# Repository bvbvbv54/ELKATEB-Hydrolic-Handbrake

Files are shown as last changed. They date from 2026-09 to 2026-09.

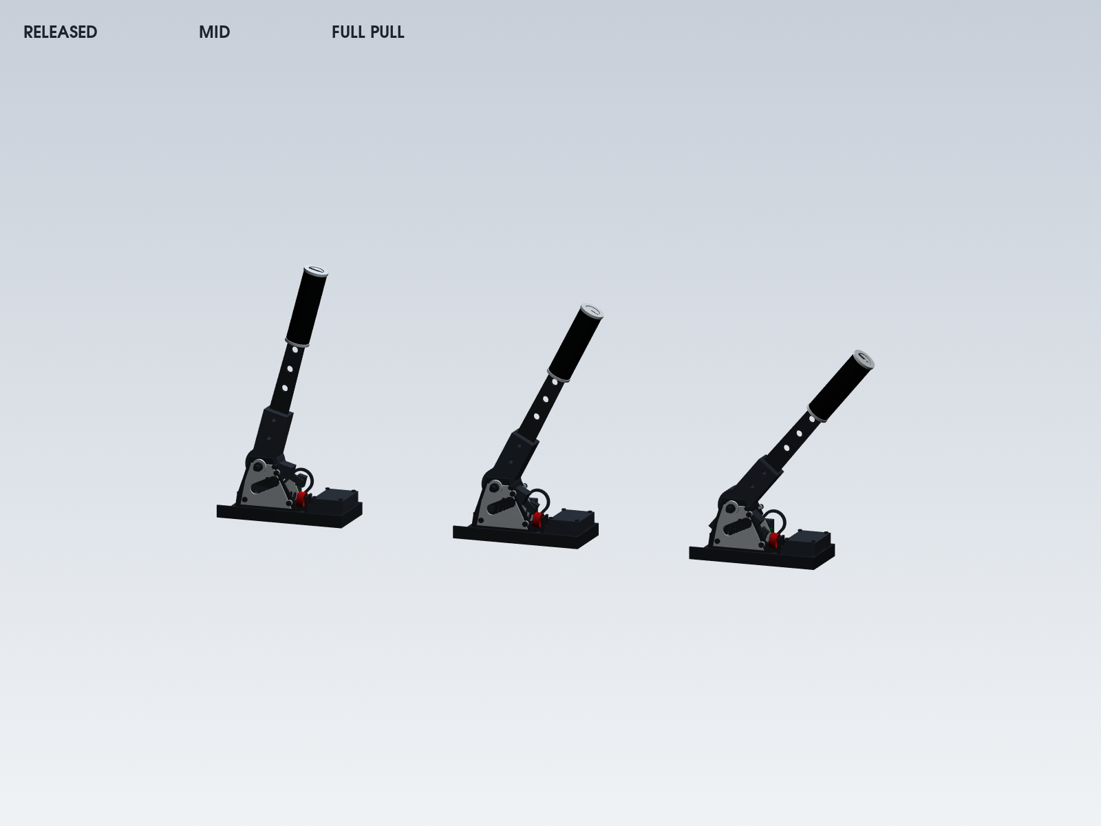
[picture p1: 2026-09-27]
prototype_commercial_v1/renders/17_MOTION_STATES.png

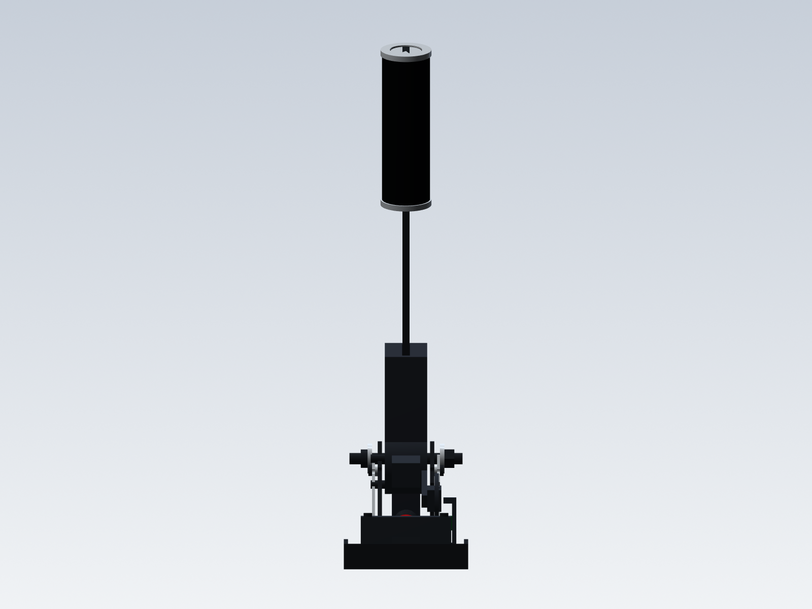
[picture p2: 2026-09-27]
prototype_commercial_v1/renders/06_REAR.png

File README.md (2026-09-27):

# ELKATEB Sim-Racing Handbrake

Original low-cost sim-racing handbrake development project using a dual-608/M8 pivot, steel lever, extension spring, independent mechanical stops, and contactless Hall-effect position sensing.

## Current designs

- `prototype_p1/` - mostly 3D-printed physical validation prototype. Print and measure the eight calibration coupons before regenerating structural parts.
- `prototype_commercial_v1/` - P1-C Commercial Alpha using laser-cut/bent steel, aluminium accents, hidden magnetic sensing, removable desk clamp, and independent rig mounting.
- `analysis_generated/` - evidence-based engineering audit and reusable measurements. Downloaded reference CAD is deliberately excluded from this repository because its redistribution/commercial rights were not established.

## P1 build order

1. Print all eight files under `prototype_p1/coupons/`.
2. Measure the actual bearings, bolts, nuts, magnet, sensor board, and printed coupon fits.
3. Update calibration-dependent parameters in `prototype_p1/src/parameters.py`.
4. Regenerate P1.1 with `prototype_p1/build.ps1`.
5. Print the 19 functional parts and assemble them with the specified steel lever, reinforcement strips, bearings, and metric hardware.

P1.0 and P1-C are engineering prototypes. CAD checks do not establish production strength, fatigue life, electrical compliance, or commercial safety. Follow the included test plans and perform progressive physical validation.

Purchasing documents:

- Short shop-ready list with totals and coupon folder: `output/pdf/P1_BUY_LIST_SUMMARY_TUNISIA.pdf`
- Detailed Tunisia purchasing/calibration guide: `output/pdf/P1_TUNISIA_PURCHASE_GUIDE.pdf`

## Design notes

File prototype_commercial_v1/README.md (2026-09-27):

# P1-C Commercial Alpha

Original cost-conscious commercial prototype derived from the P1.0 engineering baseline and the three user-supplied concept renders. P1.0 is preserved; `2739` files are recorded by SHA-256 in `reports/p1_baseline_hashes.json`.

Core envelope: **190 × 88 mm base**, M8 pivot at **X58 / Z76 mm**, 25° lever travel, two 608 bearings, 5 mm steel lever, 3 mm steel chassis, 2 mm aluminium accents, removable M10 desk clamp, and independent M6 rig slots.

Build with `./build.ps1`. The source of truth is `src/parameters.py`.

Status: CAD VERIFIED where shown. Manufacturing fits, magnetic response, finish, stiffness, fatigue, and clamp holding remain PHYSICAL TEST REQUIRED / SUPPLIER QUOTE REQUIRED.

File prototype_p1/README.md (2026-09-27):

# Prototype P1.0 — printable mechanical validation platform

P1.0 is an original, low-cost vertical/diagonal sim-racing handbrake prototype. It is a mechanical test platform, not a production-ready consumer product. The generated B-Rep assembly uses a drilled steel lever, a fixed M8 pivot, two 608 bearings, a simple extension spring, independent mechanical stops, a moving magnet with stationary Hall board, independent rig slots, and a removable M10 desk clamp.

## Start here

1. Inspect `renders/01_ISOMETRIC_ASSEMBLY.png`, `renders/08_PIVOT_SECTION.png`, and `step/P1_ASSEMBLY.step`.
2. Print the eight `coupons/*.stl` files before structural parts.
3. Measure the actual 608 bearings, steel bar, magnet, M8 bolt shank, coupling nut, sensor board, and Pro Micro assembly.
4. Record the coupon selections and update `src/parameters.py`.
5. Regenerate with `powershell -ExecutionPolicy Bypass -File prototype_p1/build.ps1`.
6. Print the mechanical core before the clamp or electronics modules.

The generated geometry passed the checks in `reports/GEOMETRY_VALIDATION.md` and the 90-file round-trip in `reports/EXPORT_ROUNDTRIP.md`. Printed strength and fit remain physical-test items.

## Actual P1.0 geometry

- Base: 180 x 84 x 10 mm.
- Pivot centre: X=50, Y=42, Z=76 mm in the assembly coordinate system.
- Tower inner gap: 32 mm; each tower is 18 mm thick; outer span is 68 mm.
- Rotating hub: 28 mm axial width, 48 mm bearing barrel diameter, two 22.2 x 7.2 mm nominal pockets.
- Bearings: 2 x 608, 8 x 22 x 7 mm; two more are recommended as fit/test spares.
- Pivot: M8x90 candidate. The smooth shank must cover both bearing inner races; verify the purchased bolt.
- Steel lever: 25 x 5 x 280 mm stock; pivot-to-grip-centre lever arm is 245 mm.
- Released/mid/full angles: 75 / 62.5 / 50 degrees, giving 25 degrees active travel.
- Grip: 34 mm diameter x 110 mm long.
- Spring hook-centre distances: 69.76 / 77.97 / 85.82 mm through the three states.
- Hall centre distance: 23.99 / 12.63 / 5.02 mm; the magnet approaches monotonically toward full pull.
- Electronics enclosure: 50 x 38 x 28 mm body plus 5 mm cover envelope.
- Rig slots: two 44 x 7 mm longitudinal slots, centred at X=136 and Y=32/52 mm.
- Clamp: 60 mm throat, M10x100 screw candidate, 10–55 mm desk range, 46 mm lower pad.
- Released unclamped assembly envelope: 180 x 96 x 370.18 mm including protruding hardware.
- Full-pull unclamped envelope: 255.86 x 96 x 316.74 mm.

## Parts to print

|ID|Part|Recommended orientation|Support guidance|
|---|---|---|---|
|P1-001|Base|top face on bed; steel recesses upward|none|
|P1-002|Left pivot support|outer Y face on bed|none; ream holes after print|
|P1-003|Right pivot support|outer Y face on bed|none|
|P1-004|Bearing hub|one bearing face on bed|support only inside accessible lever slot if bridging is poor|
|P1-006|Grip|upright on end with brim|none; drill/ream retaining bore|
|P1-007|Spring anchor module|foot on bed|none|
|P1-008/009|Stop blocks|outer Y face on bed|none|
|P1-010|Magnet holder|inner arm face on bed|small local support may be required at cup|
|P1-011A/B|Hall bracket and sled|largest flat face on bed|inspect rail bridges|
|P1-012|Electronics enclosure|bottom on bed|none|
|P1-013|Electronics cover|outer top face on bed|none|
|P1-020|Clamp interface|large face on bed|none|
|P1-021|Clamp vertical bracket|large X face on bed|none; orient ribs upward|
|P1-022|Clamp screw guide|lower arm face on bed|none; hex pocket vertical|
|P1-023|Clamp knob|flat face on bed|none|
|P1-024|Swivel-pad holder|flat face on bed|none|
|P1-025|Upper-pad holder|large face on bed|none|

Initial slicer baseline: PETG, 0.4 mm nozzle, 0.20 mm layer, 5–6 perimeters, 6 top/bottom layers, 40–60% infill. Use higher local wall count around pivot, stop, spring, and clamp bores. Do not substitute 100% infill for correct orientation and hardware.

## Steel fabrication

### Lever P1-005

Cut 25 x 5 mm steel flat bar to 280 mm. Hole centres are measured from the lower raw-bar end and across the 25 mm width centreline:

- X=16 mm: Ø6.6 mm, first hub clamp bolt.
- X=40 mm: Ø6.6 mm, second hub clamp bolt.
- X=190 mm: Ø4.5 mm, grip retaining bolt.

Use `dxf/P1-005_STEEL_LEVER_TEMPLATE.dxf` or `drawings/P1-005_STEEL_LEVER_DIMENSIONS.svg`. Deburr every edge and hole. Confirm actual bar width/thickness before printing P1-004 and P1-006.

### Backing strips P1-030/P1-031

Cut two strips, each 180 x 25 x 3 mm. Drill Ø6.6 mm holes at X=32, 68, 125, and 165 mm on the 12.5 mm centreline. These strips sit in the base underside recesses and carry the pivot-tower and clamp-interface through-bolts.

## Assembly order

1. Fit the two steel backing strips into the base underside recesses.
2. Through-bolt both pivot supports to the base/backing strips; do not crush PETG.
3. Press or slip-fit one 608 into each open hub face according to the coupon result.
4. Place the 13.6 mm centre spacer between inner races. Build a measured 2.2 mm axial spacer stack between each tower and adjacent inner race; use steel washers plus precision shims or cut spacer tubes, not PETG.
5. Insert the steel lever 56 mm into the hub socket and install two M6 through-bolts with washers and nylocs.
6. Install the M6 moving spring pin and M6 stop pin in the hub.
7. Put the hub between towers. Pass the M8 smooth shank through left tower, washer, first bearing, spacer, second bearing, washer, and right tower. Tighten the nyloc only enough to clamp the inner-race stack without tower distortion.
8. Bolt on both stop blocks and adjust their M6 rubber-tipped screws to touch the stop pin at 75° and 50°.
9. Bolt the spring module to the base. Install a light extension spring between steel anchors only after the no-spring motion test passes.
10. Slide the grip over the bar and retain it with the M4 cross-bolt.
11. Install the magnet carrier and keeper screw. Keep the magnet out during first mechanical load tests.
12. Install the Hall fixed bracket, sliding sled, and board. Start at 5 mm nominal face gap.
13. Install the Pro Micro enclosure and route the Hall cable away from moving parts.
14. For desk mode, attach the clamp interface with four M6 through-bolts, join the vertical bracket and screw guide, insert the real M10 coupling nut/screw, then fit pad and knob.
15. For rig mode, remove the entire clamp and use the two 44 x 7 mm base slots with large washers.

## First mechanical test

Move the core by hand with no spring and no electronics. Confirm free bearing rotation, positive stop contact, and no bar/tower contact. Add the lightest spring. Use a luggage scale at grip centre and step through 25, 50, 75, then 100 N while inspecting the items in `TEST_PLAN.md`. Stop immediately at cracking, whitening, permanent movement, or fastener loosening.

## Regeneration

CadQuery 2.8 and its small Python dependencies are project-local under `.tools/`; OpenCascade and analysis libraries are reused read-only from `analysis_generated/python_packages`.

```powershell
powershell -ExecutionPolicy Bypass -File prototype_p1/build.ps1
```

The source of truth is `src/parameters.py`. Do not edit exported STEP/STL files by hand.

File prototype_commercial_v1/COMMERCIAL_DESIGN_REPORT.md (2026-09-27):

# Commercial design report

## Executive result

P1-C replaces the printed P1 chassis with a sheet-metal architecture while preserving its proven kinematic principles. The visible product is black powder-coated steel, brushed aluminium, a black grip, and one red spring collar. Internal printed parts are serviceable and visually screened.

## Final CAD dimensions

- Base: 190 × 88 × 18 mm folded envelope.
- Complete released-state CAD envelope: 190 × 88 × 371.4 mm.
- Complete full-pull CAD envelope: 265.3 × 88 × 318.2 mm; the grip sweeps beyond the base length.
- Pivot centre: X58, Y44, Z76 mm.
- Side-frame inner gap: 34 mm.
- Rotating hub: 30 mm wide, Ø50 mm main body.
- Bearings: 2 × 608, nominal 8 × 22 × 7 mm.
- Lever: 5 mm steel, 300 mm pivot-to-end, three Ø10 lightening holes outside the root; nominal hand radius 245 mm.
- Grip: Ø34 × 112 mm over Ø22 mm core.
- Travel: 75° released to 50° full pull.
- Desk range: 10–55 mm; clamp throat 65 mm; M10 × 120 candidate.
- Electronics pod: 54 × 64 × 30 mm nominal outer envelope.

## Materials and processes

- Steel: base tray, left/right structural frames, lever, spring bracket, clamp bracket.
- Aluminium: left/right non-structural accent panels; commodity grip core representation.
- Printed: hub, magnet carrier, Hall window, Hall sled, electronics pod/lid, cable guide, knob, pad carrier, spring collar.
- Purchased: pivot bolt, bearings, spacers/washers, spring, grip, M3/M4/M6 hardware, M10 clamp hardware, magnet, Hall board, controller, USB.

## Mass and sheet use

- CAD steel mass: 1480 g.
- CAD aluminium mass: 27 g.
- Printed solid-volume reference mass: 266 g; actual sliced mass will be lower and profile-dependent.
- Purchased hardware planning allowance: 430 g.
- Estimated assembled mass: 2203 g.
- Steel net area per unit: 0.06284 m²; about 23 units per 1000 × 2000 sheet at 75% planning utilization.
- Aluminium net area per unit: 0.00504 m²; about 297 units per sheet at the same planning utilization.

## Pivot arrangement

M8 partial-thread bolt through 3 mm steel side frames, 2 mm external spacers, two 608 inner races, and a 15.6 mm inner-race spacer. The 30 mm carrier holds two 7.2 mm-deep pockets. Smooth shank must cross both inner races; purchased bolt shank length is MEASURE BEFORE BUILD.

## Spring and stops

One extension spring connects an M6 moving hub anchor at 45 mm radius to a three-position M6 steel anchor near X123/Z25. Spring length is 77.0 mm released, 86.5 mm mid, and 95.4 mm full. Two tangent M6 stops define endpoints independently from sensing.

## Magnetic system

The magnet follows a 55 mm radius and approaches a fixed Hall position monotonically: 24.553, 18.896, 13.394, 8.483, 6.0 mm at 0/25/50/75/100%. The right steel frame has a 38 mm capsule window around the full path; a plastic insert and aluminium outer layer preserve local non-ferromagnetic packaging. Exact field linearity is MAGNETIC-FIELD TEST REQUIRED.

## Clamp and rig mounting

The removable two-bend 3 mm steel bracket carries clamp load into four M6 base bolts. A captured/welded M10 coupling nut carries thread load. Printed parts only form the knob and pad carrier. Two 44 × 7 mm rig slots remain independent.

## Cost status

At quantity 25, the planning direct-material/component subtotal excluding assembly and packaging is **87.8 TND**, and the full planning allowance is **100.8 TND**. These are ESTIMATED/UNKNOWN_RFQ planning values, not Tunisian quotes. At 150–200 TND retail, this alpha is only plausible near the upper end unless local sheet-processing and electronics quotes beat the allowances.

## P1C-MID and P1C-PRO

MID uses powder-coated steel, brushed flat accents, commodity grip, PETG/ASA internal parts, standard 608 bearings, and Pro Micro/custom low-cost PCB. PRO retains the same tray, pivot, Hall system, clamp and mounting, then upgrades grip, accent finish/thickness, fastener finish, spring adjustment, sealed bearings, and PCB/USB module. It is not a second unrelated product.

## Required validation

No safety factor or production claim is made. Test pivot wear, lever proof load, frame spreading, base bending, stop impacts, spring fatigue, clamp slip, desk marking, Hall monotonicity near steel, USB cable retention, and finish durability before sale.

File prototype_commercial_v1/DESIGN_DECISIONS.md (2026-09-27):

# Design decisions

## P1.0 to P1-C design map

|Disposition|P1.0 principle/component|P1-C implementation|
|---|---|---|
|Retained|M8 pivot + two 608 bearings|Same bearing architecture inside a hidden 30 mm carrier; 34 mm steel-frame gap|
|Retained|75° to 50° motion|Released, 25%, mid, 75%, and full CAD states|
|Retained|Steel lever load path|Original tapered 5 mm laser-cut mild-steel lever|
|Retained|Extension spring + independent stops|Commodity spring, M6 steel anchors, two replaceable M6 stops|
|Retained|Moving magnet / fixed Hall|Protected non-ferromagnetic window and adjustable 3–15 mm sled|
|Retained|M10 clamp and rig mount|Removable bent-steel C bracket plus independent M6 rig slots|
|Redesigned|Printed base and towers|190 × 88 mm 3 mm bent-steel tray and two bent-steel side frames|
|Redesigned|Straight 25 × 5 bar|Tapered profile with three Ø10 controlled apertures outside the root section|
|Redesigned|Separate electronics box|Tapered removable rear equipment pod integrated into silhouette|
|Hidden|Hall sled, carrier, wires, PCB, stops|Located behind side layers and removable pod/cover|
|Real structural visual part|Black side body|Powder-coated 3 mm steel frames and tray|
|Low-cost visual part|Silver machined-looking layer|Two flat 2 mm brushed-aluminium non-structural accent panels|
|Rejected|Hydraulic/red damper|Red spring collar/guide around inexpensive extension spring|
|Rejected|Billet CNC chassis, RGB, many machined caps|Laser cutting, simple bends, standard fasteners, restrained CMF|

## Visual translation

The supplied renders establish the visual hierarchy: a low black base, black inner structure, bright side layers, vertical cylindrical grip, exposed but controlled spring, clean pivot rings, and a rear equipment mass. P1-C implements that hierarchy as real manufacturing layers. The accents remain non-structural so their finish can change without revalidating the primary load path.

The right aluminium accent remains one continuous laser-cut part and covers the sensor zone. The ferromagnetic steel behind it carries the 38 mm Hall window; aluminium is non-ferromagnetic, so the continuous cosmetic layer hides the development hardware without reintroducing steel into the sensing path.

## Cost-reduction pass

The initial concept was reduced to six steel sheet parts, two aluminium parts, ten small printed parts, one commodity grip, one spring, two bearings, and standard metric hardware. Decorative pivot caps, a separate machined spring cylinder, welded cosmetic covers, and a second aluminium chassis layer were removed. The two accents share the same stock and near-identical outline. No CNC billet part is required.

## Confidence language

- CAD VERIFIED: B-Rep geometry, alignment, envelope, or interference checked.
- ANALYTICALLY CHECKED: transparent statics/geometry calculation.
- MANUFACTURING ASSUMPTION: supplier tooling, tolerances, or process pending.
- PHYSICAL TEST REQUIRED: stiffness, wear, fatigue, clamp grip, magnetic response.
- SUPPLIER QUOTE REQUIRED: local cost/availability not confirmed.

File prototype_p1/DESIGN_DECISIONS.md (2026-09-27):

# P1.0 design decisions

## Architecture selected

P1.0 uses a printed modular skeleton around a commodity steel load path. The 25 x 5 mm steel lever transmits torque into a replaceable printed hub with two 608 bearings. A fixed M8 bolt clamps the bearing inner races through a 13.6 mm spacer; the hub and bearing outer races rotate. Separate PETG towers are through-bolted into two recessed 180 x 25 x 3 mm steel strips. This makes the high-load pieces replaceable and avoids printed shafts, printed primary threads, and a monolithic housing.

## Pivot stack

From left to right: M8 bolt head, left tower, measured 2.2 mm steel axial spacer stack, 608 inner race, 13.6 mm steel/aluminium centre spacer tube, second 608 inner race, measured 2.2 mm steel axial spacer stack, right tower, M8 nyloc. The hub contains two open 22.2 x 7.2 mm bearing seats, recessing each 7 mm bearing by 0.2 mm. The three spacer sections carry tightening load through the inner races and prevent binding. The M8x90 candidate is not frozen: confirm its unthreaded shank covers the complete 68 mm tower span and both inner races.

## Lever-hub connection

The lever is not a printed cantilever. A 25 x 5 x 280 mm steel bar enters a 25.6 x 5.6 mm hub socket and is retained by two M6 bolts 24 mm apart. The surrounding PETG clamp block is broad rather than a small tab. Fit depends on real steel stock and printer calibration.

## Spring

One extension spring acts between two steel M6 pins. The moving pin is 38 mm opposite the lever axis; the fixed anchor centre is X=108, Z=23 mm. Hook distance increases from 69.76 to 85.82 mm through the 25° travel. Spring free length, rate, hook style, and safe extension remain MEASURE_BEFORE_PRINT/physical-test items. Three fixed-anchor holes at X=104/108/112 allow small tuning without redesign.

## Mechanical stops

An M6 steel pin at 20 mm radius moves through a clearance arc in the left tower. Two separately printed blocks hold tangential M6 rubber-tipped screws. The stop pin/screw surfaces—not the spring, magnet, Hall board, or enclosure—define 75° release and 50° full pull. The blocks use through-bolts into the tower; no insert carries stop load.

## Hall system

The 10 x 5 x 3 mm block magnet candidate is mechanically captured in a moving cup and retained by an M3 keeper screw; adhesive is optional secondary retention. A low-load arm places it at 55 mm radius, outside the structural tower. The stationary sensor is centred at the full-pull endpoint, so centre distance reduces monotonically from 23.99 to 12.63 to 5.02 mm. A fixed bracket and clamped sled provide 3–15 mm face-gap adjustment. The mechanical stop protects the board.

## Electronics

The 50 x 38 x 28 mm enclosure is in the rear-right bay, away from the pivot and spring path. It has a screw-on cover, rear USB opening, front Hall-cable route, four base bolts, and room for a nominal 40 x 20 x 12 mm Pro Micro envelope. Actual boards/connectors must be measured.

## Clamp

The clamp is a removable three-piece C-frame. A four-bolt interface reacts into the same steel strips as the towers. A butt-bolted vertical bracket transfers load to a lower screw guide. The guide captures a real 30 mm M10 coupling nut; the printed part contains no primary M10 thread. An M10x100 steel screw drives a 46 mm swivel-pad holder. The upper pad is 90 x 62 mm. Static states for 10, 25, 40, and 55 mm desks show complete nut engagement, knob clearance, correct pad contact, and zero fixture collision.

## Rig interface

Two independent 44 x 7 mm slots are centred at X=136, Y=32/52 mm. Clamp bolts are at Y=18/66 mm, so fastener patterns do not coincide. The clamp is removed for rig use.

## Originality and reference use

No reference solid, mesh, sketch, exterior, or coordinate set was reused. References contributed only engineering principles already established in the audit: two-sided bearing support, steel load paths, simple springing, stationary sensor/moving magnet, modular packaging, and the idea of later horizontal/vertical modules. All P1 proportions, parts, interfaces, sensor path, rig pattern, and clamp geometry were created for this project.

## Deliberate P1 limitations

- No load cell, hydraulic cylinder, damper, continuously adjustable lever angle, or final cosmetic shell.
- No claimed PETG safety factor or life rating.
- No exact spring specification before physical testing.
- No final PCB; Pro Micro and SS49E validate the architecture.
- The hub may need local support in the lever slot when printed on a bearing face.
- The commodity swivel-foot interface must be adapted after the purchased item is measured.

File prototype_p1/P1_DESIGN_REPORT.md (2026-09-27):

# Prototype P1.0 mechanical design report

**Status:** generated first CAD iteration for inspection and calibration printing.  
**CAD source:** CadQuery 2.8/OpenCascade B-Rep in `src/`.  
**Validation:** 30 source parts/coupons valid; 15 design checks with 13 PASS and 2 REVIEW; 90 exported files round-trip checked with zero failures.  
**Boundary:** this is an engineering prototype, not a certified product or final commercial design.

## 1. Design overview

P1.0 is an original vertical/diagonal handbrake core optimized for low-cost FDM prototyping. A steel flat-bar lever rotates with a printed bearing hub around a fixed M8 steel pivot. Two 608 bearings isolate rotation from PETG. A single extension spring supplies return force. Two mechanical M6 stop screws define 25° travel independently of the magnet and Hall sensor. The 180 x 84 mm base accepts either a removable desk clamp or two independent rig slots.

The model is deliberately modular. The towers, hub, lever, spring anchor, stops, sensor carrier, electronics box, clamp frame, and grip are separable. This permits cheap failure/fit iterations and later replacement of only the lever/hub module for a horizontal P1-H derivative.

## 2. Architecture

The mechanical load path is:

`hand -> steel lever -> two M6 hub bolts and broad socket -> printed rotating hub -> two 608 outer races -> bearing balls/inner races -> M8 steel pivot and inner spacer -> paired PETG towers -> four M6 through-bolts -> two steel backing strips -> base -> rig bolts or removable clamp -> desk/rig`.

The sensing path is separate:

`low-load hub arm -> mechanically retained magnet -> air gap -> stationary SS49E board -> three-wire cable -> removable Pro Micro enclosure`.

The Hall parts do not carry lever, spring, or stop load.

## 3. Parameter system

All design-driving values are in `src/parameters.py` with one of four classes:

- **VERIFIED:** commodity nominal or explicit approved requirement.
- **ASSUMED_P1:** chosen for this prototype iteration.
- **MEASURE_BEFORE_PRINT:** purchased hardware/stock must be measured.
- **CALIBRATION_DEPENDENT:** select from printed coupons.

`reports/parameters.csv` is the machine-readable parameter table. Important values are base 180 x 84 x 10 mm; pivot (50,42,76); 32 mm inner tower gap; 18 mm towers; hub 28 mm; M8 pivot; 608 bearings; 280 x 25 x 5 mm lever; 75° release; 50° full pull; 55 mm magnet radius; 60 mm clamp throat; and 10–55 mm desk range.

## 4. Load path and simple statics

The hand centre is 245 mm from the pivot. Hand forces of 50/75/100/150 N create 12.25/18.38/24.5/36.75 N.m. If that moment were reacted as an ideal force couple over the 60 mm clamp throat, the corresponding reactions would be roughly 204/306/408/613 N. These figures motivate broad pads, through-bolts, steel strips, and progressive physical tests; they are not clamp-capacity predictions.

For an ideal unperforated 25 x 5 mm bar loaded in its strong 25 mm plane, elementary elastic bending gives approximately 23.5/35.3/47.0/70.6 MPa at those loads. Steel grade, holes, fatigue, out-of-plane loading, and actual stock size are not included. There is no claimed safety factor. See `calculations/LOAD_CALCULATIONS.md`.

PETG strength, creep, interlayer behavior, and print defects make tower/base/stop/clamp capacity **PHYSICAL TEST REQUIRED**.

## 5. Pivot design

The fixed pivot candidate is an M8x90 class 8.8 partially threaded bolt. Its head and nyloc remain outside the 68 mm support span for access. The desired journal is the smooth shank; threads should not run through the bearing inner races. Before structural printing, measure the actual unthreaded length. If it does not cover the complete bearing/washer/tower stack, use an M8 precision shoulder bolt, a suitable longer partially threaded bolt cut to length, or an 8 mm shaft with retained ends.

The support holes are nominal 8.6 mm but CALIBRATION_DEPENDENT. The bolt is fixed by the head/nyloc; the hub rotates on bearings.

## 6. Bearing design

P1-004 contains two co-axial, side-open 22.2 mm diameter x 7.2 mm deep pockets for 608 bearings. The 28 mm hub width leaves a derived 13.6 mm distance between pocket bottoms. A centre metal tube and two equal 2.2 mm outer steel spacer stacks transmit M8 tightening load through the inner races; they prevent the hub or bearing shields from becoming the axial clamp member. The outer stacks must be measured from real washers/shims or cut tube—ordinary washer thickness is not assumed.

The nominal 22.2 mm pocket is not asserted as correct for the available printer. Both 7 mm and 14 mm depth coupon series cover 21.8–22.4 mm. Bearings remain removable from either face after the pivot/towers are separated.

## 7. Lever design

The load-carrying lever is 25 x 5 x 280 mm steel. Its lower end begins at 20 mm pivot radius and enters a 61 mm-long printed socket. Two Ø6.6 holes in the bar at 16 and 40 mm from its lower end align to M6 hub bolts. The bolts are 24 mm apart and the surrounding hub block is 28 mm wide, distributing load better than a single small printed lug.

The grip-retaining Ø4.5 hole is 190 mm from the lower end. DXF and SVG templates are supplied. The bar can be cut/drilled with a hacksaw, drill, file, square, and caliper.

## 8. Grip design

P1-006 is a 34 mm diameter x 110 mm long sleeve over the steel bar. Its 25.6 x 5.6 mm slot is intentionally fit-dependent. A transverse M4 bolt mechanically retains the grip; glue is unnecessary. It should be printed upright with a brim unless the selected printer produces cleaner internal slots horizontally.

## 9. Spring design

P1.0 uses one extension spring between steel M6 anchors. The hub-side anchor is 38 mm opposite the lever axis. The fixed module centre is X=108, Z=23 mm and provides three positions at X=104/108/112. In the nominal centre hole, hook-centre distances are 69.76 mm released, 77.97 mm mid, and 85.82 mm full pull. This provides approximately 16.1 mm working extension before considering hook geometry/preload.

The CAD checks a 15 mm-diameter clearance envelope. Purchase several 15–20 mm OD, 60–100 mm hook-to-hook springs. Free length, initial tension, rate, and allowable extension are not frozen.

## 10. Travel stops

A steel M6 pin at 20 mm radius rotates with the hub through a clearance arc in the left tower. P1-008 and P1-009 mount outside the left tower and carry tangential M6 adjusters with rubber tips. Their positions correspond to 75° and 50°. Hardware contacts are tangent in CAD; locknuts secure the final adjustment. The stop blocks attach with four M4 through-bolts across the 18 mm tower; heat-set inserts do not carry stop force.

The stops are the only intended travel limits. The spring, Hall carrier, magnet, sensor board, enclosure, and USB cable have clearance in all three checked states.

## 11. Hall sensor integration

The moving magnet holder is bolted to the hub by two M3 screws. Its radial arm sits inside the support gap and steps outward only after clearing the right tower. A 10 x 5 x 3 mm candidate magnet fits an outward-opening pocket and is retained by a transverse M3 keeper; adhesive may be secondary retention.

The magnet radius is 55 mm. The board is at the full-pull endpoint, not the travel midpoint. Therefore 3D centre distance reduces monotonically: 23.99 mm released, 12.63 mm mid, 5.02 mm full at the nominal setting. The fixed bracket plus separate sled supports 3–15 mm face-gap experimentation through two clamped rails. Mechanical stops protect the minimum gap.

Physical testing must establish magnet polarity/orientation and whether the SS49E response remains monotonic and sufficiently linear. Record voltages at release/25/50/75/100%.

## 12. Electronics packaging

P1-012 is a 50 x 38 x 28 mm rear-right enclosure with 2.4 mm walls, a rear USB opening, a pivot-facing Hall cable route, and four base mounting holes. P1-013 is a separate four-screw cover with a locating lip. The nominal usable controller envelope is 40 x 20 x 12 mm. Cover inserts are permitted because they are not structural.

The enclosure does not overlap the pivot, spring module, lever sweep, magnet carrier, or primary clamp load path. It removes without disassembling the pivot.

## 13. Base design

P1-001 is a 180 x 84 x 10 mm structural plate. Its underside has two 176 x 25.4 x 3.3 mm open recesses for the steel strips. The base is printed top-face-down so recesses face upward and do not require 25 mm bridges. Four tower holes, four clamp holes, two spring-module holes, two rig slots, electronics holes, and light accessory holes are through features.

The base is separate from towers and clamp; a failed part does not require reprinting a large cosmetic shell.

## 14. Table clamp design

P1-020 is a 64 x 72 x 8 mm interface plate attached by four M6 bolts through the base and steel strips. P1-021 is a 10 mm structural rear wall with side ribs and two butt-bolted joints. P1-022 is a 76 x 32 mm lower arm with a 38 mm-deep boss and a hexagonal pocket for a real M10 coupling nut. P1-023 is a six-lobe knob, P1-024 a 46 mm carrier for a commodity swivel foot/pad, and P1-025 a 90 x 62 mm upper rubber-pad holder.

The screw axis is X=112, 60 mm inward from the desk edge at X=172. The M10x100 candidate spans the complete 30 mm coupling nut in all four checked states. The knob remains below the lower arm. No printed M10 thread carries clamp force.

## 15. Clamp load path

`lower pad -> M10 steel screw -> M10 steel coupling nut -> thick printed screw-guide boss/lower arm -> two M6 butt-joint bolts -> ribbed vertical bracket -> two M6 upper joint bolts -> clamp interface -> four M6 base bolts -> two steel backing strips/base -> upper pad -> desk`.

Static CAD states at 10/25/40/55 mm have exact pad/desk contact and zero overlap. These checks cannot predict rubber friction, desk stiffness, PETG creep, tightening torque, or slip resistance. Test on sacrificial boards first.

## 16. Rig mounting

Rig mode removes P1-020 through P1-025. Two 44 x 7 mm slots run longitudinally at Y=32 and 52 mm, centre X=136 mm. Use M6 bolts with washers at least 18 mm OD. The clamp-bolt axes at Y=18/66 do not coincide with rig slots.

## 17. 3D-print strategy

Baseline is PETG, 0.4 mm nozzle, 0.20 mm layers, 5–6 perimeters, six top/bottom layers, and 40–60% infill. Geometry/through-bolts/steel carry load; 100% infill is not the strategy. Towers print on outer faces so the M8 and stop/hall transverse holes are vertical. The hub prints on a bearing face for round pockets; its accessible lever socket may need local support over a 25.6 mm bridge. The screw guide prints with the coupling-nut pocket vertical.

All exported STLs are watertight. This does not establish dimensional accuracy or printability on a specific machine.

## 18. Metal fabrication

Only three cut/drilled pieces are designed: one 280 x 25 x 5 mm lever and two 180 x 25 x 3 mm backing strips. Supplied DXFs declare millimetres and re-import correctly. All edges/holes must be deburred. No CNC, welding, bending, or custom-turned shaft is required. The 13.6 mm inner-race spacer can be cut from common 8 mm-ID tube or assembled from a measured precision spacer stack, but a single tube is preferred.

## 19. BOM

The purchase list is in `BOM.md`. Core items are two installed 608-2RS bearings plus two spares, M8 pivot hardware, steel lever/strips, an M6 assortment and nylocs, extension-spring assortment, M10x100 screw, M10 coupling nut, commodity swivel pad/foot, rubber pads, magnet, SS49E board, Pro Micro, three-wire connector/cable, and PETG.

## 20. Assembly sequence

Fit strips; bolt towers; install bearings/spacer; bolt lever into hub; install moving spring/stop pins; install hub/M8 stack; install stops; test dry motion; install grip; install light spring; test progressively; only then add magnet/Hall and electronics; add clamp last. The full practical sequence is in `README.md`.

## 21. Required calibration prints

Eight STEP/STL coupon files are supplied: 608 pockets at 7 and 14 mm depth, M8 clearance, M6 clearance, M6 nut traps, magnet pockets, Hall gap jig, and loaded bearing-wall coupon. All are valid single solids and their STLs are watertight. Print these before any structural component.

## 22. Testing procedure

The staged procedure in `TEST_PLAN.md` covers coupons; bearing/hub fit; free pivot; no-spring core; light spring; stops; 25/50/75/100 N progressive loads; 100/500/1000 pulls; rig mode; all four desk sizes; clamp slip/lift; Hall voltages; and later USB HID Slider mapping. A 150 N case is only a later deliberate proof-case consideration.

## 23. Known uncertainties and weak areas

- PETG creep/fatigue at tower roots, hub socket, stop blocks, spring module, and clamp joints.
- Actual 608 press/slip fit and bearing-pocket roundness.
- Actual M8 bolt shank length and inner-spacer length.
- Steel-bar and magnet stock variation.
- Hub lever-slot bridging quality when printed for best bearing accuracy.
- Spring initial tension/rate/hook fatigue and force feel.
- Stop screw/rubber durability and left-tower local load.
- Hall board size, sensing-element position, magnet polarity, and transfer curve.
- Real coupling-nut AF/length and swivel-foot geometry.
- Clamp friction, desk compliance, and printed clamp creep.
- Pro Micro connector location and cable bend radius.

These are deliberately exposed by replaceable parts/coupons rather than hidden by unjustified certainty.

## 24. Measurements required before P1.1

Provide actual 608 OD/width; selected bearing pocket at both depths; printed M8/M6 hole results; selected nut trap; steel bar width/thickness; M8 overall and smooth-shank length; spacer tube ID/OD; exact magnet; Hall PCB and sensing-element location; Pro Micro with headers/USB; M10 coupling-nut AF/length; clamp screw/head; swivel pad interface; selected spring dimensions/forces; actual released/full angles; and all Hall voltage results.

## 25. Horizontal-module and product-family strategy

The future P1-H changes the lever/hub socket orientation and stop locations while retaining base, towers, M8/608 stack, steel strips, rig slots, clamp, electronics enclosure, and stationary Hall-platform concept. It should be a separate bolt-on hub/lever module, not a complex continuously adjustable joint.

For later products, the current platform separates reusable core interfaces from tier-specific features: an entry horizontal lever can use simpler resistance; a mid-range vertical model can improve bearings/spring adjustment/materials; a premium model can add alternate hubs, travel adjustment, stronger metal structures, or later load-cell sensing. None of those variants is being claimed as designed here.

## Export evidence

- `reports/geometry_validation.json`: source-solid dimensions, state checks, distances, clamp states, and envelopes.
- `reports/part_geometry.csv`: machine-readable part dimensions/volume/validity.
- `reports/design_review_checklist.csv`: PASS/REVIEW/FAIL checklist.
- `reports/export_roundtrip.json`: STEP/STL/DXF/PNG re-import results.
- `step/`: individual B-Reps, main assembly, exploded view, three motion states, rig state, and four desk states.
- `stl/`: nineteen printable components.
- `dxf/` and `drawings/`: steel fabrication templates.
- `renders/`: nineteen visual inspection views.

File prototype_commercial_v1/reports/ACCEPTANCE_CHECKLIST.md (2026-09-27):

# P1-C-A1 acceptance checklist

- [x] Original commercial design generated.
- [x] P1.0 left untouched; 2,739 baseline files recorded by SHA-256.
- [x] Visual hierarchy translated from the supplied renders without literal copying.
- [x] Laser-cut/bent steel architecture and strategic aluminium accents.
- [x] Dual-608/M8 pivot, steel lever, spring, independent stops, Hall path, clamp, and rig slots represented.
- [x] Electronics and sensing components integrated and serviceable.
- [x] Released, 25%, mid, 75%, and full motion states collision-checked.
- [x] 10/25/40/55 mm desk states geometrically checked.
- [x] STEP, STL, DXF, SVG, calculations, cost model, RFQ pack, and renders generated.
- [x] Eighteen customer/engineering renders produced from `P1C_ASSEMBLY.step`-equivalent B-Rep revision P1-C-A1.
- [x] Cost-reduction pass completed without changing the primary appearance.
- [x] P1C-MID architecture and shared P1C-PRO upgrade path documented.
- [ ] Supplier bend compensation and local process prices confirmed — SUPPLIER QUOTE REQUIRED.
- [ ] Physical strength, fatigue, clamp, finish, and magnetic-field behavior validated — PHYSICAL TEST REQUIRED.
- [ ] Production safety or durability certification established — not claimed.

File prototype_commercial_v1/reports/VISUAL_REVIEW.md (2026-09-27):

# P1-C-A1 visual reality review

## Geometry authority

All delivered PNGs are tessellated from the CadQuery B-Rep used to export `step/P1C_ASSEMBLY.step`. No image-generation model, painted-in fastener, or invented body panel is used. The neutral CAD views are intentionally less photorealistic than concept art, but preserve exact panel thicknesses, fastener positions, seams, spring position, mounting slots, and proportions.

## What is structural

- P1C-S001 folded 3 mm steel tray.
- P1C-S002 and P1C-S003 formed 3 mm steel side frames.
- P1C-S004 5 mm steel lever.
- P1C-S005 spring bracket and P1C-S006 removable clamp bracket.
- M8 pivot, dual 608 bearings, M6 steel anchors/stops, and standard hardware.

## What is cosmetic or non-structural

- P1C-A001/A002 2 mm brushed-aluminium accents.
- Aluminium grip trim rings and the short dark-red printed spring collar.
- Printed electronics lid and covers. The electronics pod protects components but is not in the primary hand-load path.

## Accent attachment

Each aluminium accent is mounted proud of its steel frame on 2 mm spacers using three M4 black button-head screws. The installation view displaces the accents and screws only along their real assembly axes. The accents do not carry pivot or spring load.

The right accent is a continuous one-piece aluminium panel. It cosmetically covers the Hall zone; the required capsule window is in the ferromagnetic steel frame behind it. This keeps the visible accent manufacturable and the local sensing layer non-ferromagnetic.

## Customer-visible mechanism

The customer sees the black steel frame, brushed aluminium accents, M8 pivot trim, three lever apertures, commercial-grip envelope, black extension spring, short red guide collar, rear pod, base slots, and consistent black fasteners. The hub, Hall sled, magnet carrier, Hall board, cable guide, stop contact geometry, and controller remain screened or internal.

## Weaknesses found and disposition

1. Early Hall close-ups hid the air gap in projection. The final view is aligned with the X axis and shows the magnet/board separation without changing CAD.
2. Early context framing made the product too small. The final context uses translucent generic unbranded fixtures and focuses on the exact assembly.
3. The concept-art expectation exceeds the available local renderer. The delivered images are exact-CAD material renders rather than generative photorealism; this avoids geometry hallucination.
4. The strict full-height rear view necessarily makes the 54 × 64 × 30 mm pod visually small relative to the 300 mm lever. The orthographic rear image remains dimensionally honest.

## Physical reality still requiring validation

Powder-coat texture, aluminium brushing, panel-gap appearance after bending, purchased-grip surface, spring appearance, fastener coatings, formed-part alignment, and magnetic response near the steel chassis must be checked on a fabricated alpha.

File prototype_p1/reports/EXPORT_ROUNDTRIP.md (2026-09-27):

# Export round-trip verification

Files checked: **90**. Failures: **0**.

|Format|Files|Valid|
|---|---:|---:|
|STEP|41|41|
|STL|27|27|
|DXF|3|3|
|PNG|19|19|

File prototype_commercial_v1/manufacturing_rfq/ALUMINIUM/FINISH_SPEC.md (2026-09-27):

# Aluminium finish

Two 2 mm non-structural accents per unit. Directional brush parallel to the long axis, consistent left/right grain, clear protective finish or separately quoted silver powder coat. Quote 1/5/10/25/50 pairs.

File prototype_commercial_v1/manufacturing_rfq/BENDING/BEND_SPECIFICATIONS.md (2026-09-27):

# Bend specification

All dimensions are mm. Nominal bends are 90° with 3 mm inside radius. DXF flat patterns are quotation geometry; supplier must apply bend deduction/K-factor for actual tooling and return a compensated production flat for approval.

|Part|Material|Thickness|Bends|
|---|---|---:|---|
|P1C-S001 base tray|Mild steel|3.0|Two 190 mm side bends + one 88 mm rear bend, flanges up|
|P1C-S002/S003 side frames|Mild steel|3.0|One 96 mm foot bend each, feet outward|
|P1C-S005 spring bracket|Mild steel|3.0|One 24 mm bend|
|P1C-S006 clamp bracket|Mild steel|3.0|Two 68 mm bends forming C bracket|

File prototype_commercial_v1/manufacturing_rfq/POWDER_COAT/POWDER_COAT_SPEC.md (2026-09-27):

# Powder-coat RFQ

Parts: P1C-S001 through P1C-S006. Finish: satin/matte black, consistent batch colour. Deburr first. Mask M8 pivot bores, close-fit interfaces and any installed threads. Quote 1/5/10/25/50 sets, pretreatment, coating thickness range, lead time and minimum batch charge.

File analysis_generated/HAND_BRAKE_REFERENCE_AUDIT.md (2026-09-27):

# Hand Brake Reference CAD Engineering Audit

**Audit date:** 2026-09-26  
**Scope:** read-only investigation of five extracted reference packages; no source CAD changed and no new product CAD created.  
**Primary machine-readable evidence:** `analysis_generated/model_inventory.csv`, `analysis_generated/measurements.csv`, `analysis_generated/hardware_candidates.csv`, and `analysis_generated/geometry_findings.json`.

## Evidence and confidence rules

- **VERIFIED** - read directly from documentation or measured from neutral CAD/mesh geometry by a real parser.
- **DERIVED** - calculated from VERIFIED values; the calculation is identified.
- **ESTIMATED** - visual/engineering interpretation that is not a defined CAD dimension.
- **UNKNOWN** - unavailable from the supplied evidence or the available tools.

The audit used OpenCascade 7.9.3.1 for STEP/IGES B-Rep import, XCAF for STEP occurrence names, `trimesh` for STL integrity, `ezdxf` for DXF entities/units, `olefile` for SolidWorks container metadata and embedded previews, and Poppler/PyPDF for the fabrication PDF. No proprietary SolidWorks B-Rep reader was available. Therefore, the Chinese generic `.SLDPRT`/`.SLDASM` geometry was **not** dimensionally analyzed. Embedded SolidWorks preview PNGs are treated as visual metadata, never as dimensional CAD evidence.

## 1. Executive summary

Do **not** print any complete reference package immediately.

- The **DIY v1.2** package is the strongest engineering reference and the closest mechanical starting point. It supplies a valid 139-solid STEP assembly with 90 named occurrences, mm DXFs, ten watertight printed parts, a fabrication PDF, hardware list, and an AS5600 sensor PCB. Its best principles are paired side plates, compact real bearings, metal load paths, stationary sensor PCB/moving magnet, and rig slots. It is too expensive and complicated for P1 as a whole: it uses ten 3 mm cut-metal pieces, four F696ZZ bearings, a PHS8 rod end, a damper, a compression spring, and a large fastener count.
- The **Chinese generic** reference has the simplest visible spring/yoke architecture and a protected PCB compartment, but it is SolidWorks-only. Geometry, fits, dimensions, occurrence counts, and material thicknesses are UNKNOWN. It cannot be trusted as a printable dimensional source in this environment.
- The **Fanatec reference** gives the cleanest horizontal/vertical packaging precedent. Its two valid STEP configurations have four solids and a compact 154 x 61.5 x 76 mm base, but they omit useful internal mechanism detail. It is an exterior/configuration reference, not a manufacturing design.
- The **hydraulic reference** has the strongest visibly defined metal load path: an 8 mm lever plate, an 8 x 27 mm steel pivot pin, and paired flanged bushings inside a bent sheet base. Its custom hydraulic cylinder, piston, linkage, bushings, and metal fabrication are wrong for a low-cost P1.
- The **MOZA low-poly reference** is one fused solid. The STEP and STL are geometrically clean and agree in scale, but no functional components can be recovered. It is useful only for a rough vertical ergonomic envelope, not mechanics or manufacturing.

Recommended P1 is an original mixed architecture: a mostly printed modular base/support structure, a single low-cost drilled steel flat-bar lever, a fixed M8 steel pivot through two real 608 bearings housed in a replaceable printed lever-root hub, a simple extension spring with steel anchors, a moving neodymium magnet and stationary adjustable SS49E sensor board, a separate Pro Micro enclosure, independent rig holes, and a removable steel-screw desk clamp. Validate one vertical/diagonal configuration first; retain a bolt-on lever interface that can support a later horizontal variant. Do not add hydraulic parts, a damper, load cell, or a complex adjustable linkage to P1.

An example load only: 100 N applied 0.22 m from the pivot produces **22 N·m**. This is a torque illustration, not a safety factor or FEA result. Geometry and load paths still require physical proof testing.

## 2. Workspace inventory

### Important file tree

```text
chinese-generic-sim-handbrake-model-1.snapshot.1/
  Chinese handbrake assembly.SLDASM                 main assembly candidate
  Chinese handbrake handle assembly.SLDASM          handle subassembly
  Chinese handbrake PCB assembly.SLDASM             electronics subassembly
  Chinese handbrake yoke assembly.SLDASM            spring/yoke subassembly
  Chinese Handbrake side wall.SLDPRT
  Chinese Handbrake Lower Handle.SLDPRT
  Chinese Handbrake UpperHandle.SLDPRT
  Chinese Handbrake reaction plate.SLDPRT
  Chinese Handbrake spring.SLDPRT
  Chinese Handbrake PCB.SLDPRT / PCB cover.SLDPRT
  ...32 SLDPRT and 4 SLDASM total

fanatec-handbrake-1.snapshot.1/
  FANATEC Handbrake down.step                        neutral assembly/configuration
  FANATEC Handbrake up.step                          alternate configuration
  FANATEC Handbrake v2.f3d                           native Fusion archive

handbrake-for-sim-racing-diy-1.snapshot.48/
  STEP and Parasolid/hand brake v1.2.stp             main neutral assembly
  STEP and Parasolid/*.x_t                           Parasolid duplicate; not parsed
  HB1.jpg / HB2.jpg / HB3.bmp                        renders and dimensioned overview
  Cutting; flexion; electronics and information/
    fasteners and accessories.png                    21-line hardware list
    printed parts/*.stl                              10 printable parts
    сutting 3mm/hand brake v1.1 (250x200).dxf        nested sheet
    сutting 3mm/Plates separately/*.dxf              7 plate definitions
    сutting 3mm/hand brake v1.1 info.pdf              3 mm sheet nesting report
    electronics/AS5600_analog_pcb/                   Gerbers, BOM, PnP, images

hydraulic-handbrake-1.snapshot.2/
  Handbrake.stp                                      main neutral assembly
  Handbrake/Handbrake.SLDASM                         native assembly
  Handbrake/*.SLDPRT                                 12 native parts
  Handbrake/IGS/*.IGS                                9 neutral part exports
  Handbrake/DWG/*.DWG                                9 drawings; not parsed
  Handbrake/SolidWorks_Draw/*.SLDDRW                 9 native drawings
  Handbrake/Web/*.jpg                                part renders/drawing previews

moza-hbp-handbrake-low-poly-1.snapshot.1/
  MOZA HBP Handbrake Low Poly.step                   single-solid neutral model
  MOZA HBP Handbrake Low Poly.stl                    matching mesh
```

### File totals

| Project | Files | Engineering formats |
|---|---:|---|
| Chinese generic | 36 | 32 SLDPRT, 4 SLDASM |
| Fanatec reference | 3 | 2 STEP, 1 F3D |
| DIY v1.2 | 31 | 1 STEP, 1 Parasolid, 10 STL, 8 DXF, 1 PDF, 2 CSV, 2 Gerber ZIPs, images |
| Hydraulic | 71 | 1 STEP, 1 SLDASM, 12 SLDPRT, 9 IGES, 9 DWG, 9 SLDDRW, 30 JPG |
| MOZA low-poly | 2 | 1 STEP, 1 STL |

No README, LICENSE, COPYING, or explicit commercial-use grant was found in any package. SHA-256 hashes for every source file are in `analysis_generated/model_inventory.csv`.

## 3. Model 1 audit - Chinese generic sim handbrake

**MODEL:** Chinese generic sim handbrake  
**SOURCE FILE(S):** `Chinese handbrake assembly.SLDASM`, 3 subassemblies, 32 SLDPRT definitions  
**GEOMETRY SOURCE USED:** SolidWorks OLE metadata and embedded preview PNG only; proprietary B-Rep not parsed  
**CONFIGURATION:** horizontal  
**OVERALL DIMENSIONS:** UNKNOWN  
**LEVER:** two-piece metal-looking lower/upper handle; exact length/thickness UNKNOWN  
**PIVOT:** filename evidence includes M8 bolts, bush/bushing, plastic washers, circlip, and cotter pin; exact arrangement UNKNOWN  
**BEARINGS/BUSHINGS:** bushes are modeled; no named rolling bearing  
**SPRING SYSTEM:** visible compression spring captured by a yoke/reaction-plate system  
**BASE:** plate-and-side-wall metal-looking enclosure  
**FASTENERS:** unique definitions include M3, M5, and M8 families; assembly quantities UNKNOWN  
**SENSOR:** separate PCB and PCB-cover subassembly; sensor type UNKNOWN  
**PCB SPACE:** protected rear/side rectangular cover visible in embedded preview  
**PRINTED PARTS:** none supplied as STL; no evidence it was designed for FDM  
**METAL PARTS:** appears predominantly plate/turned hardware, but material metadata was not established  
**CLAMP COMPATIBILITY:** possible external under-base module; base geometry and strength UNKNOWN  
**RIG MOUNTING:** holes/slots are visible in previews, but sizes/spacing UNKNOWN  
**MAJOR WEAK POINTS:** likely bolt/bushing wear, possible plastic washer creep, thin plate around slots, and cantilevered long lever; cannot be dimensionally verified  
**USEFUL DESIGN PRINCIPLES:** simple axial compression spring/yoke, horizontal package, discrete electronics cover, replaceable fasteners  
**UNKNOWNS:** all dimensions, fits, materials, occurrences, sensor method, spring rate, travel, and actual clearances  
**CONFIDENCE:** architecture ESTIMATED from embedded preview and filenames; part-file inventory VERIFIED; geometry UNKNOWN

### Mechanism and DFM assessment

The embedded main-assembly preview shows a long horizontal lever rotating between two side structures. A compression spring sits in a compact yoke below/behind the pivot and reacts into a separate plate. That is a mechanically simple way to create return force without a gas damper or hydraulic system. The filenames `Chinese Handbrake bush.SLDPRT`, `handle bush`, `plastic washer`, and M8 pivot hardware indicate a bushed bolt pivot, not a rolling-bearing pivot. This is less desirable for repeated cycling than a steel shaft supported by bearings.

The main parts look like machined/laser-cut metal plates. Printing the thin lever and side walls directly in PETG would not preserve the original load path. The long handle, abrupt bends near the lever root, slots, and bolt holes are potential stress concentrators. No strength conclusion is possible without B-Rep dimensions, material, and testing.

Hall adaptation is feasible in principle: attach a magnet to the rotating lower handle and a stationary sensor board to one side wall. The existing separate PCB cover is the best packaging principle in this model. Exact gap, travel, and bracket clearance are UNKNOWN.

### Dimensional trust verdict

**Do not manufacture or print from this package without opening it in a real SolidWorks-compatible B-Rep system and measuring it.** Filenames are not dimensions and embedded previews are not metrology.

## 4. Model 2 audit - Fanatec reference

**MODEL:** Fanatec handbrake reference  
**SOURCE FILE(S):** `FANATEC Handbrake down.step`, `FANATEC Handbrake up.step`, `FANATEC Handbrake v2.f3d`  
**GEOMETRY SOURCE USED:** both STEP B-Reps; F3D archive metadata/thumbnail only  
**CONFIGURATION:** horizontal and vertical/up configurations  
**OVERALL DIMENSIONS:** VERIFIED down 424.000 x 64.687 x 118.000 mm; VERIFIED up 213.373 x 64.687 x 328.627 mm  
**LEVER:** VERIFIED 4.000 mm thick solid; approximate pivot-to-grip centroid DERIVED about 224 mm  
**PIVOT:** concentric VERIFIED 7/8/12 mm cylindrical features at the candidate pivot/boss; hardware standard not documented  
**BEARINGS/BUSHINGS:** UNKNOWN; no recoverable named internals  
**SPRING SYSTEM:** UNKNOWN; not modeled  
**BASE:** VERIFIED 154.000 x 61.500 x 76.000 mm envelope across the two unchanged base solids  
**FASTENERS:** holes/bosses modeled, no BOM or named hardware  
**SENSOR:** UNKNOWN; not modeled  
**PCB SPACE:** enclosed base could contain electronics, but usable cavity geometry was not separated  
**PRINTED PARTS:** none identified as print-ready  
**METAL PARTS:** exterior resembles thin formed/cut metal and molded grip; exact materials UNKNOWN  
**CLAMP COMPATIBILITY:** removable under-base adapter is possible, but only 61.5 mm base width limits clamp-bolt spacing  
**RIG MOUNTING:** some base/side holes are modeled; exact intended mounting pattern is not documented  
**MAJOR WEAK POINTS:** a 4 mm lever copied in PETG would be structurally poor; internals and stops are absent; exterior geometry cannot establish reliability  
**USEFUL DESIGN PRINCIPLES:** compact rectangular base; bolt-on/reconfigurable lever orientation; separated grip, lever, and base bodies  
**UNKNOWNS:** internal pivot, spring, sensor, stops, bearing arrangement, wall thickness intent, and production tolerances  
**CONFIDENCE:** envelope/topology VERIFIED; mechanism UNKNOWN; configurability VERIFIED as two CAD states but the reconfiguration procedure is not documented

### CAD quality and geometry

Both STEP files declare millimetres and import as valid B-Reps. Each contains four solids, 105 faces, and four shells. The base solids are unchanged between configurations. The grip and lever solids are repositioned. This supports a configuration reference but does **not** prove a continuous actuation range. No travel angle was claimed.

The grip envelope is VERIFIED at 106.000 x 42.375 x 42.375 mm. The lever solid extends about 317 mm overall in the down file because its root and grip-end geometry are included; the meaningful hand lever arm is approximately 224 mm from candidate pivot to grip centroid. This is DERIVED and should not be treated as a production dimension.

### Printability and structural assessment

The STEP is geometrically convertible, but it is not a printable mechanism. The 4 mm lever is consistent with metal sheet, not a safe PETG cantilever at a roughly 0.22 m lever arm. The base solids overlap as an exterior package rather than a documented print assembly. Supports, internal cavities, spring mounts, and electronics mounts are absent.

### Hall and clamp integration

The enclosed base provides a useful packaging volume, but a sensor bracket would need to be created from scratch. A removable clamp could attach below or behind the 154 x 61.5 mm base. Clamp reaction should not be carried by a thin printed copy of the shell.

### Dimensional trust verdict

**Trust the two STEP envelopes as reference geometry, not as a complete product. Do not print it as a working handbrake.**

## 5. Model 3 audit - Handbrake for sim racing DIY v1.2

**MODEL:** hand brake v1.2  
**SOURCE FILE(S):** main STEP, Parasolid duplicate, 10 STLs, 8 mm-unit DXFs, one PDF, hardware-list image, AS5600 PCB files  
**GEOMETRY SOURCE USED:** STEP B-Rep/XCAF, STL meshes, DXF geometry, fabrication PDF, package images  
**CONFIGURATION:** vertical/rally style  
**OVERALL DIMENSIONS:** VERIFIED STEP 165.611 x 84.090 x 302.591 mm; package overview independently calls out 163.24 x 81.06 x 302.57 mm excluding some protrusions  
**LEVER:** two 3 mm side plates plus printed handle; VERIFIED handle envelope 26 x 20 x 122 mm; drawing calls out 116.9 mm handle length  
**PIVOT:** paired bearing axes; primary at x=17.000, z=43.429 mm and secondary near x=97.97, z=54.8 mm in assembly coordinates  
**BEARINGS/BUSHINGS:** VERIFIED four F696ZZ, modeled ID 6, OD 15, flange OD 17, width 5 mm  
**SPRING SYSTEM:** 20 x 51 light compression spring combined with a compact damper/gas-spring-like component, adjustable holes/slots, and PHS8 rod end  
**BASE:** ten pieces of 3 mm cut sheet, including paired plates and bent/flanged base pieces  
**FASTENERS:** extensive M3/M6/M8 hardware; 90 top-level occurrences in STEP  
**SENSOR:** moving 5 x 4 x 2 mm magnet, printed magnet holder, stationary AS5600 analog angle-sensor PCB  
**PCB SPACE:** dedicated 12.616 x 3.116 x 54.016 mm sensor-board assembly envelope; no clear protected main-controller enclosure  
**PRINTED PARTS:** 10 watertight STLs  
**METAL PARTS:** ten 3 mm laser-cut/bent plates plus rod end, bearings, damper, shafts, springs, and fasteners  
**CLAMP COMPATIBILITY:** no desk clamp; `clamp.stl` clamps the resistance component, not a desk  
**RIG MOUNTING:** strong; base flanges visibly include slotted mounting holes  
**MAJOR WEAK POINTS:** high part count, many joints that can loosen, unsupported/protruding sensor PCB, complex resistance linkage, thin printed handle/spacers, BOM inconsistencies  
**USEFUL DESIGN PRINCIPLES:** bearing-supported load path, paired side plates, mm-documented hardware, co-axial contactless sensor, sensor-board slots, steel rig-mounting flange  
**UNKNOWNS:** spring rate, damper force/part specification, exact actuation travel, fits/tolerances, plate material, sensor calibration, and main USB controller packaging  
**CONFIDENCE:** high for geometry and component names; medium for operating behavior because the STEP is static and no assembly-motion study is supplied

### Architecture and dimensions

This is the only package that resembles a complete build package. The STEP declares millimetres, imports as a valid 139-solid assembly, and exposes 90 named occurrences. The 3 mm plate thickness is repeated in B-Rep dimensions and the `сutting 3mm` documentation. The two main `hbplate2` side plates are 3 mm thick, have a DERIVED 26 mm internal gap and 32 mm outer spacing, and surround the principal mechanism.

The primary hand-lever bearing pair centers at approximately x=17, z=43.429 mm. The printed handle center of mass is 182.43 mm from that axis; the far grip end is farther, so actual user leverage varies with hand position. Four F696ZZ flanged bearings form two paired pivots. This is the best pivot implementation in the set.

### Part count and cost drivers

- VERIFIED ten printed STL files: `cap`, `clamp`, `hand rest`, `handle`, `hbha`, `magnet holder`, `rear hub`, `spacer`, `spacer1`, `spacer2`.
- VERIFIED ten nested 3 mm plate pieces in the PDF: two base-side variants, two each of plates 2/3/4, and one each of plates 5/6.
- VERIFIED hardware list includes 14 M6 socket-head screws across five lengths, two countersunk M6 screws, 11 M6 nyloc nuts, M8 hardware, M3 hardware, washers, PHS8 rod end, silicone tube, four F696ZZ bearings, magnet, and spring.
- The STEP additionally models a compact `SZ 8010_20 x 051 (0B)` resistance component and an M8x170 shaft.

Cost/effort is driven by laser cutting/bending, the PHS8 rod end, four less-common flanged bearings, the resistance component, and assembly time. This is not a low-cost mostly printed P1.

### STL integrity and units

All ten STLs are unitless by format. Millimetre scale is accepted only because named STEP occurrences have matching envelopes/volumes and DXF/STEP documentation is mm. After welding repeated STL facet vertices, every STL is one connected component, watertight, winding-consistent, has positive volume, zero detected duplicate faces, and zero near-zero-area faces. The MOZA STL passed the same checks.

One discrepancy is material: `rear hub.stl` volume is about 1206.3 file-units³ while the named STEP occurrence is about 1176.8 mm³, a roughly 2.5% difference. This indicates revision drift or a configuration difference. Other named printed-part volumes agree closely.

### Printability

- `handle.stl` (26 x 20 x 122 mm) should not be printed as a tall upright column for structural use. A side orientation gives longer continuous layers along the lever direction, but the internal shaft/bore may need support and post-processing. The modeled M8x170 steel member is an important reinforcement principle.
- `hand rest.stl` (about 40 x 40 x 3 mm) prints flat.
- `cap.stl` and `magnet holder.stl` print on their largest flat faces.
- `rear hub.stl` and spacers need bore/shaft calibration coupons. Vertical bore orientation improves circularity but can create a tall slender `spacer1` print.
- `clamp.stl` is a small mechanism clamp with a through feature; it may require support depending on orientation. It is not a table clamp.
- Bearing fits occur primarily in metal plates, avoiding risky PETG press fits in this design.

### Resistance system

The spring/damper linkage is adjustable through several holes and curved slot patterns. It provides useful higher-range product principles: replaceable spring, variable geometry, and multiple leverage settings. It is not the simplest reliable P1 mechanism. Spring rate, damper force, and installed preload are undocumented, so exact hand-force curves cannot be derived.

### Hall/PCB system

The AS5600 architecture is excellent: a moving magnet near the primary pivot and a stationary slotted sensor board avoid wear. The STEP sensor assembly envelope is 12.616 x 3.116 x 54.016 mm including components. The printed magnet holder is about 15.2 x 15.2 x 10 mm. The package BOM explicitly gives a 5 x 4 x 2 mm magnet, and the modeled magnet volume is consistent.

There is a PCB documentation conflict: `BOM_PCB_AS5600_pcb.csv` calls C2 **10 uF**, while `PickAndPlace_PCB_AS5600_pcb.csv` labels C2 **1 uF**. Resolve this before ordering or assembling that board. The provided PCB is a sensor board only; P1 still needs a protected Pro Micro/main board compartment and strain-relieved USB routing.

### Dimensional trust verdict

The neutral CAD and STL quality are the best in the set, but **do not complete-print/fabricate blindly**. First verify F696ZZ fit, every M6/M8 clearance, plate material/thickness, spring/damper specifications, sensor gap, and the BOM conflicts. Small printed parts are reasonable test prints after coupons.

## 6. Model 4 audit - Hydraulic handbrake

**MODEL:** Hydraulic Handbrake  
**SOURCE FILE(S):** `Handbrake.stp`, native SolidWorks assembly/parts, 9 IGES parts, 9 drawings, 30 images  
**GEOMETRY SOURCE USED:** STEP B-Rep/XCAF, IGES surfaces, package drawing images; native SolidWorks geometry not needed for measurements  
**CONFIGURATION:** vertical/rally style  
**OVERALL DIMENSIONS:** VERIFIED 92.245 x 263.761 x 409.983 mm  
**LEVER:** VERIFIED 8 mm Arm2 plate; local part envelope 289.980 x 83.498 x 8.000 mm  
**PIVOT:** VERIFIED 8 x 27 mm Shtift pin at assembly center x=22.266, y=68.682, z=142.951 mm  
**BEARINGS/BUSHINGS:** paired custom-looking flanged `Durjach` parts with 8 mm bore, 16 mm neck, and 32 mm flange cylindrical faces  
**SPRING SYSTEM:** hydraulic cylinder/piston/linkage supplies resistance; no documented simple return spring  
**BASE:** bent U-channel `Osnova`, 52 x 64 x 165 mm; drawing calls out 2.30 mm sheet  
**FASTENERS:** several pins/bolts are geometrically represented but no BOM  
**SENSOR:** none modeled  
**PCB SPACE:** no dedicated enclosure; limited space inside the U-base if hydraulic components are removed  
**PRINTED PARTS:** none  
**METAL PARTS:** nearly all structural and hydraulic components  
**CLAMP COMPATIBILITY:** possible under 52 mm-wide base but requires a wider adapter/reinforcement plate  
**RIG MOUNTING:** base geometry/drawings include holes/slots, but the supplied design is mainly a fabricated metal assembly  
**MAJOR WEAK POINTS:** custom seals/cylinder, side-load risk at hydraulic link, wear in custom bushings, welded/bent thin base, maintenance/leak risk  
**USEFUL DESIGN PRINCIPLES:** thick metal lever, two-sided pivot support, separate steel pin, compact U-channel base, replaceable linkage  
**UNKNOWNS:** materials, fits, bushing material, hydraulic pressure/seals, travel, force curve, and mounting-hole standard  
**CONFIDENCE:** dimensions/part structure high from neutral CAD; operating performance UNKNOWN without hydraulic data/testing

### Mechanism and load path

The hand load enters an 8 mm metal lever (`Arm2`), passes through paired flanged bushings and the 8 mm steel pin into the U-channel base, then drives `Arm1` and `ArmButalo` into `Butalo`/`PompaTqlo`. This is a strong mechanical concept, but the resistance system is expensive and maintenance-heavy.

The pivot-to-grip center-of-mass distance is DERIVED as 203.72 mm. The grip extends farther, so tip leverage is higher. At 100 N on the grip centroid, pivot torque is about 20.4 N·m; this does not establish strength.

### CAD quality

The main STEP declares millimetres, imports as 14 valid solids, and retains names. The nine IGES files also identify `MM`, but import as surfaces/open shells rather than solids. Use the STEP for assembly metrology. The drawings visually agree with key values: 2.30 mm base sheet, 8 mm lever plate, and detailed custom pivot pieces.

### Hall and clamp adaptation

A magnet can be placed concentrically at the pivot and a stationary board on the outside of `Osnova`, but the existing hydraulic link occupies the internal volume. Removing the hydraulic system would make the reference a useful vertical skeleton, not a minor modification. A desk clamp needs a wider removable adapter plate so clamp reaction does not peel the 2.3 mm base flange.

### Dimensional trust verdict

Trust the STEP/drawing measurements as reference dimensions, but **do not build this as P1** unless custom metal fabrication and hydraulic work are intentionally accepted.

## 7. Model 5 audit - MOZA HBP low-poly

**MODEL:** MOZA HBP Handbrake Low Poly  
**SOURCE FILE(S):** matching STEP and STL  
**GEOMETRY SOURCE USED:** STEP B-Rep and STL mesh  
**CONFIGURATION:** vertical/rally style  
**OVERALL DIMENSIONS:** VERIFIED 67.000 x 152.000 x 319.331 mm  
**LEVER:** fused into one low-poly solid; no separable lever geometry  
**PIVOT:** UNKNOWN; only four cylindrical faces exist, including two 12 mm faces, but no assembly meaning is recoverable  
**BEARINGS/BUSHINGS:** UNKNOWN  
**SPRING SYSTEM:** UNKNOWN  
**BASE:** fused exterior envelope  
**FASTENERS:** UNKNOWN  
**SENSOR:** UNKNOWN  
**PCB SPACE:** UNKNOWN; no recoverable cavity/component structure  
**PRINTED PARTS:** one watertight STL, but it is a monolithic exterior/prop rather than a mechanism  
**METAL PARTS:** UNKNOWN  
**CLAMP COMPATIBILITY:** a 67 x 152 mm footprint could accept an adapter in a new design; the supplied solid does not define one  
**RIG MOUNTING:** not mechanically recoverable  
**MAJOR WEAK POINTS:** monolithic fused body, no joints, no hardware, no load path, no replaceable electronics, large solid-print volume  
**USEFUL DESIGN PRINCIPLES:** vertical ergonomic envelope only  
**UNKNOWNS:** every functional detail  
**CONFIDENCE:** envelope and mesh integrity VERIFIED; all mechanism conclusions UNKNOWN

The STEP is one valid B-Rep solid. The STL becomes one watertight, winding-consistent component after normal STL vertex welding. STEP and STL bounds agree essentially exactly, so STL file units are safely interpreted as millimetres. Volumes also agree within about 0.001%. This proves conversion consistency, not functional usefulness.

Printing the monolithic shape would consume about 534,000 mm³ of solid material before slicer infill changes and would not produce a moving handbrake. It is the least useful mechanical source.

## 8. Dimensional comparison

| Model | Overall L x W x H | Base / side structure | Lever / hand radius | Critical pivot evidence | Confidence |
|---|---|---|---|---|---|
| Chinese generic | UNKNOWN | UNKNOWN | UNKNOWN | M8/bush filenames only | geometry UNKNOWN |
| Fanatec | down 424.000 x 64.687 x 118.000; up 213.373 x 64.687 x 328.627 mm | 154.000 x 61.500 x 76.000 mm base | about 224 mm to grip centroid | 7/8/12 mm concentric candidate features | VERIFIED/DERIVED |
| DIY v1.2 | 165.611 x 84.090 x 302.591 mm | paired 3 mm plates; 26 mm inner gap | 182.43 mm pivot-to-handle centroid; 122 mm handle envelope | four F696ZZ, 6 mm bore | VERIFIED/DERIVED |
| Hydraulic | 92.245 x 263.761 x 409.983 mm | 52 x 64 x 165 mm, 2.3 mm sheet | 203.72 mm pivot-to-grip centroid | 8 x 27 mm shaft; 8/16/32 mm flanged bushings | VERIFIED/DERIVED |
| MOZA low-poly | 67.000 x 152.000 x 319.331 mm | fused | UNKNOWN | UNKNOWN | envelope VERIFIED |

Full evidence rows are in `analysis_generated/measurements.csv`.

## 9. Mechanical architecture comparison

The Chinese design is the simplest visible horizontal mechanism. Fanatec is the best compact configurable envelope but lacks internals. DIY is the most complete and best instrumented mechanism, at the cost of complexity. Hydraulic has the strongest traditional fabricated-metal skeleton but the most expensive resistance system. MOZA has no recoverable mechanism.

The most useful cross-model pattern is a **two-sided pivot support with a metal lever/shaft and separate electronics**. Every credible functional reference routes hand force through metal at the lever or pivot. None provides evidence that a long, thin PETG-only lever is durable.

## 10. Pivot system comparison

| Model | Pivot evidence | Wear/DFM assessment |
|---|---|---|
| Chinese generic | M8 bolt, bush/bushing, plastic washers named | Simple/cheap; likely more friction and wear; exact fit UNKNOWN |
| Fanatec | concentric 7/8/12 mm features; internals omitted | Cannot establish whether bearing/bushing exists |
| DIY v1.2 | four F696ZZ flanged bearings on two axes, paired plates | Best supplied pivot; compact and smooth, but higher count and less-common bearing |
| Hydraulic | 8 mm steel pin, paired 8/16/32 flanged bushings, 8 mm lever | Strong load path; custom bushings/pin increase fabrication cost |
| MOZA | none recoverable | unusable as pivot evidence |

Closest to the desired `hand -> lever -> steel pivot -> bearings -> reinforced housing` is **DIY v1.2**. P1 should adapt the principle using common 608-2RS bearings only after PETG fit coupons prove a reliable 22 mm pocket.

## 11. Spring/resistance comparison

- **Chinese generic:** simple axial compression spring and yoke. Best simplicity principle; dimensions/preload UNKNOWN.
- **Fanatec:** no internal spring evidence.
- **DIY v1.2:** adjustable compression spring plus resistance component and PHS8 link. Best adjustment principle; too complex for P1.
- **Hydraulic:** cylinder/piston linkage. Strong simulation feel is possible, but cost, seals, machining, and maintenance reject it for P1.
- **MOZA:** no evidence.

For P1, use one replaceable **extension spring** with steel eye/bolt anchors and a mechanical stop. It is cheaper and easier to inspect than the yoke/damper systems. Place multiple steel-supported anchor holes in later revisions for resistance adjustment; use one fixed validated position in the first core test.

## 12. 3D printability comparison

| Model | FDM readiness | Key concern |
|---|---|---|
| Chinese generic | poor/UNKNOWN | no neutral geometry or STL; appears metal-oriented |
| Fanatec | poor | exterior STEP only; 4 mm lever unsuitable as PETG copy |
| DIY v1.2 | good for ten auxiliary parts, poor for whole product | core still needs ten cut-metal plates and extensive hardware |
| Hydraulic | very poor | fabricated metal and hydraulic parts |
| MOZA low-poly | mesh-valid but functionally unusable | single fused exterior, high material/support demand |

Assumed PETG, 0.20 mm layers, at least 5-6 perimeters around loaded holes, high local infill, and no load-bearing printed threads. Final slicer orientations must be reviewed after P1 geometry exists.

## 13. Durability and weak-point analysis

Critical load zones across the references are lever roots, pivot holes, side-wall transitions, spring anchors, and base/clamp interfaces. Printed versions add layer-separation risk.

An illustrative torque range:

| Hand load | Radius | Pivot torque |
|---:|---:|---:|
| 50 N | 0.22 m | 11 N·m |
| 100 N | 0.22 m | 22 N·m |
| 150 N | 0.22 m | 33 N·m |

These are input loads only. Bearing reactions and spring-anchor forces depend on geometry and can be higher. No safety factor is claimed.

P1 structural risks to manage:

- PETG creep around bearing pockets and clamp loads.
- Lever-root hub splitting between layer lines.
- M8 pivot threads contacting bearing inner races.
- Spring hook tearing a printed anchor.
- Printed supports spreading apart under moment.
- Clamp reaction peeling the base or crushing a printed shell.
- Hard travel stops shocking thin walls.

Mitigations are metal lever, smooth pivot shank, dual bearings, through-bolted supports, large washers/backing strips, steel eye bolts, rubber bump stop, and a clamp load path tied to steel reinforcement.

## 14. Hall sensor integration opportunities

Ranking:

1. **DIY v1.2** - best. Co-axial moving magnet, stationary slotted AS5600 board, and documented magnet holder.
2. **Chinese generic** - good packaging potential. Existing PCB cover and exposed rotating lower handle, but all gaps/dimensions UNKNOWN.
3. **Hydraulic** - feasible outside the pivot if the hydraulic linkage is removed/reworked.
4. **Fanatec** - enclosed base is promising, but pivot cavity and internals are absent.
5. **MOZA** - no recoverable interface.

For SS49E experiments, make the stationary board adjustable over a VERIFIED experimental **3-15 mm gap range** and allow magnet rotation/orientation changes. Do not freeze the magnet pocket until P0 maps ADC output versus angle and gap. Keep the sensor on a small replaceable 3-wire board so it can later be exchanged for AS5600 or another magnetic sensor.

## 15. PCB/USB packaging opportunities

- DIY proves a modular sensor-board concept but leaves the main controller exposed/undefined.
- Chinese provides the best visible separate electronics cover.
- Fanatec provides the best compact enclosure envelope but no internal mounting evidence.
- Hydraulic requires a new enclosure.
- MOZA provides no usable cavity.

P1 should use two modules:

```text
Pro Micro / main PCB enclosure
        |
  3-wire locking connector
        |
adjustable Hall sensor board
```

Provide screw access, a strain-relieved USB cable exit, a future USB-C bulkhead/PCB opening, LED window option, calibration-button access, and enough slack that lever motion cannot pull the sensor cable. Do not glue the controller permanently into the base.

## 16. Horizontal versus vertical suitability

| Model | Horizontal | Vertical/rally | Evidence |
|---|---|---|---|
| Chinese generic | excellent | poor | embedded assembly preview |
| Fanatec | excellent | excellent | two STEP configurations |
| DIY v1.2 | poor | excellent | STEP/renders |
| Hydraulic | limited | excellent | STEP/renders |
| MOZA low-poly | poor | envelope only | fused vertical solid |

P1 should validate one vertical/diagonal configuration because it keeps the footprint compact and exposes the mechanism for testing. The lever-to-hub interface should be bolt-on so a horizontal lever plate can be tested later without rebuilding the pivot/base.

## 17. Table-clamp integration analysis

| Model | Feasibility | Main issue |
|---|---|---|
| Chinese generic | medium | base dimensions/strength UNKNOWN; separate under-base bracket needed |
| Fanatec | medium | narrow 61.5 mm base; shell must not carry clamp peel load |
| DIY v1.2 | good | 81 mm-wide steel flange and rig slots; add a separate clamp plate, not the mechanism `clamp.stl` |
| Hydraulic | medium | 52 mm U-base needs a wider load-spreading adapter |
| MOZA low-poly | low | no separable base or load path |

P1 clamp architecture should be removable and mechanically independent of rig holes: steel M10 threaded rod/bolt, captured steel coupling nut or nut, 40-50 mm swivel pressure pad, large printed hand knob around steel hardware, and rubber pads. Target 10-55 mm desk thickness. Tie clamp reaction into steel base reinforcement; do not depend on a printed main thread.

## 18. Component and hardware requirements found

The detailed evidence table is `analysis_generated/hardware_candidates.csv`.

Most reusable reference hardware:

- M6/M8 through-bolts, washers, and nyloc nuts.
- F696ZZ bearings in DIY if compactness is critical; 608-2RS is preferable for P1 availability and cost if the larger pocket is acceptable.
- Replaceable compression/extension spring with metal anchors.
- 5 x 4 x 2 mm magnet/AS5600 arrangement as a reference, not a mandatory final sensor choice.
- Hydraulic 8 mm steel pin principle, not its custom pin geometry.

Prototype cost drivers to avoid are laser-cut multi-plate stacks, custom bushings, PHS8 rod ends, dampers/gas springs, hydraulic cylinders, machined shafts, and a large mix of fastener lengths.

## 19. License and commercial-use evidence

Package evidence:

- **All five:** no README/LICENSE/COPYING or explicit commercial grant found.
- **Chinese generic:** OLE metadata shows SolidWorks 2012-era files and author field `Les`; no rights statement. A secondary web index shows the exact title as a GrabCAD model and describes dimensionally accurate mounting holes, but it does not establish the license contained with this download.
- **Fanatec:** package is branded `FANATEC`; no rights statement. Treat it only as reference geometry and avoid copying brand/trade dress.
- **DIY v1.2:** no rights statement. PCB/manufacturing files do not imply commercial permission.
- **Hydraulic:** STEP header names `Jose Luis Fernandez`, Autodesk Inventor 2012, and a path containing `GRABCAD DIA DIA`; no rights statement.
- **MOZA low-poly:** package is branded `MOZA`; no rights statement. A current similarly titled CGTrader listing is not enough to authenticate this package or grant rights.

**Commercial-use clarity is low/unclear for every package.** This is an evidence statement, not legal advice. The safe engineering course is to use general mechanical principles and create an original architecture, dimensions, parts, and appearance.

## 20. Comparison matrix

Scale: 5 = best for the stated P1 objective; 1 = worst; `U` = unavailable evidence.

| Category | Chinese | Fanatec | DIY v1.2 | Hydraulic | MOZA low-poly |
|---|---:|---:|---:|---:|---:|
| Mechanical simplicity | 4 | U | 2 | 1 | 1 functional |
| Low prototype cost | 3 | U | 2 | 1 | 1 functional |
| Printability as supplied | 1 | 1 | 3 | 1 | 1 functional |
| Low metal-fabrication need | 2 | U | 1 | 1 | U |
| Few custom components | 3 | U | 1 | 1 | U |
| Durability potential | 3 | U | 5 | 5 | U |
| Pivot quality | 2 estimated | U | 5 | 4 | U |
| Simple P1 resistance | 5 principle | U | 2 | 1 | U |
| Adjustable future resistance | 2 | U | 5 | 3 | U |
| Hall adaptability | 3 | 2 | 5 | 3 | 1 |
| PCB packaging | 5 principle | 3 | 3 | 2 | 1 |
| Horizontal suitability | 5 | 5 | 2 | 2 | 1 |
| Vertical suitability | 1 | 5 | 5 | 5 | 5 envelope |
| Clamp integration | 3 | 2 | 4 | 3 | 1 |
| CAD quality/usefulness | 2 | 3 | 5 | 4 | 2 |
| Ease of safe modification | 2 | 3 | 4 | 3 | 1 |
| Likely reliability evidence | 2 | U | 4 | 3 | U |
| Commercial-license clarity | 1 | 1 | 1 | 1 | 1 |

## 21. Recommended Prototype P1 architecture

### Chosen concept

A compact vertical/diagonal mechanical skeleton, approximately in the DIY/MOZA footprint class, using:

1. Separate PETG base and left/right pivot-support modules through-bolted to steel backing strips.
2. A replaceable PETG lever-root hub containing **two 608-2RS bearings**.
3. A fixed M8 class 8.8 partially threaded bolt or shoulder bolt whose smooth shank passes through both bearing inner races; washers/spacer and M8 nyloc prevent axial binding.
4. A **25 x 5 mm steel flat-bar lever**, about 250-300 mm stock length, bolted to the printed hub. Cutting/drilling is acceptable; no CNC machining is required.
5. A separate printed grip and replaceable end cap.
6. One extension spring with M6 steel eye/bolt anchors. Initial P1 uses one anchor position and a rubber-bumper travel stop; later plates can add adjustment holes.
7. A moving N35/N42 neodymium magnet in a replaceable printed holder on the hub/lower lever.
8. A stationary SS49E sensor board on a slotted bracket covering a 3-15 mm experimental gap.
9. A rear/side Pro Micro enclosure connected by a 3-wire sensor cable, with strain-relieved USB exit.
10. Independent M6 rig holes/slots and a removable clamp adapter using an M10 steel screw/coupling nut/swivel pad.

### Why this is the recommended hybrid

- **DIY v1.2** proves that paired plates/bearings and a co-axial magnet/sensor work cleanly.
- **Hydraulic** proves the value of a thick metal lever and a steel pivot supported on both sides.
- **Chinese generic** contributes the simple single-spring/yoke philosophy and a separate electronics cover.
- **Fanatec** contributes the bolt-on orientation/configuration idea and compact base envelope.
- **MOZA** contributes only a rough vertical ergonomic/footprint reference.

The deliberate challenge to an all-printed P1 is the steel flat-bar lever. Every credible functional reference uses metal in the primary lever/load path. A 250 mm PETG-only lever would make layer orientation and creep the dominant failure risks. One drilled commodity flat bar is a low-cost compromise that materially improves safety and test value.

### P1 success criteria

- Smooth pivot with no printed-on-printed rubbing.
- No bearing creep or support spreading after repeated pulls.
- Stable return to zero and mechanical travel stop.
- Sensor monotonic over full travel with no contact.
- Electronics removable without disassembling the pivot.
- Rig mounting and desk clamp loads bypass thin covers.
- Progressive static/repetition tests completed before cosmetic shell work.

## 22. Features worth borrowing as engineering principles

| Reference | Principle | Why valuable |
|---|---|---|
| DIY v1.2 | paired real bearings and two-sided support | reduces friction/wear and controls shaft alignment |
| DIY v1.2 | moving magnet + stationary slotted sensor board | contactless, adjustable, serviceable |
| DIY v1.2 | rig slots in a wide base flange | flexible mounting and load distribution |
| Hydraulic | thick metal lever and steel pin | puts highest bending/pivot loads into metal |
| Hydraulic | compact U-channel base | simple load path and good lateral stiffness |
| Chinese generic | separate compression-spring/yoke module | simple replaceable resistance concept |
| Chinese generic | dedicated PCB cover | protects electronics while preserving service access |
| Fanatec | discrete lever orientations around one compact base | supports product-family reuse without a fully universal mechanism |
| MOZA | compact vertical proportions | ergonomic envelope reference only |

## 23. Features that should not be copied

- Any branded exterior, logos, trade dress, or unchanged downloaded geometry.
- DIY's complete 90-occurrence spring/damper/PHS8 stack for entry P1.
- Hydraulic cylinder/piston/custom bushings for an inexpensive prototype.
- Chinese likely bolt-through-bushing pivot as the preferred production pivot.
- Fanatec's 4 mm lever dimension if the material is changed to PETG.
- MOZA's monolithic fused solid.
- Printed main clamp threads or spring hooks.
- Exposed sensor PCB or a USB connector carrying cable strain directly on solder joints.
- Any undocumented fastener length from the DIY BOM until conflicts are resolved.

## 24. Critical dimensions/components to physically verify

Before P1 CAD is frozen:

1. Actual 608-2RS bearing OD, ID, width, chamfer, and seal protrusion from the purchased batch.
2. M8 pivot bolt smooth-shank diameter/length and thread start; threads must not run in the bearing bores.
3. Steel flat-bar actual width/thickness/straightness and achievable drilled-hole position.
4. Chosen spring free length, body OD, hook geometry, rate, maximum safe extension, and force at intended travel.
5. SS49E supply/output range and magnet polarity/orientation over 3-15 mm gaps.
6. Actual magnet dimensions/coating tolerance.
7. Pro Micro board, USB plug, and cable bend-radius envelope.
8. Printer XY hole shrinkage, PETG bearing-pocket creep, and heat-set insert pullout.
9. Desk thickness range, underside clearance, edge radius, and maximum clamp reach.
10. Desired hand force, lever travel, grip position, and resting angle.

Reference-specific verification if reusing a part:

- DIY F696ZZ actual 6 x 15 x 5 / flange 17 dimensions and fit.
- DIY M8 conflict: documentation says M8x45/M8x55 while STEP includes M8x40 and M8x170.
- DIY AS5600 C2 conflict: 10 uF BOM versus 1 uF PnP comment.
- DIY `rear hub` STL/STEP revision difference.
- Chinese dimensions only after native B-Rep access.

## 25. Small calibration prints before a full prototype

Use the same printer, PETG, nozzle, layer height, walls, and slicer compensation planned for P1.

1. **608 pocket ladder:** 21.8, 22.0, 22.1, 22.2, 22.3, 22.4 mm; include both 7 and 14 mm pocket depths.
2. **M8 clearance ladder:** 8.0, 8.2, 8.4, 8.6 mm through-holes.
3. **M6 clearance ladder:** 6.0, 6.2, 6.4, 6.6 mm.
4. **M6 nut traps:** 10.0, 10.2, 10.4, 10.6 mm across flats with realistic trap depth.
5. **Heat-set insert coupon:** sizes based on the exact purchased insert datasheet, plus +/-0.1 and +0.2 mm bore variants.
6. **Magnet pocket coupon:** nominal, +0.1, +0.2, +0.3 mm in both press-fit and retained-cover versions.
7. **Sensor-gap jig:** fixed 3, 5, 8, 10, 12, 15 mm stations for logging ADC output versus angle/orientation.
8. **Loaded bearing-wall coupon:** representative bearing pocket with the intended wall thickness and through-bolt, held under load for creep observation.

Do not use glue as the only magnet retention method in the final mechanism; the coupon may evaluate a mechanical cap plus optional adhesive.

## 26. Recommended P0/P1 shopping list

### P0 electronics bench

- 2 x ATmega32U4 Arduino Pro Micro, 5 V / 16 MHz.
- 3 x SS49E linear Hall sensor, TO-92, from a traceable supplier if possible.
- 4 x N35/N42 neodymium block magnet, nominal 10 x 5 x 3 mm, plus 4 x 6 x 3 mm disc magnets for comparison.
- 1 x AS5600 breakout/module as a benchmark against the linear Hall approach.
- 1 x solderable prototype board or small custom sensor breakout.
- 2 x JST-XH 3-pin cable assemblies, 200-300 mm.
- 100 nF ceramic capacitors, 10 uF electrolytic/ceramic capacitors, headers, breadboard jumpers.
- 1 x known-good data-capable USB cable.
- Digital caliper and a simple force gauge/luggage scale if not already owned.

### P1 mechanical core

- 2 x 608-2RS bearings, 8 x 22 x 7 mm; buy 4 so two are spares/test samples.
- 2 x candidate M8 class 8.8 partially threaded bolts, approximately M8x70, with verified smooth shank long enough for both bearing inner races; alternatively one M8 shoulder bolt after dimension check.
- M8 flat washers and M8 nyloc nuts, 4 each.
- 1 x steel flat bar, 25 x 5 x 300 mm minimum.
- M6 class 8.8 socket-head bolts: M6x20, M6x30, M6x40, four each for prototyping.
- M6 large washers and M6 nyloc nuts, at least 12 each.
- 2 x M6 eye bolts or clevis-style steel spring anchors with nuts/washers.
- 1 x extension-spring assortment centered on 15-20 mm OD and 60-100 mm hook-to-hook length; target spring rate cannot be finalized until hand-force/travel requirements are supplied.
- 2 x M6 adjustable rubber bump stops or equivalent rubber-covered stop bolts.
- PETG, 1 kg, known dry filament.
- M4/M5 heat-set insert assortment only for covers/brackets, not the primary pivot/clamp load.
- 2 x steel backing strips, approximately 25 x 3 x 180 mm, drillable by hand.
- For clamp P3, not required for first core test: M10x120 steel threaded rod/bolt, M10 coupling nut, 40-50 mm swivel pressure pad, steel washers, rubber sheet/pads, and a printed knob around a captured steel nut.

Spring selection is intentionally an assortment at P1 because no reference supplies a complete force-rate-travel specification and the user's target force is still unknown.

## 27. Unknowns/measurements still required from the owner

1. Preferred first P1 resting orientation: vertical, diagonal, or horizontal.
2. Desired handle travel in degrees or mm at the grip.
3. Desired light/medium/heavy hand-force range at full pull.
4. Printer model, build volume, nozzle size, and normal PETG dimensional accuracy.
5. Available fabrication tools: drill press/hand drill, hacksaw/bandsaw, files, taps.
6. Whether one drilled steel flat-bar lever and two drilled steel backing strips are acceptable.
7. Target P1 mechanical/electronics/clamp budget.
8. Desk thickness/underside obstruction measurements and desired clamp throat depth.
9. Grip diameter/length preference and right/left-hand mounting needs.
10. Measured pull force, travel, pivot size, and sensor behavior from the already reverse-engineered inexpensive metal handbrake, if available.
11. Whether P0 should compare SS49E and AS5600 before the sensor bracket interface is frozen.

## 28. Proposed next CAD phase - after approval only

1. Freeze P1 requirements: orientation, hand force, travel, desk/rig envelope, and allowed metal work.
2. Measure purchased bearings, pivot bolt, flat bar, spring candidates, magnets, and electronics.
3. Create a parameter sheet/master skeleton with pivot axis, lever radius, spring anchors, stops, sensor arc, base envelope, rig pattern, and clamp interface.
4. CAD only the mechanical core parts first: base, two supports, lever-root hub, steel lever drawing/template, spring anchor, and stop.
5. Produce the 608/M8/M6/insert/magnet coupons and revise fit allowances.
6. Print and assemble P1 core without electronics; run progressive load and repetition tests.
7. Add the adjustable Hall bracket and magnet holder after P0 field mapping.
8. Add the removable clamp after the rig-mounted core passes testing.
9. Add accessible electronics cover and cable management.
10. Only then refine appearance and consider horizontal/vertical variants and a custom PCB.

## Stop-condition conclusion

**A. Inspected:** all 143 source files across five packages, neutral B-Reps, STL integrity, DXF units/entities, PDF fabrication sheet, package renders, hardware/PCB lists, SolidWorks metadata/previews, and local tool availability.  
**B. Learned:** only DIY v1.2 is a complete functional reference; every credible load path uses metal; contactless sensing is best documented in DIY; license clarity is absent.  
**C. Recommended architecture:** printed modular skeleton + drilled steel lever + M8/dual-608 pivot + simple extension spring + adjustable SS49E + removable electronics + independent rig/clamp interfaces.  
**D. Reference contributions:** DIY pivot/sensor/rig base; Hydraulic metal load path; Chinese spring/PCB cover; Fanatec configuration packaging; MOZA envelope only.  
**E. Closest starting point:** DIY v1.2, used as a principle reference rather than copied geometry.  
**F. Purchase list:** specified in Section 26.  
**G. Physical verification:** specified in Sections 24-25.  
**H. Next plan:** specified in Section 28.

No production or prototype CAD has been created. Await approval of the architecture and answers to the Section 27 unknowns before starting CAD development.

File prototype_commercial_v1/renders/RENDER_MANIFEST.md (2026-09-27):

# Render manifest

All images are tessellated directly from the validated P1-C CadQuery B-Rep. No generative geometry or concept-art alteration is used. Revision: **P1-C-A1**. Human-hand image omitted because no scale-locked human model is available.

|Filename|CAD revision|Assembly|Camera|Hidden parts|Transparent parts|Material overrides|Purpose|
|---|---|---|---|---|---|---|---|
|01_FRONT_LEFT_3Q.png|P1-C-A1|step/P1C_ASSEMBLY.step|front-left 3/4|none|none|PBR mapping from CAD material class|customer hero|
|02_FRONT_RIGHT_3Q.png|P1-C-A1|step/P1C_ASSEMBLY.step|front-right 3/4|none|none|PBR mapping from CAD material class|opposite customer view|
|03_LEFT_SIDE.png|P1-C-A1|step/P1C_ASSEMBLY.step|left orthographic|none|none|PBR mapping from CAD material class|left packaging|
|04_RIGHT_SIDE.png|P1-C-A1|step/P1C_ASSEMBLY.step|right orthographic|none|none|PBR mapping from CAD material class|right packaging|
|05_FRONT.png|P1-C-A1|step/P1C_ASSEMBLY.step|front orthographic|none|none|PBR mapping from CAD material class|width and symmetry|
|06_REAR.png|P1-C-A1|step/P1C_ASSEMBLY.step|rear orthographic|none|none|PBR mapping from CAD material class|rear pod and USB|
|07_TOP.png|P1-C-A1|step/P1C_ASSEMBLY.step|top orthographic|none|none|PBR mapping from CAD material class|mechanism packaging|
|08_LOW_ANGLE.png|P1-C-A1|step/P1C_ASSEMBLY.step|low front-left|none|none|PBR mapping from CAD material class|base stance|
|09_ENGINEERING_WITHOUT_ACCENT_PANELS.png|P1-C-A1|step/P1C_ASSEMBLY.step|front-left 3/4|A001/A002 and related M4 trim|none|PBR mapping from CAD material class|structural vs cosmetic|
|10_ACCENT_PANEL_INSTALLATION.png|P1-C-A1|step/P1C_ASSEMBLY.step|front-left 3/4|none|none|PBR mapping from CAD material class|panels and screws displaced along assembly axes|
|11_FULL_EXPLODED_VIEW.png|P1-C-A1|step/P1C_ASSEMBLY.step|front-left 3/4|none|none|PBR mapping from CAD material class|logical exploded assembly|
|12_INTERNAL_CUTAWAY.png|P1-C-A1|step/P1C_ASSEMBLY.step|right 3/4|right accent|right steel frame 18% opacity|PBR mapping from CAD material class|load and sensing paths|
|13_HALL_SENSOR_DETAIL.png|P1-C-A1|step/P1C_ASSEMBLY.step|right close-up|unrelated parts|right frame translucent/omitted by selection|PBR mapping from CAD material class|Hall/magnet air gap|
|14_SPRING_SYSTEM_DETAIL.png|P1-C-A1|step/P1C_ASSEMBLY.step|left close-up|right frame and unrelated parts|none|PBR mapping from CAD material class|spring, anchors and stops|
|15_DESK_CLAMP_REALISTIC.png|P1-C-A1|step/P1C_ASSEMBLY.step|front-left 3/4|none|desk 42% opacity|PBR mapping from CAD material class|actual desk clamp|
|16_RIG_MOUNT_CONFIGURATION.png|P1-C-A1|step/P1C_ASSEMBLY.step|front-left 3/4|clamp|none|PBR mapping from CAD material class|rig mode fixture|
|17_MOTION_STATES.png|P1-C-A1|step/P1C_ASSEMBLY.step|left comparison|none|none|PBR mapping from CAD material class|validated 75/62.5/50 degree states|
|18_REAL_SIM_RIG_CONTEXT.png|P1-C-A1|step/P1C_ASSEMBLY.step|wide 3/4|clamp|none|PBR mapping from CAD material class|generic unbranded scale context|

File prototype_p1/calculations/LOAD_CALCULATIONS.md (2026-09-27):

# P1.0 transparent load calculations
These are statics checks, not FEA, certification, or a PETG safety-factor claim.
Lever hand radius: 245.0 mm. Clamp throat: 60.0 mm.
|Hand force (N)|Pivot torque (N.m)|Ideal 60 mm reaction couple (N)|25x5 bar elastic stress* (MPa)|
|---:|---:|---:|---:|
|50|12.25|204.2|23.52|
|75|18.375|306.2|35.28|
|100|24.5|408.3|47.04|
|150|36.75|612.5|70.56|

*Rectangular-section elastic bending estimate assumes force acts in the intended strong 25 mm plane. Steel grade, holes, fatigue, out-of-plane load, and actual stock dimensions are not included.

Clamp holding and PETG tower/base strength: **PHYSICAL TEST REQUIRED**. No friction coefficient or printed-material allowables were assumed.

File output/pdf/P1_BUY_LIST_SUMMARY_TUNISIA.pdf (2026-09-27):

ELKATEB P1 - Tunisia buy list - checked 27 Sep 2026 | Page 1

# P1 Buy List Summary - Tunisia

What to buy for the first complete printed prototype, with direct product links and a clear budget total.

# 1. Exact online products

Buy | Exact product | Shop / online link | Unit | Line total
4 | 608-2RS bearing, 8 x 22 x 7 mm | Tunisie Roulements (https://tunisie-roulements.tn/produit/roulement-608-2rs/) | 3.500 | 14.000 TND
1 | Arduino Pro Micro, ATmega32U4, 5 V / 16 MHz | CoThings product (https://cothings.net/products/arduino-pro-micro-mini-usb-atmega32u4-5v-16mhz) | 28.000 | 28.000 TND
2 | SS49E linear Hall sensor | Tuni Smart product (https://tuni-smart-innovation.com/products/capteur-a-effet-hall-lineaire-ss49e-oh49e) | 2.500 | 5.000 TND
1 | JST 2.54 mm, 3-pin female cable + male header | Didactico product (https://didactico.tn/produit/cable-connecteur-femelle-jst-2-54-3pin-connecteur-male/) | 1.500 | 1.500 TND
1 | USB-A to Micro-USB data cable, 1 m | Didactico product (https://didactico.tn/produit/cable-usb-micro-usb-1m-bleu/) | 6.000 | 6.000 TND
1 | DRS-6 heat-shrink, 6 mm, 2:1 | Didactico product (https://didactico.tn/produit/gaine-thermoretractable-drs-6/) | 2.200 | 2.200 TND
2 | Neodymium magnet, rectangular 20 x 10 x 2 mm | Celectronix product (https://www.celectronix.com/autres-mecanique/7498-aimant-cylindrique-de-n-odyme-16-mm-de-diam-tre-x-1-8-mm-d-paisseur-copie-.html) | 1.499 | 2.998 TND
Confirmed-price online subtotal: 59.698 TND (before delivery).

The magnet is a locally available candidate, not a drop-in fit. The released holder was made around a 10 x 5 x 3 mm block. If the 20 x 10 x 2 mm magnet is purchased, measure it with calipers and print only a revised magnet coupon/holder before the structural set.

### Optional printing material

Choice | Product / planning basis | Price | What it means
If Amine has enough PETG | Use his stock after slicer confirmation | 0 TND purchase | Ask for remaining grams and actual slicer estimate
Minimum new spool | LUME PETG 1.75 mm, 1 kg (https://www.celectronix.com/filament-petg/8156--074-0-barre-led-tv-lg-43uk6565-7led-3v-44-5cm.html) | 86.000 TND | Covers the 685 g final-parts estimate, but little reprint reserve
Recommended development stock | Two 1 kg PETG spools | 172.000 TND | Covers coupons, all final parts and useful reprint reserve

Current engineering estimates: coupons 233 g; final 19 parts 685 g; all 27 pieces 918 g. Amine's real slicer result replaces these planning values.

# 2. Buy locally from a quincaillerie / metal shop

Group | Exact requirement | Budget
Steel | 1 x 25 x 5 x 280 mm flat bar; 2 x 25 x 3 x 180 mm reinforcement strips | 13-30 TND
M8 pivot stack | 1 x M8 x 90 class 8.8 partially threaded bolt; 1 nyloc; washers/shims; 8 ID x about 10 OD x 13.6 mm spacer | 10-25 TND
M6 bolts | 4 x 35; 2 x 40; 4 x 25; 10 x 30; 1 x 45; plus 2 rig bolts to suit rig | 20-35 TND incl. nuts/washers
M6 nuts/washers | At least 25 nyloc nuts and 40 washers, including large load-spreading washers | Included above
M4 hardware | 4 x M4x35; 2 x M4x30; 4 x M4x20; 1 x M4x40; matching washers/nylocs | 6-12 TND
M3 hardware | 5 x M3x20; 2 x M3x12; 4 x M3x10; nuts/washers; 4 x M3 heat-set inserts | 4-8 TND
Spring trials | Extension springs: 15-20 mm OD, 60-100 mm hook-to-hook; buy light and medium samples | 10-25 TND
Desk clamp | M10 x 100 screw/rod; M10 coupling nut about 30 mm; swivel foot; 46 mm lower rubber; 90 x 62 x 2-3 mm upper rubber | 16-40 TND

Local mechanical estimate: 79-175 TND. These are planning allowances, not confirmed shop quotations.

### Totals

Scenario | Estimated cash total
Hardware + electronics, Amine supplies filament | 139-235 TND
Hardware + electronics + one new 1 kg PETG spool | 225-321 TND
Hardware + electronics + recommended two PETG spools | 311-407 TND

The total excludes delivery, tools, failed prints and optional spare fastener packs. Call/check stock before paying because web prices and availability can change.

### Suggested shops

Bearings: Tunisie Roulements, 6 Rue Chedly Kallala, Lafayette, Tunis 1002. Bolts: SEGEMO, 10 Rue Aid Jaberi, Tunis 1000. Electronics: CoThings, Route X near Stade Bardo; Tuni Smart, 1 Rue Pierre Mendes France, Ariana; Didactico, Cite des Martyrs, Sfax. Magnet: Celectronix, Centre Said, Avenue Habib Bourguiba, Megrine.
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

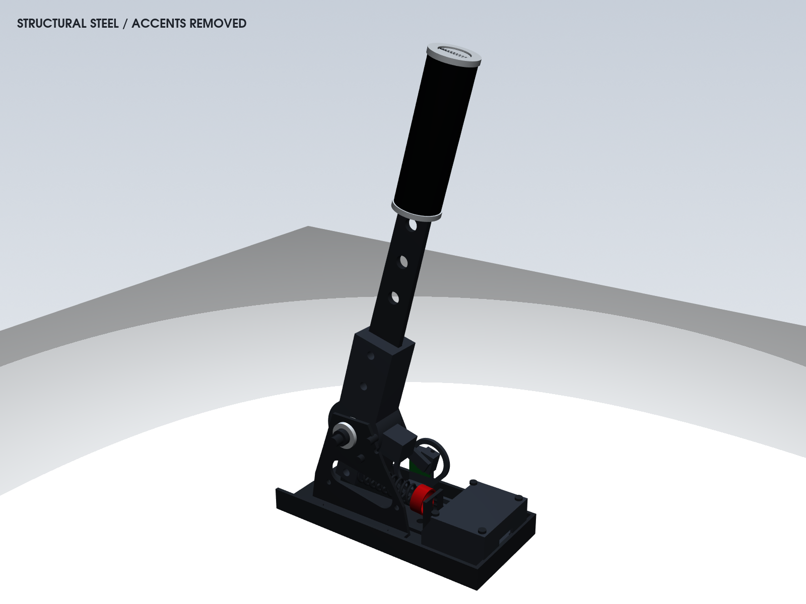
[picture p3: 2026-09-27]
prototype_commercial_v1/renders/09_ENGINEERING_WITHOUT_ACCENT_PANELS.png

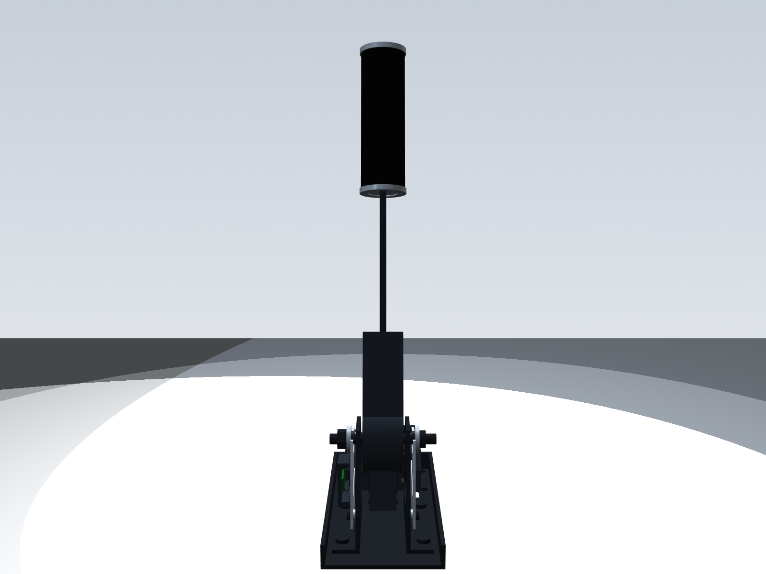
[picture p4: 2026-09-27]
prototype_commercial_v1/renders/05_FRONT.png

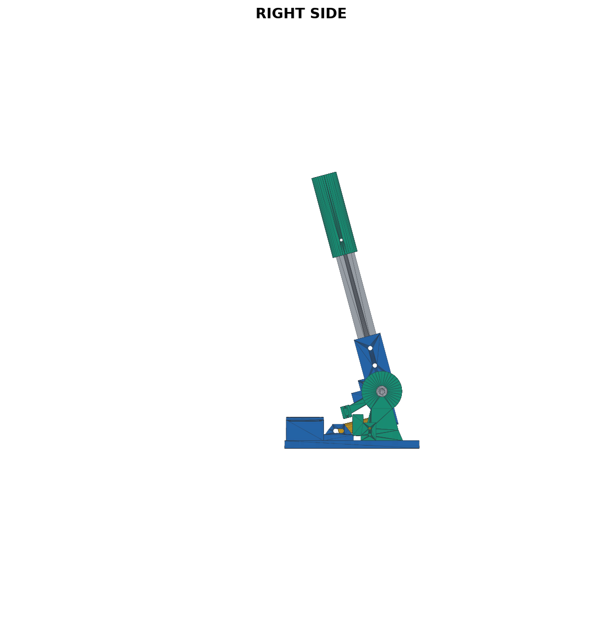
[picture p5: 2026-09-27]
prototype_p1/renders/03_RIGHT_SIDE.png

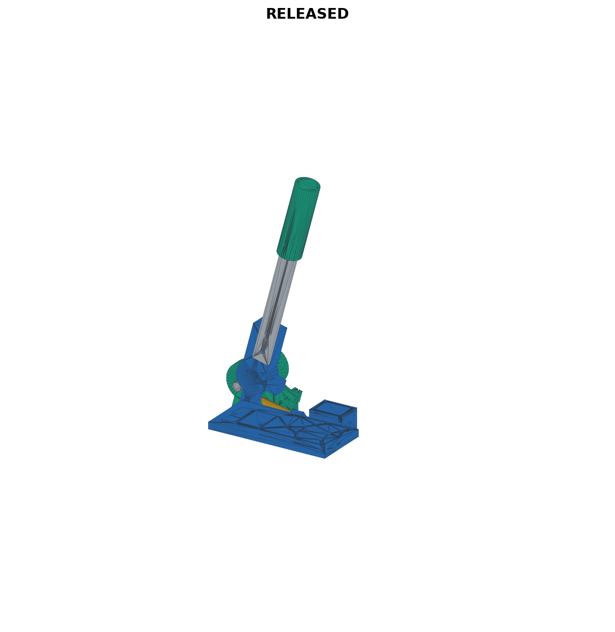
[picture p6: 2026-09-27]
prototype_p1/renders/13_RELEASED.png

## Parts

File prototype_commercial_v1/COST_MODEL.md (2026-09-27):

# Cost model

All local fabrication values are planning allowances until replaced by Tunisian supplier quotations. `reports/cost_model.csv` carries the status of every line and unit-cost scenarios for 1/5/10/25/50 units.

|Retail TND|35% direct BOM|40% direct BOM|45% direct BOM|
|---:|---:|---:|---:|
|150|52.50|60.00|67.50|
|175|61.25|70.00|78.75|
|200|70.00|80.00|90.00|
|250|87.50|100.00|112.50|
|275|96.25|110.00|123.75|
|300|105.00|120.00|135.00|

Quantity-25 planning direct BOM excluding assembly/packaging: **87.8 TND**. Full planning allowance including those two categories: **100.8 TND**. BOM is not profit; labor, packaging, failures, warranty, marketing, payment fees, tax and overhead remain separate business costs.

The five largest planning pressures are electronics, grip, fasteners, laser cutting, and assembly/powder coating. The cost-down pass retained one folded base, removed CNC billet parts, reduced aluminium to two flat accents, standardized commodity bearings, and shared MID/PRO architecture.

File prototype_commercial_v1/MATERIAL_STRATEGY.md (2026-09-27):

# Material strategy

Primary structure: 3 mm S235/ST37/DC01-equivalent mild steel, laser cut, deburred, formed, and satin/matte black powder coated. RFQ 2.5 mm as a controlled cost-down alternative only after physical stiffness testing.

Visible accents: 2 mm aluminium, directional brushed finish with clear protection or silver powder coat. They are non-structural and remain outside the magnetic window.

Printed internals: black PETG for alpha or ASA when heat/UV resistance and printer capability justify it. Red PETG/ASA only for the small spring collar. Bearing carrier material and wall behavior require coupon and cyclic testing.

Grip: commodity rubber/bicycle/motorcycle-style grip over a Ø22 mm tube for MID. Knurled aluminium is reserved for PRO.

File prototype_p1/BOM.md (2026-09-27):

# P1.0 prototype BOM

Quantities are for one handbrake unless marked spare. Lengths are purchase candidates and must be checked against actual washers/nuts and local stock.

## Printed PETG

Nineteen structural/accessory prints: P1-001, P1-002, P1-003, P1-004, P1-006 through P1-013 (including P1-011A/B), and P1-020 through P1-025. Print the eight calibration coupons first. Allow approximately 1.5–2.0 kg PETG for coupons, iterations, and all parts; slicer mass depends on settings.

## Metal and bearings

|Qty|Item|P1 use/status|
|---:|---|---|
|1|25 x 5 x 280 mm mild-steel flat bar|lever; MEASURE_BEFORE_PRINT|
|2|25 x 3 x 180 mm steel strips|base reinforcement|
|2|608-2RS, 8 x 22 x 7 mm|installed pivot bearings|
|2|608-2RS|fit/testing spares|
|1|M8x90 class 8.8 partially threaded bolt|pivot candidate; verify smooth-shank length|
|1|8 mm ID x about 10 mm OD x 13.6 mm metal spacer tube|between bearing inner races; trim to measured stack|
|2|2.2 mm measured M8 steel spacer stacks, <=16 mm OD|tower-to-inner-race gaps; combine washers/precision shims or cut tube|
|as needed|M8 precision shims/washers|set both outer stacks to equal measured length|
|1|M8 nyloc nut|pivot retention|

## M6 structural hardware

Buy a zinc-plated assortment of M6x20/25/30/35/40/45, large and standard washers, and at least 20 nyloc nuts. Initial allocation:

- 4 x M6x35 tower-to-base through-bolts.
- 2 x M6x40 lever-to-hub bolts.
- 2 x M6x25 spring-module base bolts.
- 2 x M6x30 spring anchor pins/bolts, one fixed and one moving.
- 1 x M6x45 moving travel-stop pin.
- 2 x M6x25 stop-adjust screws with rubber caps/bumpers and locknuts.
- 4 x M6x30 clamp-interface through-bolts.
- 4 x M6x30 clamp butt-joint through-bolts.
- 2 x M6 rig bolts of length appropriate to the rig plus washers at least 18 mm OD.

## M4/M3 accessory hardware

- 4 x M4x35 plus washers/nylocs for the two stop blocks.
- 2 x M4x30 plus washers/nylocs for Hall fixed bracket.
- 4 x M4x20 plus washers/nylocs for electronics enclosure base.
- 1 x M4x40 plus nyloc for grip retention.
- 4 x M3x20 plus nuts for Hall sled clamping.
- 2 x M3x12 and 1 x M3x20 for magnet holder/keeper.
- 4 x M3x10 and four light-duty heat-set inserts for electronics cover only.
- 2 small M2.5/M3 board screws after the Hall PCB is measured.

## Spring

- Extension-spring assortment: 15–20 mm OD, 60–100 mm hook-to-hook, several light/medium rates.
- Do not buy a costly precision spring yet. P1 hook distances are 69.76–85.82 mm.

## Clamp

- 1 x M10x100 steel screw/bolt or threaded rod with a secure knob attachment.
- 1 x M10 steel coupling nut, nominal 30 mm long, about 17 mm AF; measure actual hardware.
- 1 x common M10 swivel levelling foot or swivel-pad hardware compatible with the 46 mm printed carrier.
- 1 x 46 mm rubber lower pad/disc.
- 1 x approximately 90 x 62 x 2–3 mm upper rubber/neoprene pad.
- M6 clamp fasteners listed above.

## Sensor/electronics

- 1 x SS49E/49E-family linear Hall sensor or small breakout board.
- 1 x 10 x 5 x 3 mm neodymium block magnet candidate; optional 6 x 3 mm disc for comparison.
- 1 x Arduino Pro Micro / ATmega32U4.
- 1 x JST-XH or similar 3-pin connector pair and flexible 3-wire cable.
- USB cable compatible with the selected Pro Micro.
- Heat-shrink, cable tie/strain-relief material, and optional calibration pushbutton/LED for later bench work.

## Tools/consumables

6.6 mm, 4.5 mm and pilot drills; 8 mm reamer or suitable drill; files/deburring tool; hacksaw; square; caliper; thread-locker for metal fasteners where appropriate; luggage scale/force gauge; PETG; rubber-safe adhesive. Adhesive is not a primary structural fastener.

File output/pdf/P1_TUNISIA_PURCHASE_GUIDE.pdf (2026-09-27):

ELKATEB P1.0 - prototype purchasing guide - 27 Sep 2026 | Page 1

# P1.0 Tunisia Purchase and Calibration Guide

Mostly printed sim-racing handbrake - Monday coupon plan, complete hardware list, local suppliers, and

## current price evidence

# Revision 1 - 27 September 2026

Decision: print all eight coupon STLs once. They test different interfaces, not eight alternatives for one dimension. After the winning fits are measured, update the calibration parameters and regenerate P1.1 before printing the structural set.

The functional P1 prototype has 19 printed parts. The number 18 belongs to the later P1-C commercial mixed-material design; do not use 18 when ordering or printing P1.0.

# Budget snapshot

Scope | Planning cash requirement | Confidence
Mechanical hardware only | Approximately 95-170 TND | Engineering allowance; local per-piece quotes needed
Electronics and sensor | Approximately 45-60 TND | Most items have current local listing evidence
Complete purchased hardware | Approximately 150-230 TND | Excludes PETG, delivery, tools and failed prints
PETG consumed by final 19 parts | About 59 TND at 685 g / 86 TND per kg | Engineering mass estimate; actual slicer result controls [S21]
Recommended PETG stock | 2 x 1 kg = about 172 TND | Includes coupons, development and reprint reserve [S21]
Startup cash with two PETG spools | Approximately 322-402 TND | Hardware plus development filament; excludes delivery/tools
Consumed value per successful unit | Likely below cash purchase | Packs, spare bearings and spring trials leave reusable stock

Prices and stock were checked online on 27 September 2026. A displayed price is not a reservation. Call before travelling, especially for exact bolt lengths, springs, magnets, and steel stock.

ELKATEB P1.0 - prototype purchasing guide - 27 Sep 2026 | Page 2

# 1. Monday: print and test all eight coupons

File | What it tests | Physical item required
COUPON_608_POCKETS_DEPTH_7.stl | 608 fit at 7 mm bearing depth | Actual 608-2RS bearing
COUPON_608_POCKETS_DEPTH_14.stl | Deep/two-bearing pocket behaviour | Actual 608-2RS bearing
COUPON_M8_CLEARANCE.stl | 8.0/8.2/8.4/8.6 mm pivot clearances | The actual M8 pivot bolt smooth shank
COUPON_M6_CLEARANCE.stl | 6.0/6.2/6.4/6.6 mm bolt clearances | Representative M6 bolt
COUPON_M6_NUT_TRAPS.stl | 10.0/10.2/10.4/10.6 mm AF nut traps | Actual M6 nuts
COUPON_MAGNET_POCKETS.stl | Nominal/+0.1/+0.2/+0.3 magnet fits | Final candidate magnet
COUPON_HALL_GAP_JIG.stl | 3/5/8/10/12/15 mm sensing experiments | Magnet, SS49E, Pro Micro and multimeter
COUPON_LOADED_BEARING_WALL.stl | Representative bearing-wall strength and cracking | Bearing, M8 bolt, washers and hand load

# After testing

- Record the selected bearing diameter, M8 and M6 hole, M6 nut-trap size, magnet pocket, and printer/material/profile.
- Measure the bearing OD/width, bolt shank diameter, nut across-flats, magnet dimensions, steel-bar thickness, and coupling-nut dimensions with calipers.
- Send the results back. P1 parameters must be updated and P1.1 regenerated. Do not print the old 19 structural files immediately after choosing a coupon.
- After regeneration, print the eight-part mechanical core first. Add sensor/electronics and the six clamp parts only after the core passes no-spring and light-spring tests.

ELKATEB P1.0 - prototype purchasing guide - 27 Sep 2026 | Page 3

# 2. Exact mechanical shopping list

Qty | Item/specification | Use and buying note | Price status
1 | Mild-steel flat bar 25 x 5 x 280 mm | Main lever. Confirm actual 25/5 mm before P1.1. | QUOTE REQUIRED; allow 5-12 TND
2 | Steel strips 25 x 3 x 180 mm | Base reinforcement; four 6.6 mm holes each. | QUOTE REQUIRED; allow 8-18 TND/pair
4 | 608-2RS, 8 x 22 x 7 mm | Two installed and two coupon/spares. | CONFIRMED 3.500 TND each; 14 TND total [S1]
1 | M8 x 90 class 8.8 partially threaded bolt | Pivot. Smooth shank must cross both inner races. | EXACT LENGTH/SHANK QUOTE REQUIRED
1 | 8 ID x about 10 OD x 13.6 mm spacer tube | Between the two bearing inner races. | CUSTOM CUT / 3-8 TND allowance
2 sets | M8 washers/precision shims, 2.2 mm each side | Equal tower-to-bearing spacer stacks, max 16 mm OD. | MEASURE AND SELECT
1 | M8 nyloc nut | Pivot retention; do not overtighten. | Local fastener shop
1 set | Extension springs, 15-20 mm OD, 60-100 mm hook length | Buy several light/medium rates. CAD hook distance is 69.76-85.82 mm. | QUOTE REQUIRED; allow 10-25 TND
1 | M10 x 100 steel screw/rod | Desk clamp; steel thread only. | Local fastener shop; allow 3-7 TND
1 | M10 coupling nut, about 30 mm, about 17 mm AF | Captured clamp thread. Measure before P1.1. | QUOTE REQUIRED; allow 3-8 TND
1 | M10 swivel levelling foot/pad | Lower clamp contact, compatible with 46 mm carrier. | QUOTE REQUIRED; allow 5-15 TND
1+1 | 46 mm lower rubber and 90 x 62 x 2-3 mm upper rubber | Desk protection and grip. | ESTIMATED 5-10 TND

# M6 structural fasteners

Qty | Size | Location
4 | M6 x 35 | Pivot towers through base/backing strips
2 | M6 x 40 | Steel lever through hub
2 | M6 x 25 | Spring module to base
2 | M6 x 30 | Fixed and moving steel spring anchors
1 | M6 x 45 | Moving travel-stop pin
2 | M6 x 25 + rubber tips + locknuts | Adjustable release/full-pull stops
4 | M6 x 30 | Clamp interface through base
4 | M6 x 30 | Clamp butt-joint connections
2 | M6 rig bolts, length to suit rig | Rig mounting with washers at least 18 mm OD
25+ | M6 nyloc nuts | Buy spares
40+ | M6 standard and large washers | Load spreading and adjustment

Budget 20-35 TND for the M6 assortment if bought locally by piece. Online benchmark: Brico Direct lists 10 M6 x 20 stainless bolts at 4.500 TND and 10 M6 nut/washer sets at 2.500 TND; the required lengths still need local confirmation [S2].

ELKATEB P1.0 - prototype purchasing guide - 27 Sep 2026 | Page 4

# 3. Small fasteners and electronics

Qty | Item | Use | Buying note
4 | M4 x 35 + washers + nylocs | Two stop blocks | Buy 6
2 | M4 x 30 + washers + nylocs | Hall fixed bracket | Buy 4
4 | M4 x 20 + washers + nylocs | Electronics enclosure base | Buy 6
1 | M4 x 40 + nyloc | Grip retention | Buy 2
4 | M3 x 20 + nuts | Hall sled clamping | Buy 6
2 + 1 | M3 x 12 and M3 x 20 | Magnet holder/keeper | Buy spares
4 | M3 x 10 + four M3 heat-set inserts | Electronics cover only | Heat-set inserts are not structural
2 | M2.5/M3 board screws | Only after Hall PCB is measured | Do not pre-drill from an assumed board
Qty | Component | Current local evidence | Recommended action
1 | Arduino Pro Micro 5 V / 16 MHz ATmega32U4 | CoThings: 28.000 TND, listed in stock [S3] | Buy 1; USB cable not included
2 | SS49E/49E linear Hall sensor | Didactico: 2.400 TND; 2B Trading: 2.450 TND [S4/S5] | Buy 2 so one is spare
1 pair | 3-pin JST connector/cable | Didactico JST 2.54 pair: 1.500 TND [S6] | Verify pitch before soldering
1 | Micro-USB data cable | Little Son 1 m data/charge cable: 7.500 TND [S7] | Must carry data, not charge-only
1 | 6 mm heat-shrink | Didactico: 2.200 TND [S8] | For 3-wire sensor loom
2 | 10 x 5 x 3 mm NdFeB block magnet | Exact Tunisian listing not confirmed | Current P1 pocket candidate; do not substitute silently
candidate | 20 x 10 x 2 mm rectangular NdFeB magnet | Celectronix: 1.499 TND, listed in stock [S19] | Best locally listed rectangular candidate; requires revised magnet coupon/holder
candidate | 12 x 4 mm circular NdFeB magnet | SELI: 1.800 TND, listed in stock [S20] | Compact local candidate; requires revised magnet coupon/holder
optional | 10 x 2 mm N35 disc magnet | 2B Trading: 1.200 TND [S9] | Experimental alternative only; requires matching pocket/calibration
as needed | Flexible 3-core wire, solder, cable ties | Didactico/CoThings/local electronics | Allow 5-10 TND

ELKATEB P1.0 - prototype purchasing guide - 27 Sep 2026 | Page 5

# 4. Where to buy in Tunisia

Supplier | Useful items | Address/contact | Status
Tunisie Roulements | 608-2RS | 6 Rue Chedly Kallala, Lafayette, Tunis 1002. 71 287 737 / 58 578 870. | 608 listing and price confirmed [S1/S10]
Brico Direct | Fastener packs, nuts, washers, ties, tools | 71bis Avenue Louis Braille, Tunis 1082. 71 100 950. | Prices are benchmarks; call for exact lengths [S2/S11]
SEGEMO - Maison du boulon | M3/M4/M6/M8/M10 bolts, nylocs, washers, shims | 10 Rue Aid Jaberi, Tunis 1000. 71 253 878. | Range confirmed; prices by counter quote [S12]
CoThings | Pro Micro and electronics | Route X, near Stade Bardo, Bardo, Tunis. 29 750 003 / 27 772 264. | Pro Micro price/stock listed [S3/S13]
Little Son | Pro Micro alternative, USB cable, M3 hardware | 1 Rue de Piree, Tunis 1001. 58 114 788. | Pro Micro listed 35 TND; cable 7.5 TND [S7/S14]
Tuni Smart Innovation | SS49E, magnets, heat-shrink | 1 Rue Pierre Mendes France, Ariana 2080. 51 954 443 / 51 954 448. | SS49E in stock; many magnets currently out of stock [S15]
Celectronix | 20 x 10 x 2 mm rectangular magnet, electronics, PETG | Centre Said, Avenue Habib Bourguiba, Megrine. 79 295 570 / 27 582 469 / 28 581 332. | Magnet 1.499 TND; LUME PETG 1 kg 86 TND, listings in stock [S19/S21]
SELI | 12 x 4 mm circular magnet and magnet alternatives | 08 Rue Chedhly Kallela, 1st floor, Boumhel 2097. 29 002 608 / 92 168 725 / 55 560 037. | 12 x 4 magnet listed in stock at 1.800 TND [S20]
Didactico | Hall, JST, heat-shrink, wire | Cite des Martyrs, Rue Mohamed Salah, Imm. Bouzguenda A01, Sfax. 54 776 776 / 99 707 685. | Listings/prices confirmed; delivery in Tunisia [S4/S6/S8/S16]
MTR Ressorts | Extension-spring prototype or small batch | ZI El Ons, Route de Tunis Km 10, Sakiet Ezzit 3021 Sfax. 98 333 883 / 98 331 896. | Local manufacturer; quotation required [S17]
ITI / Ressorts Mohamed Benaissa | Extension spring in Tunis | 11 Rue Abderrahmen Azzem, Montplaisir, Tunis 1002. 71 908 311. | Local manufacturer; quotation required [S18]

# What to say at the quincaillerie

Show the fastener table and say: 'Je veux des vis metriques zinguées ou classe 8.8, avec rondelles et ecrous Nylstop. Pour l'axe M8, il me faut une partie lisse qui traverse deux roulements 608; le filetage ne doit pas rouler dans les bagues.' Ask them to measure the smooth shank before you buy.

For the spring supplier: ask for a small selection of extension springs with closed hooks, 15-20 mm outside diameter and 60-100 mm free hook-to-hook length. Explain that the installed hook distance changes from about 69.8 to 85.8 mm and that the first unit is for force testing, not a production order.
For the magnet: the Celectronix 20 x 10 x 2 mm rectangular magnet is the closest useful locally listed shape, while SELI's 12 x 4 mm disc is the more compact option. Neither is a drop-in fit for the released 10 x 5 x 3 mm pocket. Buy one or two samples if convenient, measure them with calipers, and send the dimensions; only the magnet coupon and holder then need to be revised before structural printing.

ELKATEB P1.0 - prototype purchasing guide - 27 Sep 2026 | Page 6

# 5. Assembly purchase gates

Gate | Must be available/measured | Do not proceed if
Coupon gate | 608, M8 sample, M6 bolt/nut, magnet, printer profile | You cannot physically select the fit
P1.1 regeneration | Winning coupon sizes and real hardware dimensions | The existing P1.0 fit assumptions are still unverified
Mechanical core | Base/towers/hub/grip, steel lever/strips, bearings, pivot stack, stops | Threads touch bearing races or towers spread
Spring gate | Light spring, steel anchors, positive mechanical stops | Spring becomes the travel stop or rubs printed parts
Clamp gate | M10 steel screw/nut, swivel foot, rubber pads | Any primary clamp thread is printed plastic
Sensor gate | Magnet mechanically retained, fixed SS49E, 3-wire loom | Magnet or sensor can collide with the lever
Electronics gate | Pro Micro and data-capable USB cable | Windows does not enumerate the USB HID device

# Important limitations

- Do not buy a precision production spring before the first pull-force test.
- Do not allow threaded M8 sections to act as the bearing journal if a smooth-shank bolt or 8 mm shaft is available.
- Do not print all 19 parts from the uncalibrated P1.0 export merely because one coupon looks correct; all critical coupon results must be transferred into P1.1.
- The listed prices exclude delivery and may change. 'Confirmed' means the retailer displayed the item/price at research time, not that stock has been reserved.
- Structural capacity remains a physical-test question. Stop at cracking, whitening, permanent deformation, bearing movement, or fastener loosening.

ELKATEB P1.0 - prototype purchasing guide - 27 Sep 2026 | Page 7

# 6. Source register

S1 - Tunisie Roulements - 608-2RS, 3.500 TND (https://tunisie-roulements.tn/produit/roulement-608-2rs/) https://tunisie-roulements.tn/produit/roulement-608-2rs/S2 - Brico Direct - visserie listings and pack prices (https://brico-direct.tn/208-vis-et-boulons) https://brico-direct.tn/208-vis-et-boulons
S3 - CoThings - Pro Micro 5V/16MHz, 28.000 TND (https://cothings.net/products/arduino-pro-micro-mini-usb-atmega32u4-5v-16mhz) https://cothings.net/products/arduino-pro-micro-mini-usb-atmega32u4-5v-16mhz
S4 - Didactico - SS49E, 2.400 TND (https://didactico.tn/categorie-produit/capteurs-prototypage/capteurs/capteurs-magnetiques-hall/) https://didactico.tn/categorie-produit/capteurs-prototypage/capteurs/capteurs-magnetiques-hall/S5 - 2B Trading - SS49E, 2.450 TND (https://2btrading.tn/transistor-igbt/4950-capteur-effet-hall-49e-oh49e-ss49e.html) https://2btrading.tn/transistor-igbt/4950-capteur-effet-hall-49e-oh49e-ss49e.html
S6 - Didactico - JST 3-pin pair, 1.500 TND (https://didactico.tn/categorie-produit/connectique-cables-boitiers/) https://didactico.tn/categorie-produit/connectique-cables-boitiers/
S7 - Little Son - 1 m Micro-USB data cable, 7.500 TND (https://little-son.tn/2-accueil?page=2) https://little-son.tn/2-accueil?page=2
S8 - Didactico - 6 mm heat-shrink, 2.200 TND (https://didactico.tn/produit/gaine-thermoretractable-drs-6/) https://didactico.tn/produit/gaine-thermoretractable-drs-6/
S9 - 2B Trading - 10 x 2 mm N35 disc magnet, 1.200 TND (https://2btrading.tn/2-accueil?page=80) https://2btrading.tn/2-accueil?page=80
S10 - Tunisie Roulements contact (https://tunisie-roulements.tn/contact/) https://tunisie-roulements.tn/contact/
S11 - Brico Direct store/contact (https://brico-direct.tn/magasins) https://brico-direct.tn/magasins
S12 - SEGEMO contact (https://www.segemo.tn/contact/)
https://www.segemo.tn/contact/
S13 - CoThings store location (https://cothings.net/pages/emplacement-du-magazin) https://cothings.net/pages/emplacement-du-magazin
S14 - Little Son Pro Micro listing, 35.000 TND (https://little-son.tn/accueil/97-arduino-pro-micro-atmega-32u4.html) https://little-son.tn/accueil/97-arduino-pro-micro-atmega-32u4.html
S15 - Tuni Smart SS49E and store address (https://tuni-smart-innovation.com/products/capteur-a-effet-hall-lineaire-ss49e-oh49e) https://tuni-smart-innovation.com/products/capteur-a-effet-hall-lineaire-ss49e-oh49e S16 - Didactico store/contact (https://didactico.tn/a-propos-didactico/)
https://didactico.tn/a-propos-didactico/
S17 - MTR Ressorts (https://mtr-ressorts.tn/fr)
https://mtr-ressorts.tn/fr
S18 - ITI Tunisie (https://iti.com.tn/presentation/)
https://iti.com.tn/presentation/
S19 - Celectronix - 20 x 10 x 2 mm rectangular neodymium magnet, 1.499 TND, listed in stock (https://www.celectronix.com/autres-mecanique/7498-aimant-cylindrique-de-n-odyme-16-mm-de-diam-tre-x-1-8-mm-d-paisseur-copie-.html) https://www.celectronix.com/autres-mecanique/7498-aimant-cylindrique-de-n-odyme-16-mm-de-diam-tre-x-1-8-mm-d-paisseur-copie-.html S20 - SELI - 12 x 4 mm circular neodymium magnet, 1.800 TND, listed in stock (https://seli.tn/product-category/aimant-et-electro-aimant/) https://seli.tn/product-category/aimant-et-electro-aimant/
S21 - Celectronix - LUME PETG 1.75 mm, 1 kg, 86.000 TND, multiple colors listed in stock (https://www.celectronix.com/filament-petg/8156--074-0-barre-led-tv-lg-43uk6565-7led-3v-44-5cm.html) https://www.celectronix.com/filament-petg/8156--074-0-barre-led-tv-lg-43uk6565-7led-3v-44-5cm.html

Prepared from the released P1.0 BOM and current public Tunisian retailer/manufacturer pages. This is a prototype purchasing plan, not a supplier quotation or guarantee of compatibility.

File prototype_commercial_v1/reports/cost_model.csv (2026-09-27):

item_id | category | description | cost_status | currency | basis | unit_cost_tnd_qty_1 | unit_cost_tnd_qty_5 | unit_cost_tnd_qty_10 | unit_cost_tnd_qty_25 | unit_cost_tnd_qty_50
C01 | steel sheet | S235/ST37/DC01 sheet share | UNKNOWN_RFQ | TND | planning allowance; replace with supplier quote | 9.9 | 7.5 | 6.6 | 6.0 | 5.52
C02 | aluminium sheet | 2 mm accent share | UNKNOWN_RFQ | TND | planning allowance; replace with supplier quote | 3.3 | 2.5 | 2.2 | 2.0 | 1.84
C03 | laser cutting | 8 sheet parts | UNKNOWN_RFQ | TND | planning allowance; replace with supplier quote | 13.2 | 10.0 | 8.8 | 8.0 | 7.36
C04 | bending | base, frames, spring bracket, clamp | UNKNOWN_RFQ | TND | planning allowance; replace with supplier quote | 9.9 | 7.5 | 6.6 | 6.0 | 5.52
C05 | deburring | all visible edges | UNKNOWN_RFQ | TND | planning allowance; replace with supplier quote | 3.3 | 2.5 | 2.2 | 2.0 | 1.84
C06 | powder coating | black steel set | UNKNOWN_RFQ | TND | planning allowance; replace with supplier quote | 11.55 | 8.75 | 7.7 | 7.0 | 6.44
C07 | aluminium finishing | directional brush/clear | UNKNOWN_RFQ | TND | planning allowance; replace with supplier quote | 3.3 | 2.5 | 2.2 | 2.0 | 1.84
C08 | bearings | 2 x 608 | ESTIMATED | TND | planning allowance; replace with supplier quote | 6.6 | 5.0 | 4.4 | 4.0 | 3.68
C09 | pivot | M8 partial-thread bolt, spacers, nyloc | ESTIMATED | TND | planning allowance; replace with supplier quote | 4.12 | 3.12 | 2.75 | 2.5 | 2.3
C10 | spring | extension spring | ESTIMATED | TND | planning allowance; replace with supplier quote | 4.95 | 3.75 | 3.3 | 3.0 | 2.76
C11 | grip | commodity rubber grip plus tube | ESTIMATED | TND | planning allowance; replace with supplier quote | 13.2 | 10.0 | 8.8 | 8.0 | 7.36
C12 | fasteners | standardized M3/M4/M6 | ESTIMATED | TND | planning allowance; replace with supplier quote | 13.2 | 10.0 | 8.8 | 8.0 | 7.36
C13 | magnet | 10x5x3 block | ESTIMATED | TND | planning allowance; replace with supplier quote | 1.32 | 1.0 | 0.88 | 0.8 | 0.74
C14 | Hall sensor | 49E breakout | ESTIMATED | TND | planning allowance; replace with supplier quote | 2.47 | 1.88 | 1.65 | 1.5 | 1.38
C15 | electronics | Pro Micro alpha allowance | ESTIMATED | TND | planning allowance; replace with supplier quote | 24.75 | 18.75 | 16.5 | 15.0 | 13.8
C16 | USB | cable/port allowance | ESTIMATED | TND | planning allowance; replace with supplier quote | 3.3 | 2.5 | 2.2 | 2.0 | 1.84
C17 | clamp hardware | M10 screw, coupling nut, pad | ESTIMATED | TND | planning allowance; replace with supplier quote | 9.9 | 7.5 | 6.6 | 6.0 | 5.52
C18 | printed components | PETG/ASA internal set | ESTIMATED | TND | planning allowance; replace with supplier quote | 6.6 | 5.0 | 4.4 | 4.0 | 3.68
C19 | assembly | planning allowance | ESTIMATED | TND | planning allowance; replace with supplier quote | 13.2 | 10.0 | 8.8 | 8.0 | 7.36
C20 | packaging | planning allowance | ESTIMATED | TND | planning allowance; replace with supplier quote | 8.25 | 6.25 | 5.5 | 5.0 | 4.6

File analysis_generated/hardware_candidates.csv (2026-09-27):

model | candidate | quantity | evidence_status | evidence | source_path | audit_comment
Chinese generic | M8 fastener family | multiple / occurrence count unknown | VERIFIED filenames; geometry UNKNOWN | 8 mm bolts, nuts, washers named in files | chinese-generic-sim-handbrake-model-1.snapshot.1 | Do not order from filename evidence alone; assembly quantities and fit are unavailable.
Chinese generic | M5 and M3 fasteners | multiple / occurrence count unknown | VERIFIED filenames; geometry UNKNOWN | M5/M3 hardware part definitions | chinese-generic-sim-handbrake-model-1.snapshot.1 | Quantities unknown.
Fanatec reference | 7/8/12 mm concentric pivot/boss features | candidate only | VERIFIED geometry | STEP cylindrical faces | fanatec-handbrake-1.snapshot.1/FANATEC Handbrake down.step | No BOM; do not equate these automatically to a specific bearing or bolt.
DIY v1.2 | F696ZZ flanged bearing (6 x 15 x 5 mm, 17 mm flange OD) | 4 | VERIFIED | BOM name/quantity and STEP named occurrences | handbrake-for-sim-racing-diy-1.snapshot.48 | Strong reference for compact paired pivots; less common than 608.
DIY v1.2 | M6 DIN 912 socket-head screws | 14 across 12/16/35/40/55 mm lengths | VERIFIED BOM image | rows 1-5 | handbrake-for-sim-racing-diy-1.snapshot.48/Cutting; flexion; electronics and information/fasteners and accessories.png | STEP occurrence names corroborate several lengths.
DIY v1.2 | M8 socket/hex screws | 2 documented plus M8x170 modeled shaft | CONFLICT | BOM says M8x45 and M8x55; STEP names M8x40 and M8X170 | handbrake-for-sim-racing-diy-1.snapshot.48 | Physically verify before ordering.
DIY v1.2 | DIN 985 M6 nyloc nuts | 11 | VERIFIED documentation | hardware-list image | handbrake-for-sim-racing-diy-1.snapshot.48/Cutting; flexion; electronics and information/fasteners and accessories.png
DIY v1.2 | PHS8 rod end | 1 | VERIFIED | BOM and STEP named occurrence | handbrake-for-sim-racing-diy-1.snapshot.48 | Adds cost and complexity; not recommended for P1.
DIY v1.2 | compression spring 20 x 51 light | 1 | VERIFIED documentation | hardware-list image | handbrake-for-sim-racing-diy-1.snapshot.48/Cutting; flexion; electronics and information/fasteners and accessories.png | Spring rate/preload are not documented.
DIY v1.2 | magnet 5 x 4 x 2 mm | 1 | VERIFIED documentation | hardware-list image; STEP volume corroboration | handbrake-for-sim-racing-diy-1.snapshot.48 | Works with AS5600 arrangement; magnet grade/polarization is undocumented.
DIY v1.2 | AS5600-ASOT sensor PCB | 1 | VERIFIED documentation | PCB BOM | handbrake-for-sim-racing-diy-1.snapshot.48/Cutting; flexion; electronics and information/electronics/AS5600_analog_pcb/BOM_PCB_AS5600_pcb.csv | PCB BOM says C2=10uF while pick-and-place comment says C2=1uF; resolve before fabrication.
Hydraulic | 8 x 27 mm pivot pin | 1 | VERIFIED geometry | named Shtift occurrence | hydraulic-handbrake-1.snapshot.2/Handbrake.stp | Appears custom; a standard M8 shoulder/part-thread bolt is preferable for P1.
Hydraulic | custom flanged bushings | 2 | VERIFIED geometry | two Durjach occurrences | hydraulic-handbrake-1.snapshot.2/Handbrake.stp | 8 mm bore, 16 mm neck, 32 mm flange; not a cheap off-the-shelf choice unless a matching bushing is sourced.
Hydraulic | hydraulic cylinder/piston/link | 1 set | VERIFIED geometry | PompaTqlo, Butalo, ArmButalo occurrences | hydraulic-handbrake-1.snapshot.2/Handbrake.stp | Major cost and fabrication driver; reject for P1.
MOZA low-poly | hardware | UNKNOWN | UNKNOWN | No recoverable component structure | moza-hbp-handbrake-low-poly-1.snapshot.1 | Do not infer BOM from exterior low-poly body.

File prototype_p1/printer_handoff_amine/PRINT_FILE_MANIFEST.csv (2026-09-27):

batch | part_id | filename | quantity | print_now | oriented_width_mm | oriented_depth_mm | oriented_height_mm | native_bbox_x_mm | native_bbox_y_mm | native_bbox_z_mm | recommended_orientation | support_or_brim_review | exact_stl_volume_cm3 | engineering_estimate_50pct_g | estimate_status | source_relative_path | handoff_relative_path | source_sha256 | copy_sha256 | hashes_match
01_CALIBRATION_FIRST | CAL-608-07 | COUPON_608_POCKETS_DEPTH_7.stl | 1 | YES - CALIBRATION FIRST | 150.0 | 34.0 | 11.0 | 150.0 | 34.0 | 11.0 | Flat base on bed; 7 mm pockets upward | No support expected; not slicer-verified | 39.954 | 45.089 | ENGINEERING ESTIMATE ONLY - REPLACE WITH REAL SLICER RESULT | coupons/COUPON_608_POCKETS_DEPTH_7.stl | 01_CALIBRATION_FIRST/COUPON_608_POCKETS_DEPTH_7.stl | 03c745782fe689825a7cbbdef4658112b868f30e656a21a747d0c5c5d9b8532f | 03c745782fe689825a7cbbdef4658112b868f30e656a21a747d0c5c5d9b8532f | True
01_CALIBRATION_FIRST | CAL-608-14 | COUPON_608_POCKETS_DEPTH_14.stl | 1 | YES - CALIBRATION FIRST | 150.0 | 34.0 | 18.0 | 150.0 | 34.0 | 18.0 | Flat base on bed; 14 mm pockets upward | No support expected; not slicer-verified | 59.508 | 66.929 | ENGINEERING ESTIMATE ONLY - REPLACE WITH REAL SLICER RESULT | coupons/COUPON_608_POCKETS_DEPTH_14.stl | 01_CALIBRATION_FIRST/COUPON_608_POCKETS_DEPTH_14.stl | fec1c8ddbab1f6f05db7726a3c13c188b5d764ec9d7d2c3ed05ba40da446898d | fec1c8ddbab1f6f05db7726a3c13c188b5d764ec9d7d2c3ed05ba40da446898d | True
01_CALIBRATION_FIRST | CAL-M8 | COUPON_M8_CLEARANCE.stl | 1 | YES - CALIBRATION FIRST | 72.0 | 24.0 | 8.0 | 72.0 | 24.0 | 8.0 | Flat base on bed; test bores vertical | No support expected; not slicer-verified | 12.093 | 14.046 | ENGINEERING ESTIMATE ONLY - REPLACE WITH REAL SLICER RESULT | coupons/COUPON_M8_CLEARANCE.stl | 01_CALIBRATION_FIRST/COUPON_M8_CLEARANCE.stl | acea6d9bc33709af6f669f5804a722c6365f3773a5b2833c268d81c286412223 | acea6d9bc33709af6f669f5804a722c6365f3773a5b2833c268d81c286412223 | True
01_CALIBRATION_FIRST | CAL-M6 | COUPON_M6_CLEARANCE.stl | 1 | YES - CALIBRATION FIRST | 72.0 | 24.0 | 8.0 | 72.0 | 24.0 | 8.0 | Flat base on bed; test bores vertical | No support expected; not slicer-verified | 12.826 | 14.307 | ENGINEERING ESTIMATE ONLY - REPLACE WITH REAL SLICER RESULT | coupons/COUPON_M6_CLEARANCE.stl | 01_CALIBRATION_FIRST/COUPON_M6_CLEARANCE.stl | a45a1f484062f4d1742d5dd62db5c42a69b7841a0a3b455385c0e0b480f713bb | a45a1f484062f4d1742d5dd62db5c42a69b7841a0a3b455385c0e0b480f713bb | True
01_CALIBRATION_FIRST | CAL-M6-NUT | COUPON_M6_NUT_TRAPS.stl | 1 | YES - CALIBRATION FIRST | 80.0 | 26.0 | 8.0 | 80.0 | 26.0 | 8.0 | Largest flat face on bed; nut traps upward | No support expected; not slicer-verified | 14.802 | 16.7 | ENGINEERING ESTIMATE ONLY - REPLACE WITH REAL SLICER RESULT | coupons/COUPON_M6_NUT_TRAPS.stl | 01_CALIBRATION_FIRST/COUPON_M6_NUT_TRAPS.stl | 8bf992f34273020b3f0a4385d49f491d4425208a942c5c6a0fd9b34dd41a98a3 | 8bf992f34273020b3f0a4385d49f491d4425208a942c5c6a0fd9b34dd41a98a3 | True
01_CALIBRATION_FIRST | CAL-MAG | COUPON_MAGNET_POCKETS.stl | 1 | YES - CALIBRATION FIRST | 70.0 | 22.0 | 7.0 | 70.0 | 22.0 | 7.0 | Largest flat face on bed; pockets upward | No support expected; not slicer-verified | 10.153 | 11.632 | ENGINEERING ESTIMATE ONLY - REPLACE WITH REAL SLICER RESULT | coupons/COUPON_MAGNET_POCKETS.stl | 01_CALIBRATION_FIRST/COUPON_MAGNET_POCKETS.stl | b7efe489757b91e938b128f35b5b1812ac2b652687212b417774eb41abb63477 | b7efe489757b91e938b128f35b5b1812ac2b652687212b417774eb41abb63477 | True
01_CALIBRATION_FIRST | CAL-HALL | COUPON_HALL_GAP_JIG.stl | 1 | YES - CALIBRATION FIRST | 104.0 | 35.0 | 18.0 | 104.0 | 35.0 | 18.0 | Largest flat face on bed | No support expected; not slicer-verified | 19.4 | 24.638 | ENGINEERING ESTIMATE ONLY - REPLACE WITH REAL SLICER RESULT | coupons/COUPON_HALL_GAP_JIG.stl | 01_CALIBRATION_FIRST/COUPON_HALL_GAP_JIG.stl | 5512066bad1f762f857f08abed054e81d96671dd79bf90ed8b86fe1f8a02b634 | 5512066bad1f762f857f08abed054e81d96671dd79bf90ed8b86fe1f8a02b634 | True
01_CALIBRATION_FIRST | CAL-BEAR-WALL | COUPON_LOADED_BEARING_WALL.stl | 1 | YES - CALIBRATION FIRST | 79.0 | 48.0 | 20.0 | 78.983 | 20.0 | 47.97 | Broad side face on bed; bearing axis horizontal | No support expected; not slicer-verified | 42.048 | 39.618 | ENGINEERING ESTIMATE ONLY - REPLACE WITH REAL SLICER RESULT | coupons/COUPON_LOADED_BEARING_WALL.stl | 01_CALIBRATION_FIRST/COUPON_LOADED_BEARING_WALL.stl | 39139e1081f35cd304ed171bd00f9997746f2e17cfb44fd47b8877f2abf22147 | 39139e1081f35cd304ed171bd00f9997746f2e17cfb44fd47b8877f2abf22147 | True
02_MECHANICAL_CORE_AFTER_CALIBRATION | P1-001 | P1-001_BASE.stl | 1 | NO - SLICER CHECK ONLY UNTIL CALIBRATION | 180.0 | 84.0 | 10.0 | 180.0 | 84.0 | 10.0 | Primary flat face on bed; steel recesses upward | No support expected; not slicer-verified | 114.031 | 113.269 | ENGINEERING ESTIMATE ONLY - REPLACE WITH REAL SLICER RESULT | stl/P1-001_BASE.stl | 02_MECHANICAL_CORE_AFTER_CALIBRATION/P1-001_BASE.stl | 7d3f568f87418e701f87bb2133e61aa9956ca6baeaa2b58afc2e1612160d71bc | 7d3f568f87418e701f87bb2133e61aa9956ca6baeaa2b58afc2e1612160d71bc | True
02_MECHANICAL_CORE_AFTER_CALIBRATION | P1-002 | P1-002_LEFT_PIVOT_SUPPORT.stl | 1 | NO - SLICER CHECK ONLY UNTIL CALIBRATION | 56.0 | 93.0 | 18.0 | 56.0 | 18.0 | 92.999 | Outer Y face on bed | No support expected; ream holes after printing | 65.555 | 60.824 | ENGINEERING ESTIMATE ONLY - REPLACE WITH REAL SLICER RESULT | stl/P1-002_LEFT_PIVOT_SUPPORT.stl | 02_MECHANICAL_CORE_AFTER_CALIBRATION/P1-002_LEFT_PIVOT_SUPPORT.stl | 3ece810536d0b1a00b37a84ddcdd0278d14cd3753d148b4bccc6602e0fd0750a | 3ece810536d0b1a00b37a84ddcdd0278d14cd3753d148b4bccc6602e0fd0750a | True
02_MECHANICAL_CORE_AFTER_CALIBRATION | P1-003 | P1-003_RIGHT_PIVOT_SUPPORT.stl | 1 | NO - SLICER CHECK ONLY UNTIL CALIBRATION | 56.0 | 93.0 | 18.0 | 56.0 | 18.0 | 92.981 | Outer Y face on bed | No support expected; not slicer-verified | 68.848 | 60.88 | ENGINEERING ESTIMATE ONLY - REPLACE WITH REAL SLICER RESULT | stl/P1-003_RIGHT_PIVOT_SUPPORT.stl | 02_MECHANICAL_CORE_AFTER_CALIBRATION/P1-003_RIGHT_PIVOT_SUPPORT.stl | d33b2840a2cefd0b4a418b5e867b903083d8c624c9bc798de16634a69c65bce5 | d33b2840a2cefd0b4a418b5e867b903083d8c624c9bc798de16634a69c65bce5 | True
02_MECHANICAL_CORE_AFTER_CALIBRATION | P1-004 | P1-004_LEVER_ROOT_BEARING_HUB.stl | 1 | NO - SLICER CHECK ONLY UNTIL CALIBRATION | 124.0 | 64.0 | 28.0 | 124.0 | 28.0 | 63.996 | One bearing face on bed | Conditional local support in accessible lever slot if bridging is poor | 103.151 | 96.539 | ENGINEERING ESTIMATE ONLY - REPLACE WITH REAL SLICER RESULT | stl/P1-004_LEVER_ROOT_BEARING_HUB.stl | 02_MECHANICAL_CORE_AFTER_CALIBRATION/P1-004_LEVER_ROOT_BEARING_HUB.stl | fdd2fb970541168679b43921fe03a7c77aaa798b2d4cae33f63ee91b56e3afc3 | fdd2fb970541168679b43921fe03a7c77aaa798b2d4cae33f63ee91b56e3afc3 | True
02_MECHANICAL_CORE_AFTER_CALIBRATION | P1-006 | P1-006_GRIP.stl | 1 | NO - SLICER CHECK ONLY UNTIL CALIBRATION | 34.0 | 34.0 | 110.0 | 110.0 | 34.0 | 34.0 | Upright on end with brim | No support expected; brim material is excluded | 83.561 | 86.654 | ENGINEERING ESTIMATE ONLY - REPLACE WITH REAL SLICER RESULT | stl/P1-006_GRIP.stl | 02_MECHANICAL_CORE_AFTER_CALIBRATION/P1-006_GRIP.stl | 2f8eca25749fec4d07d078b8fde875b64c29011db662e368009af32c5f05a473 | 2f8eca25749fec4d07d078b8fde875b64c29011db662e368009af32c5f05a473 | True
02_MECHANICAL_CORE_AFTER_CALIBRATION | P1-007 | P1-007_SPRING_ANCHOR_MODULE.stl | 1 | NO - SLICER CHECK ONLY UNTIL CALIBRATION | 40.0 | 24.0 | 22.0 | 40.0 | 24.0 | 22.0 | Foot on bed | No support expected; not slicer-verified | 10.483 | 13.313 | ENGINEERING ESTIMATE ONLY - REPLACE WITH REAL SLICER RESULT | stl/P1-007_SPRING_ANCHOR_MODULE.stl | 02_MECHANICAL_CORE_AFTER_CALIBRATION/P1-007_SPRING_ANCHOR_MODULE.stl | cadcfc8e742066737f4309b49ce5dbb3fd6441a4c06b5b7be459606a04f1e37f | cadcfc8e742066737f4309b49ce5dbb3fd6441a4c06b5b7be459606a04f1e37f | True
02_MECHANICAL_CORE_AFTER_CALIBRATION | P1-008 | P1-008_RELEASE_STOP.stl | 1 | NO - SLICER CHECK ONLY UNTIL CALIBRATION | 18.7 | 22.9 | 8.0 | 18.699 | 8.0 | 22.942 | Outer Y face on bed | No support expected; not slicer-verified | 1.499 | 1.903 | ENGINEERING ESTIMATE ONLY - REPLACE WITH REAL SLICER RESULT | stl/P1-008_RELEASE_STOP.stl | 02_MECHANICAL_CORE_AFTER_CALIBRATION/P1-008_RELEASE_STOP.stl | af583dba5b5272301dc3543f9261e296c888336032107249bbbd8e9a7accc58f | af583dba5b5272301dc3543f9261e296c888336032107249bbbd8e9a7accc58f | True
02_MECHANICAL_CORE_AFTER_CALIBRATION | P1-009 | P1-009_FULL_PULL_STOP.stl | 1 | NO - SLICER CHECK ONLY UNTIL CALIBRATION | 23.6 | 24.3 | 8.0 | 23.58 | 8.0 | 24.32 | Outer Y face on bed | No support expected; not slicer-verified | 1.499 | 1.903 | ENGINEERING ESTIMATE ONLY - REPLACE WITH REAL SLICER RESULT | stl/P1-009_FULL_PULL_STOP.stl | 02_MECHANICAL_CORE_AFTER_CALIBRATION/P1-009_FULL_PULL_STOP.stl | 29eb4b6f816d3745f068a8714673eabbfcf7129c582d424dfeb44e9340bdfd08 | 29eb4b6f816d3745f068a8714673eabbfcf7129c582d424dfeb44e9340bdfd08 | True
03_SENSOR_AND_ELECTRONICS | P1-010 | P1-010_MAGNET_HOLDER.stl | 1 | NO - SLICER CHECK ONLY UNTIL CALIBRATION | 22.4 | 43.0 | 12.0 | 22.406 | 12.0 | 43.033 | Inner arm face on bed | Conditional small local support at magnet cup | 2.877 | 3.653 | ENGINEERING ESTIMATE ONLY - REPLACE WITH REAL SLICER RESULT | stl/P1-010_MAGNET_HOLDER.stl | 03_SENSOR_AND_ELECTRONICS/P1-010_MAGNET_HOLDER.stl | 4ef32b2925b7f8e67ff1258b3a879526dd4fc01d3a88a4708130dd9d295696dc | 4ef32b2925b7f8e67ff1258b3a879526dd4fc01d3a88a4708130dd9d295696dc | True
03_SENSOR_AND_ELECTRONICS | P1-011A | P1-011A_HALL_FIXED_BRACKET.stl | 1 | NO - SLICER CHECK ONLY UNTIL CALIBRATION | 31.0 | 15.0 | 35.0 | 31.0 | 15.0 | 35.0 | Largest flat face on bed | Conditional; inspect rail bridges in slicer | 3.536 | 4.49 | ENGINEERING ESTIMATE ONLY - REPLACE WITH REAL SLICER RESULT | stl/P1-011A_HALL_FIXED_BRACKET.stl | 03_SENSOR_AND_ELECTRONICS/P1-011A_HALL_FIXED_BRACKET.stl | 2a24a56ae5b428954ad75278e96f6084764ceea2bf5d929a86d09302d3874a98 | 2a24a56ae5b428954ad75278e96f6084764ceea2bf5d929a86d09302d3874a98 | True
03_SENSOR_AND_ELECTRONICS | P1-011B | P1-011B_HALL_SENSOR_SLED.stl | 1 | NO - SLICER CHECK ONLY UNTIL CALIBRATION | 14.0 | 8.6 | 22.0 | 14.0 | 8.6 | 22.0 | Largest flat face on bed | Conditional; inspect rail bridges in slicer | 1.182 | 1.501 | ENGINEERING ESTIMATE ONLY - REPLACE WITH REAL SLICER RESULT | stl/P1-011B_HALL_SENSOR_SLED.stl | 03_SENSOR_AND_ELECTRONICS/P1-011B_HALL_SENSOR_SLED.stl | faaf35854f912099b6aab75200709689203c462580d826ea27928bb35cb53ea7 | faaf35854f912099b6aab75200709689203c462580d826ea27928bb35cb53ea7 | True
03_SENSOR_AND_ELECTRONICS | P1-012 | P1-012_ELECTRONICS_ENCLOSURE.stl | 1 | NO - SLICER CHECK ONLY UNTIL CALIBRATION | 50.0 | 38.0 | 28.0 | 50.0 | 38.0 | 28.0 | Enclosure bottom on bed | No support expected; not slicer-verified | 14.211 | 18.048 | ENGINEERING ESTIMATE ONLY - REPLACE WITH REAL SLICER RESULT | stl/P1-012_ELECTRONICS_ENCLOSURE.stl | 03_SENSOR_AND_ELECTRONICS/P1-012_ELECTRONICS_ENCLOSURE.stl | ed7c4f9fb4d958f83470d6feea1055f90ead839dda68e5096f0073fc7a1f9c42 | ed7c4f9fb4d958f83470d6feea1055f90ead839dda68e5096f0073fc7a1f9c42 | True
03_SENSOR_AND_ELECTRONICS | P1-013 | P1-013_ELECTRONICS_COVER.stl | 1 | NO - SLICER CHECK ONLY UNTIL CALIBRATION | 50.0 | 38.0 | 5.0 | 50.0 | 38.0 | 5.0 | Outer top face on bed | No support expected; not slicer-verified | 8.36 | 9.829 | ENGINEERING ESTIMATE ONLY - REPLACE WITH REAL SLICER RESULT | stl/P1-013_ELECTRONICS_COVER.stl | 03_SENSOR_AND_ELECTRONICS/P1-013_ELECTRONICS_COVER.stl | 6881f13fea1b21b6084ececef6404475b6fb8f2251bf553d2b661a67b314ded7 | 6881f13fea1b21b6084ececef6404475b6fb8f2251bf553d2b661a67b314ded7 | True
04_TABLE_CLAMP | P1-020 | P1-020_CLAMP_BASE_INTERFACE.stl | 1 | NO - SLICER CHECK ONLY UNTIL CALIBRATION | 64.0 | 72.0 | 8.0 | 64.0 | 72.0 | 8.0 | Large face on bed | No support expected; not slicer-verified | 35.225 | 34.352 | ENGINEERING ESTIMATE ONLY - REPLACE WITH REAL SLICER RESULT | stl/P1-020_CLAMP_BASE_INTERFACE.stl | 04_TABLE_CLAMP/P1-020_CLAMP_BASE_INTERFACE.stl | 704b0e0a19f7306e9b999f16eaeb565e3f8a5c68c4a7c39dbd7067b526a7b62f | 704b0e0a19f7306e9b999f16eaeb565e3f8a5c68c4a7c39dbd7067b526a7b62f | True
04_TABLE_CLAMP | P1-021 | P1-021_CLAMP_VERTICAL_BRACKET.stl | 1 | NO - SLICER CHECK ONLY UNTIL CALIBRATION | 64.0 | 114.0 | 34.0 | 34.0 | 64.0 | 114.0 | Large X face on bed; ribs upward | No support expected; not slicer-verified | 78.804 | 71.985 | ENGINEERING ESTIMATE ONLY - REPLACE WITH REAL SLICER RESULT | stl/P1-021_CLAMP_VERTICAL_BRACKET.stl | 04_TABLE_CLAMP/P1-021_CLAMP_VERTICAL_BRACKET.stl | 5be288ad2acd772f35f3997dbcd6a93793d1c1c5dd789d55d2703b6d49ed6200 | 5be288ad2acd772f35f3997dbcd6a93793d1c1c5dd789d55d2703b6d49ed6200 | True
04_TABLE_CLAMP | P1-022 | P1-022_CLAMP_SCREW_GUIDE.stl | 1 | NO - SLICER CHECK ONLY UNTIL CALIBRATION | 76.0 | 32.0 | 38.0 | 76.0 | 32.0 | 38.0 | Lower arm face on bed; hex pocket vertical | No support expected; not slicer-verified | 44.68 | 45.296 | ENGINEERING ESTIMATE ONLY - REPLACE WITH REAL SLICER RESULT | stl/P1-022_CLAMP_SCREW_GUIDE.stl | 04_TABLE_CLAMP/P1-022_CLAMP_SCREW_GUIDE.stl | 18c958e08b6a9e34076abe3b63c6ca0cfef117c2a75bb30bde06b5b187fcddc3 | 18c958e08b6a9e34076abe3b63c6ca0cfef117c2a75bb30bde06b5b187fcddc3 | True
04_TABLE_CLAMP | P1-023 | P1-023_CLAMP_KNOB.stl | 1 | NO - SLICER CHECK ONLY UNTIL CALIBRATION | 52.0 | 47.2 | 18.0 | 52.0 | 47.177 | 18.0 | Flat face on bed | No support expected; not slicer-verified | 27.178 | 27.105 | ENGINEERING ESTIMATE ONLY - REPLACE WITH REAL SLICER RESULT | stl/P1-023_CLAMP_KNOB.stl | 04_TABLE_CLAMP/P1-023_CLAMP_KNOB.stl | 293e2df5490c225dcfac7b6f6c2054998baaefb52b8573d215b693dd5aca3c75 | 293e2df5490c225dcfac7b6f6c2054998baaefb52b8573d215b693dd5aca3c75 | True
04_TABLE_CLAMP | P1-024 | P1-024_SWIVEL_PAD_HOLDER.stl | 1 | NO - SLICER CHECK ONLY UNTIL CALIBRATION | 46.0 | 46.0 | 8.0 | 46.0 | 46.0 | 8.0 | Flat face on bed | No support expected; not slicer-verified | 11.592 | 12.42 | ENGINEERING ESTIMATE ONLY - REPLACE WITH REAL SLICER RESULT | stl/P1-024_SWIVEL_PAD_HOLDER.stl | 04_TABLE_CLAMP/P1-024_SWIVEL_PAD_HOLDER.stl | 77d08ccccb9306104827d49ed7af3da0a2cccd4248705aa5bc9385f25c9a2214 | 77d08ccccb9306104827d49ed7af3da0a2cccd4248705aa5bc9385f25c9a2214 | True
04_TABLE_CLAMP | P1-025 | P1-025_UPPER_RUBBER_PAD_HOLDER.stl | 1 | NO - SLICER CHECK ONLY UNTIL CALIBRATION | 90.0 | 62.0 | 3.0 | 90.0 | 62.0 | 3.0 | Large face on bed | No support expected; not slicer-verified | 16.505 | 20.871 | ENGINEERING ESTIMATE ONLY - REPLACE WITH REAL SLICER RESULT | stl/P1-025_UPPER_RUBBER_PAD_HOLDER.stl | 04_TABLE_CLAMP/P1-025_UPPER_RUBBER_PAD_HOLDER.stl | ceb9043c667ff0081b4425448c7b5724120bfc864e797eac71b6a9552a602a2a | ceb9043c667ff0081b4425448c7b5724120bfc864e797eac71b6a9552a602a2a | True

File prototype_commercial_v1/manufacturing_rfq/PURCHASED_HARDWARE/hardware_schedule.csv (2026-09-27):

item | qty_per_unit | specification
608 bearing | 2 | 8x22x7 mm
M8 partial-thread pivot | 1 | 80 mm candidate; smooth shank through races
M8 nyloc + washers/spacers | 1 | stack to measured frame gap
M6 lever clamp bolt + nyloc | 2 | through hub and 5 mm lever
M6 frame/base bolt + nyloc | 4 | black visible head
M6 spring eye/pin | 2 | steel
M6 adjustable stop | 2 | steel plus rubber tip
M4 accent button-head | 6 | black, consistent style
M4 electronics pod mount | 4 | black
M3 Hall/lid fastener | 6 | black
M10 clamp screw | 1 | 120 mm candidate
M10 coupling nut | 1 | 30 mm candidate, retained/welded in steel bracket
Swivel clamp foot | 1 | 40-50 mm rubber-faced
Extension spring | 1 | OD <=18, hook length 60-100 trial set
Magnet | 1 | 10x5x3 mm candidate
49E Hall board | 1 | measure actual
Pro Micro | 1 | temporary alpha
Grip | 1 | Ø34 x 112 target

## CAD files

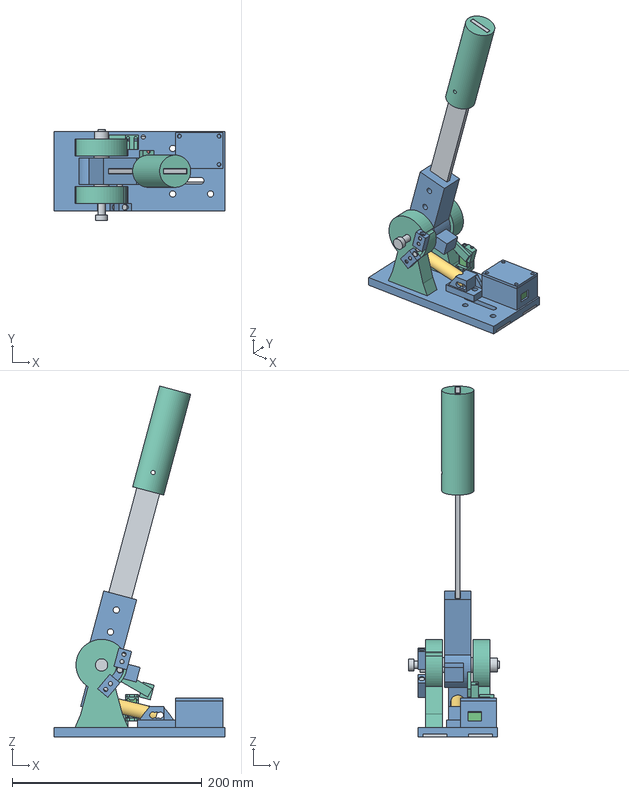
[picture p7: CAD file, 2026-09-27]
prototype_p1/step/P1_ASSEMBLY.step
180.0 x 96.0 x 370.2 mm
P1-001_BASE
P1-030_LEFT_BACKING_STRIP
P1-031_RIGHT_BACKING_STRIP
P1-002_LEFT_PIVOT_SUPPORT
P1-003_RIGHT_PIVOT_SUPPORT
P1-007_SPRING_ANCHOR_MODULE
P1-008_RELEASE_STOP
P1-009_FULL_PULL_STOP
P1-012_ELECTRONICS_ENCLOSURE
P1-013_ELECTRONICS_COVER
P1-004_HUB
P1-005_STEEL_LEVER
P1-006_GRIP
P1-010_MAGNET_HOLDER
HW_MAGNET
P1-011A_HALL_FIXED_BRACKET
P1-011B_HALL_SENSOR_SLED
HW_HALL_PCB
HW_EXTENSION_SPRING_ENVELOPE
HW_STOP_PIN
HW_M6_STOP_SCREW_1
HW_M6_STOP_SCREW_2
HW_608_LEFT
HW_608_RIGHT
HW_INNER_RACE_SPACER
HW_AXIAL_SPACER_LEFT
HW_AXIAL_SPACER_RIGHT
HW_M8X90_PIVOT
HW_M8_BOLT_HEAD
HW_M8_NYLOC
HW_PRO_MICRO_ENVELOPE

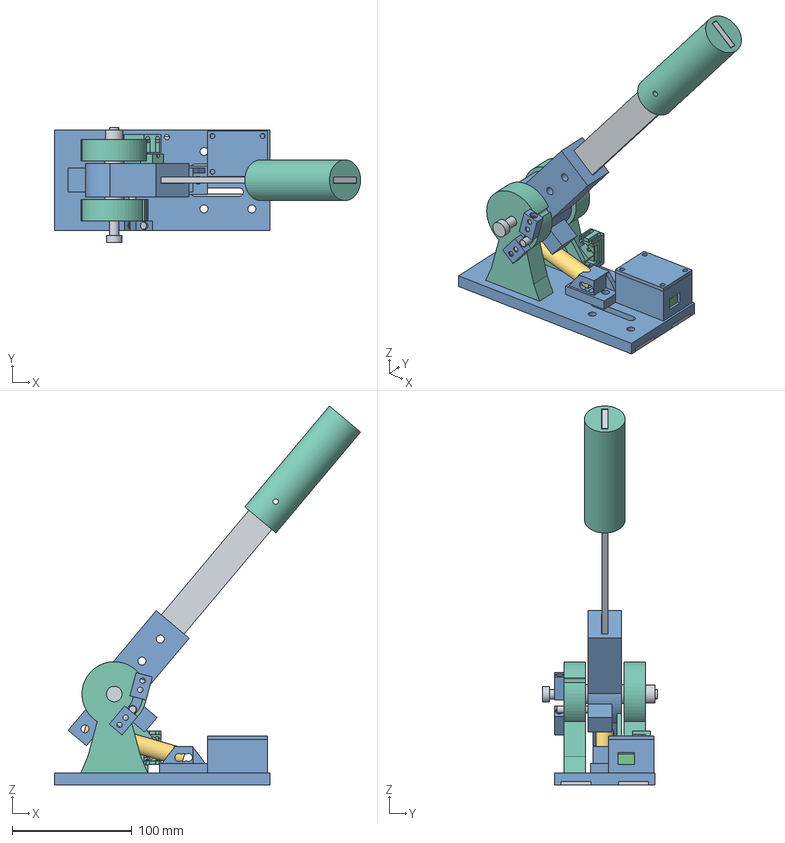
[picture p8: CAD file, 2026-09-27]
prototype_p1/step/P1_FULL_PULL.step
255.8 x 96.0 x 316.7 mm
P1-001_BASE
P1-030_LEFT_BACKING_STRIP
P1-031_RIGHT_BACKING_STRIP
P1-002_LEFT_PIVOT_SUPPORT
P1-003_RIGHT_PIVOT_SUPPORT
P1-007_SPRING_ANCHOR_MODULE
P1-008_RELEASE_STOP
P1-009_FULL_PULL_STOP
P1-012_ELECTRONICS_ENCLOSURE
P1-013_ELECTRONICS_COVER
P1-004_HUB
P1-005_STEEL_LEVER
P1-006_GRIP
P1-010_MAGNET_HOLDER
HW_MAGNET
P1-011A_HALL_FIXED_BRACKET
P1-011B_HALL_SENSOR_SLED
HW_HALL_PCB
HW_EXTENSION_SPRING_ENVELOPE
HW_STOP_PIN
HW_M6_STOP_SCREW_1
HW_M6_STOP_SCREW_2
HW_608_LEFT
HW_608_RIGHT
HW_INNER_RACE_SPACER
HW_AXIAL_SPACER_LEFT
HW_AXIAL_SPACER_RIGHT
HW_M8X90_PIVOT
HW_M8_BOLT_HEAD
HW_M8_NYLOC
HW_PRO_MICRO_ENVELOPE

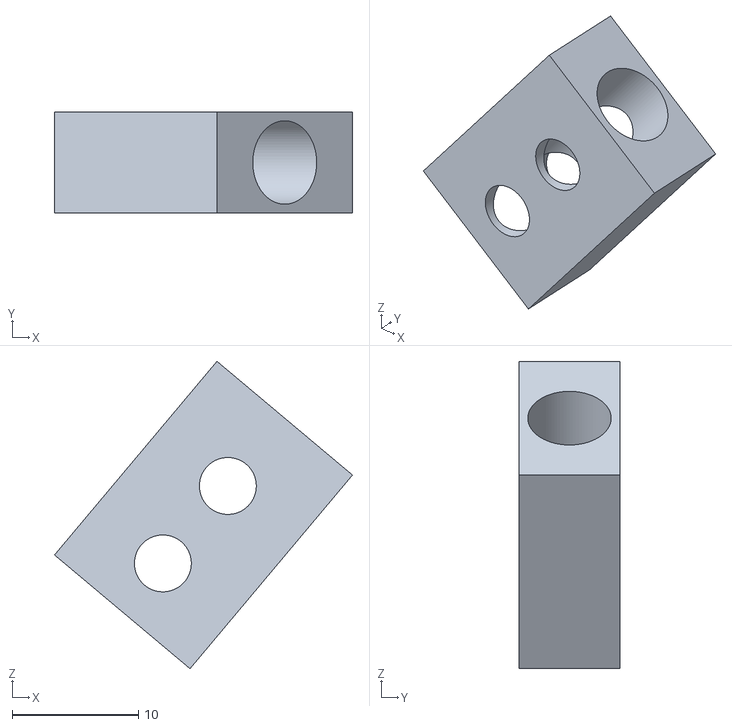
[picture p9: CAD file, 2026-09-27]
prototype_p1/printer_handoff_amine/02_MECHANICAL_CORE_AFTER_CALIBRATION/P1-009_FULL_PULL_STOP.stl
23.6 x 8.00 x 24.3

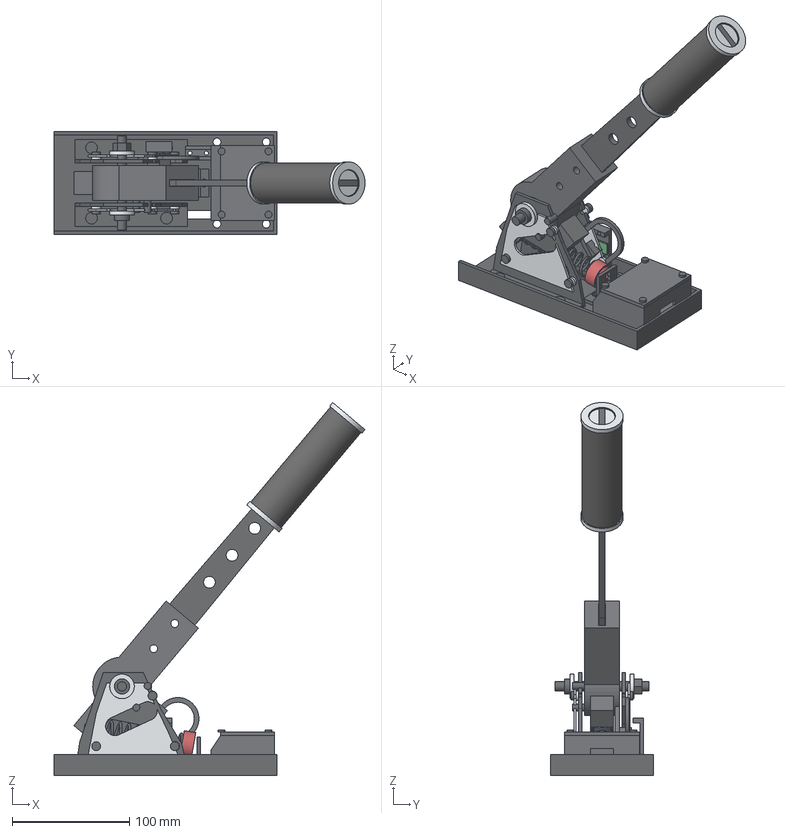
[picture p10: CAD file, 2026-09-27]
prototype_commercial_v1/step/P1C_FULL_PULL.step
265.2 x 88.0 x 318.1 mm
P1C-S001_BASE_TRAY
P1C-S002_LEFT_SIDE_FRAME
P1C-S003_RIGHT_SIDE_FRAME
P1C-S005_SPRING_BRACKET
P1C-A001_LEFT_ACCENT
P1C-A002_RIGHT_ACCENT
P1C-P001_BEARING_HUB
P1C-S004_STEEL_LEVER
HW_GRIP_CORE
HW_RUBBER_GRIP
HW_GRIP_TRIM_RING_1
HW_GRIP_TRIM_RING_2
HW_EXTENSION_SPRING
P1C-P010_SPRING_COLLAR
HW_STOP_PIN
HW_M6_STOP_1
HW_M6_STOP_2
P1C-P002_MAGNET_CARRIER
HW_MAGNET
P1C-P003_HALL_WINDOW
P1C-P004_HALL_SLED
HW_HALL_PCB
P1C-P005_ELECTRONICS_POD
P1C-P006_ELECTRONICS_LID
P1C-P007_CABLE_GUIDE
HW_608_LEFT
HW_608_RIGHT
HW_M8_PIVOT
HW_PIVOT_WASHER_LEFT
HW_PIVOT_WASHER_RIGHT
HW_M8_BOLT_HEAD
HW_M8_NYLOC
HW_LEFT_M4_36
HW_LEFT_HEAD_36
HW_RIGHT_M4_36
HW_RIGHT_HEAD_36
HW_LEFT_M4_84
HW_LEFT_HEAD_84
HW_RIGHT_M4_84
HW_RIGHT_HEAD_84
HW_LEFT_M4_103
HW_LEFT_HEAD_103
HW_RIGHT_M4_103
HW_RIGHT_HEAD_103
HW_M6_FRAME_32_14
HW_M6_FRAME_96_14
HW_M6_FRAME_32_74
HW_M6_FRAME_96_74
HW_M3_LID_143_17
HW_M3_LID_183_17
HW_M3_LID_143_71
HW_M3_LID_183_71

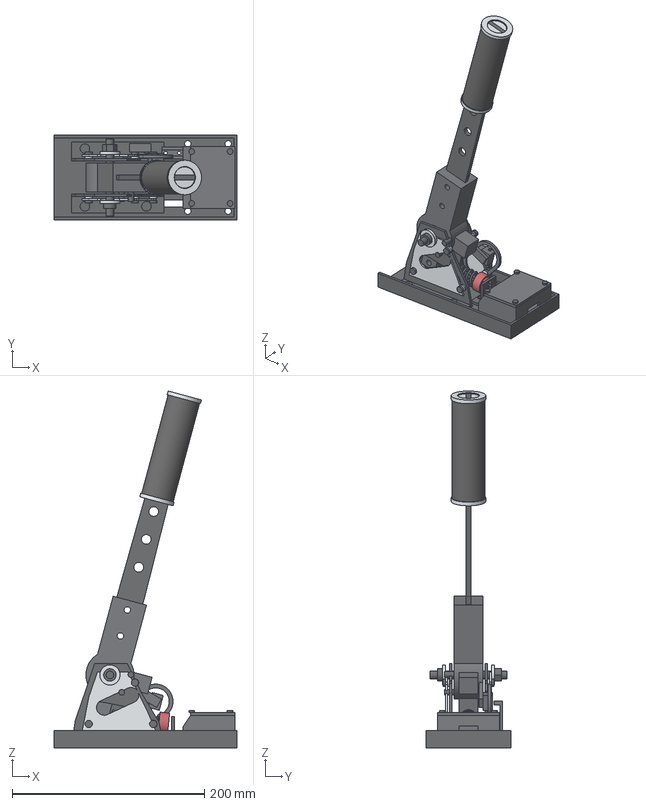
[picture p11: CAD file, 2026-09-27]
prototype_commercial_v1/step/P1C_ASSEMBLY.step
190.0 x 88.0 x 371.4 mm
P1C-S001_BASE_TRAY
P1C-S002_LEFT_SIDE_FRAME
P1C-S003_RIGHT_SIDE_FRAME
P1C-S005_SPRING_BRACKET
P1C-A001_LEFT_ACCENT
P1C-A002_RIGHT_ACCENT
P1C-P001_BEARING_HUB
P1C-S004_STEEL_LEVER
HW_GRIP_CORE
HW_RUBBER_GRIP
HW_GRIP_TRIM_RING_1
HW_GRIP_TRIM_RING_2
HW_EXTENSION_SPRING
P1C-P010_SPRING_COLLAR
HW_STOP_PIN
HW_M6_STOP_1
HW_M6_STOP_2
P1C-P002_MAGNET_CARRIER
HW_MAGNET
P1C-P003_HALL_WINDOW
P1C-P004_HALL_SLED
HW_HALL_PCB
P1C-P005_ELECTRONICS_POD
P1C-P006_ELECTRONICS_LID
P1C-P007_CABLE_GUIDE
HW_608_LEFT
HW_608_RIGHT
HW_M8_PIVOT
HW_PIVOT_WASHER_LEFT
HW_PIVOT_WASHER_RIGHT
HW_M8_BOLT_HEAD
HW_M8_NYLOC
HW_LEFT_M4_36
HW_LEFT_HEAD_36
HW_RIGHT_M4_36
HW_RIGHT_HEAD_36
HW_LEFT_M4_84
HW_LEFT_HEAD_84
HW_RIGHT_M4_84
HW_RIGHT_HEAD_84
HW_LEFT_M4_103
HW_LEFT_HEAD_103
HW_RIGHT_M4_103
HW_RIGHT_HEAD_103
HW_M6_FRAME_32_14
HW_M6_FRAME_96_14
HW_M6_FRAME_32_74
HW_M6_FRAME_96_74
HW_M3_LID_143_17
HW_M3_LID_183_17
HW_M3_LID_143_71
HW_M3_LID_183_71

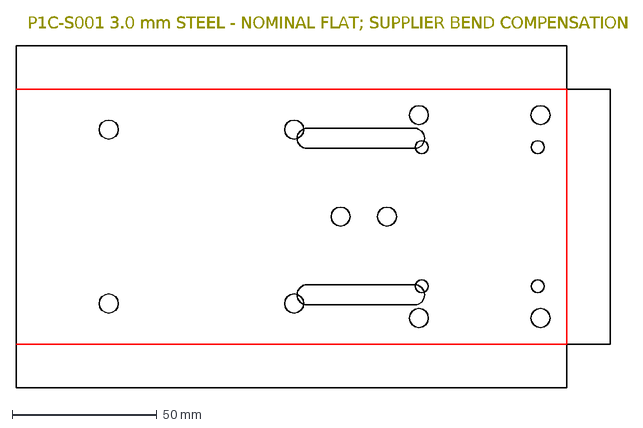
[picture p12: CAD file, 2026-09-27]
prototype_commercial_v1/dxf/P1C-S001_BASE_TRAY_FLAT.dxf
P1C-S001 3.0 mm STEEL - NOMINAL FLAT; SUPPLIER BEND COMPENSATION

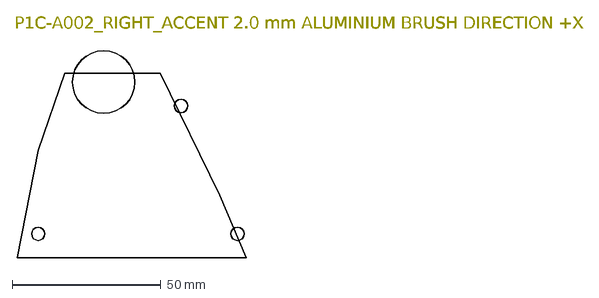
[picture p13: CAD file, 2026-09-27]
prototype_commercial_v1/manufacturing_rfq/ALUMINIUM/P1C-A002_RIGHT_ACCENT.dxf
P1C-A002_RIGHT_ACCENT 2.0 mm ALUMINIUM BRUSH DIRECTION +X

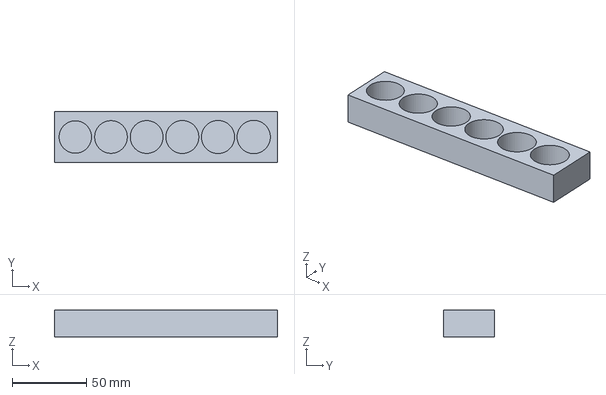
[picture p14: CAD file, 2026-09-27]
prototype_p1/coupons/COUPON_608_POCKETS_DEPTH_14.step
150.0 x 34.0 x 18.0 mm

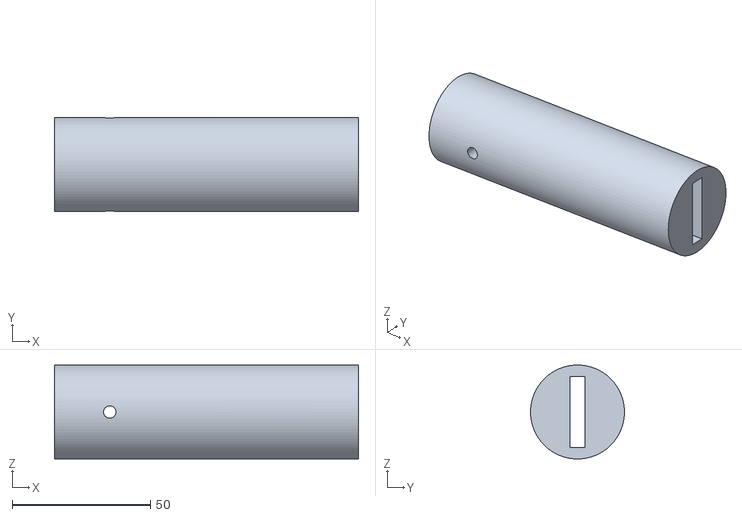
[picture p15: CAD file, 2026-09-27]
prototype_p1/printer_handoff_amine/02_MECHANICAL_CORE_AFTER_CALIBRATION/P1-006_GRIP.stl
110.0 x 34.0 x 34.0

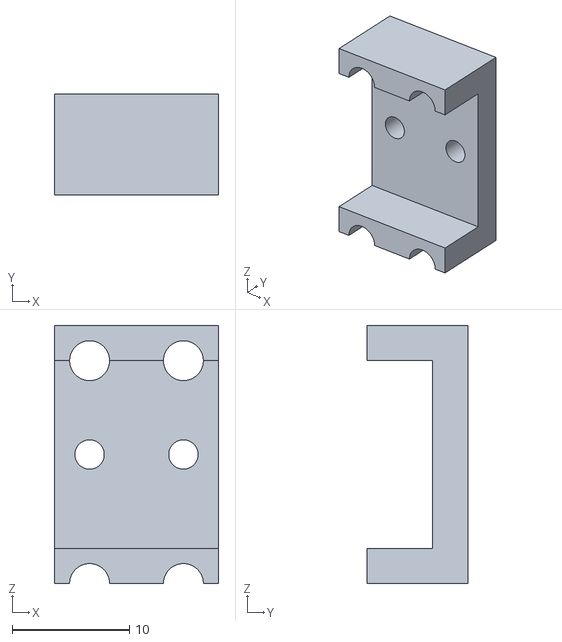
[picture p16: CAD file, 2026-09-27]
prototype_p1/printer_handoff_amine/03_SENSOR_AND_ELECTRONICS/P1-011B_HALL_SENSOR_SLED.stl
14.0 x 8.60 x 22.0

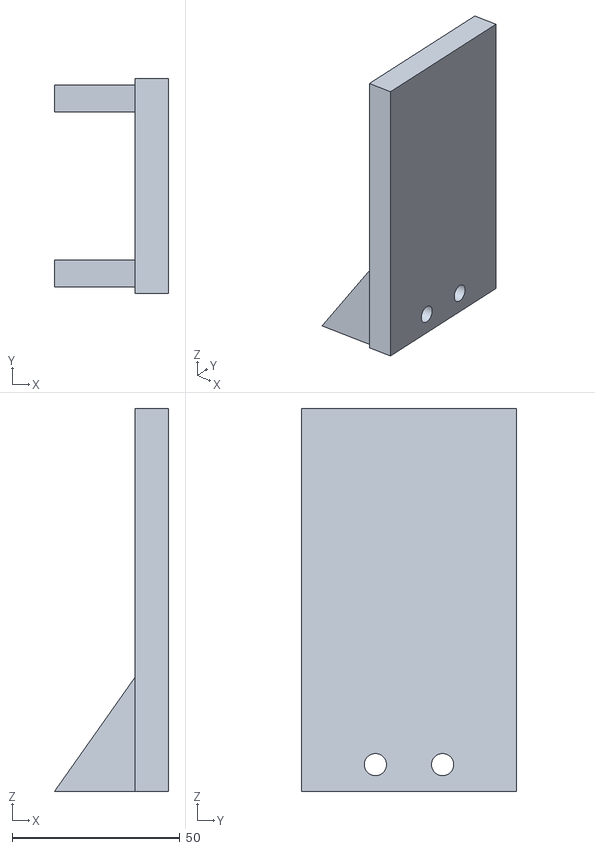
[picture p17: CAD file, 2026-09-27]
prototype_p1/printer_handoff_amine/04_TABLE_CLAMP/P1-021_CLAMP_VERTICAL_BRACKET.stl
34.0 x 64.0 x 114.0

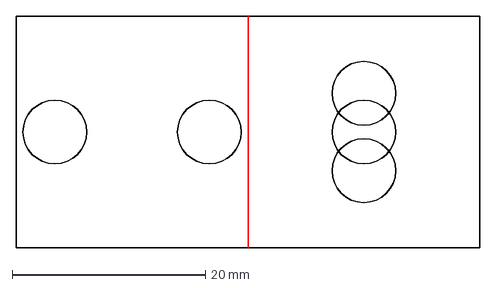
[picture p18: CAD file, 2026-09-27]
prototype_commercial_v1/dxf/P1C-S005_SPRING_BRACKET_FLAT.dxf
48.0 x 24.0 mm

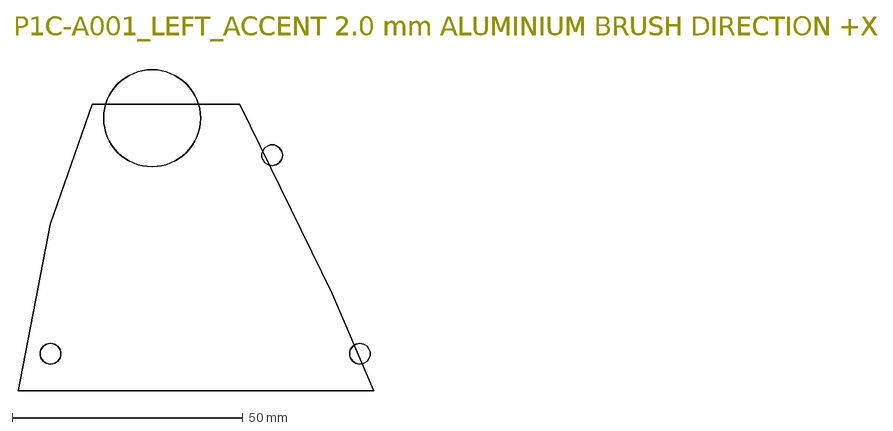
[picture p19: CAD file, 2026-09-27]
prototype_commercial_v1/manufacturing_rfq/ALUMINIUM/P1C-A001_LEFT_ACCENT.dxf
P1C-A001_LEFT_ACCENT 2.0 mm ALUMINIUM BRUSH DIRECTION +X

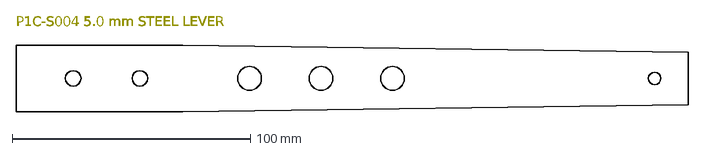
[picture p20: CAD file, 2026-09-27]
prototype_commercial_v1/manufacturing_rfq/STEEL/P1C-S004_STEEL_LEVER.dxf
P1C-S004 5.0 mm STEEL LEVER

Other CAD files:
prototype_p1/step/P1-009_FULL_PULL_STOP.step
prototype_commercial_v1/step/P1C_RELEASED.step
prototype_commercial_v1/step/P1C-P002_MAGNET_CARRIER.step
prototype_commercial_v1/dxf/P1C-S002_LEFT_SIDE_FRAME_FLAT.dxf
prototype_commercial_v1/dxf/P1C-S003_RIGHT_SIDE_FRAME_FLAT.dxf
prototype_commercial_v1/dxf/P1C-S006_CLAMP_BRACKET_FLAT.dxf
prototype_commercial_v1/manufacturing_rfq/STEEL/P1C-S002_LEFT_SIDE_FRAME_FLAT.dxf
prototype_commercial_v1/manufacturing_rfq/STEEL/P1C-S003_RIGHT_SIDE_FRAME_FLAT.dxf
prototype_commercial_v1/manufacturing_rfq/STEEL/P1C-S006_CLAMP_BRACKET_FLAT.dxf
prototype_commercial_v1/step/P1C-A001_LEFT_ACCENT.step
prototype_commercial_v1/step/P1C-A002_RIGHT_ACCENT.step
prototype_commercial_v1/step/P1C-P001_BEARING_HUB.step
prototype_commercial_v1/step/P1C-P003_HALL_WINDOW.step
prototype_commercial_v1/step/P1C-P004_HALL_SLED.step
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

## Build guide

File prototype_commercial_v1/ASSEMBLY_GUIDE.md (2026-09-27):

# Assembly guide

Tools: 2.5/3/4/5/6 mm hex keys as selected, spanners for M6/M8/M10, bearing press/arbor or controlled vise, threadlocker where specified, caliper.

1. Bolt the two formed steel side frames to the base tray; leave loose for alignment.
2. Press the two 608 bearings into the carrier after coupon confirmation. Fit inner spacer.
3. Insert steel lever in carrier and secure with two M6 through bolts and nylocs.
4. Place axial spacers, insert the M8 smooth shank through both frames and bearings, then tighten without side-loading the inner races.
5. Square frames, fit anti-spread/base bolts, then torque frame fasteners.
6. Install M6 moving/fixed spring anchors, selected spring and red collar.
7. Install release/full M6 stops and adjust to 75°/50° before any sensor work.
8. Install magnet carrier and keeper screw. Install plastic magnetic window and Hall sled at a conservative gap.
9. Route the three-wire Hall cable through the guide into the rear pod. Fit controller and removable lid.
10. Fit accents with consistent black M4 button-head hardware.
11. For desk mode bolt on the steel C bracket, coupling nut, M10 screw, swivel pad and knob. For rig mode leave clamp off and use M6 slots.

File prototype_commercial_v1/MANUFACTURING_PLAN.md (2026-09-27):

# Manufacturing plan

1. Laser cut steel and aluminium from supplied DXFs. All DXFs are millimetres.
2. Deburr all edges; break customer-touching edges 0.3–0.5 mm.
3. Supplier applies bend deduction/K-factor to actual tooling before production. Nominal inside radius 3 mm and 90° bends are starting assumptions.
4. Trial-form one base, one left/right frame pair, spring bracket, and clamp. Verify M8 coaxial alignment using a fixture bolt before coating.
5. Powder coat steel satin/matte black. Mask bearing/pivot-critical interfaces and threads.
6. Directionally brush aluminium along +X and apply clear protection or quote silver powder coat.
7. Print internal parts after bearing/magnet/fastener coupons establish fit.
8. Assemble and run the TEST_PLAN before cosmetic approval.

RFQ quantities: 1, 5, 10, 25 and 50 complete sets. Quote material, cutting, bending, deburring, coating, lead time, tooling/NRE, and scrap separately.

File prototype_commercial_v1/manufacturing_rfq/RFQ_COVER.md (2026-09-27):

# P1-C supplier RFQ

Quote 1, 5, 10, 25 and 50 complete sets. State material grade, sheet thickness tolerance, laser tolerance, bend tooling/radius, deburring, finish, NRE/tooling, lead time, VAT/tax basis and delivery separately. Do not manufacture production quantity until one formed sample is approved.

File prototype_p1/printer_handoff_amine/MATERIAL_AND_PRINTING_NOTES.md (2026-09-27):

# Material and printing notes

## Current filament estimate — engineering estimate only

No real printer/slicer profile was available when these figures were calculated. They use STL geometry, PETG density, six perimeter walls, six top/bottom layers, and a 50% planning infill. They exclude slicer-specific line overlap, flow, support, brim, purge, and failed prints.

| Print scope | Pieces | Current 50% estimate |
|---|---:|---:|
| Calibration batch | 8 | approximately 233 g |
| Mechanical core | 8 | approximately 435 g |
| Complete final prototype | 19 | approximately 685 g |
| All final parts plus coupons | 27 | approximately 918 g |
| All 27 plus 30% development/reprint reserve | 27 | approximately 1.19 kg |

The conservative stock recommendation is **2 kg of the same filament**. Please replace these planning figures with the actual slicer result from the real printer/profile.

## Why PETG was selected as the P1 baseline

P1 contains mechanically loaded pivot towers, bearing pockets, a spring anchor, clamp structures, and bolted joints. PETG was chosen as a common starting material because it usually provides a useful compromise between toughness, impact resistance, layer adhesion, availability, cost, and hobby-printer accessibility. It is generally less brittle in mechanical handling than ordinary PLA.

PETG is not automatically “the best,” and the design does not assume that choosing PETG guarantees durability. PETG can be more flexible than PLA, may string, is sensitive to profile and cooling choices, and can creep under sustained load. Dimensional fit and mechanical endurance still require coupon and physical testing.

## If a different material is available

| Material | Calibration coupons | Fit/form testing | Mechanically loaded P1 | Main concern for this prototype |
|---|---|---|---|---|
| PLA | Suitable | Suitable | Usable only as a clearly limited early structural trial | More brittle failure behavior; heat and sustained-load creep can invalidate long tests |
| PETG | Suitable | Suitable | Reasonable P1 baseline, pending testing | Flexibility, stringing, dimensional tuning, and sustained-load creep |
| ABS | Suitable after printer calibration | Suitable | Potentially reasonable | Shrinkage/warping can change bearing and bolt fits; enclosure, ventilation, and layer adhesion matter |
| ASA | Suitable after printer calibration | Suitable | Potentially reasonable | Similar shrink/warp and ventilation concerns to ABS; UV resistance is not important for this indoor P1 |
| Nylon / PA | Suitable only after drying and profile tuning | Suitable after tuning | Potentially very tough | Moisture sensitivity, dimensional variation, flexibility/creep, and harder printing; filled grades may require a hardened nozzle |
| Engineering or fibre-filled filament | Material-dependent | Material-dependent | May improve stiffness or heat behavior | Abrasive grades need suitable hardware; layer strength and manufacturer profile still control the result |

PLA is acceptable for the first calibration and fit work if that is what is available. If PLA is used for structural testing, report it clearly because the results will not directly validate the PETG baseline. A well-understood engineering filament may be better than PETG; please tell us exactly what material and grade is available rather than substituting silently.

## Build-volume check

The manifest lists the oriented envelope for every file. The largest print is the base, `P1-001_BASE.stl`, at approximately **180 x 84 x 10 mm** in the recommended orientation. It needs extra usable bed margin for skirt/brim and exclusion zones, so a nominal 180 mm bed axis may be too small.

Other large envelopes to check are:

- `COUPON_608_POCKETS_DEPTH_7.stl`: approximately 150 x 34 x 11 mm.
- `COUPON_608_POCKETS_DEPTH_14.stl`: approximately 150 x 34 x 18 mm.
- `P1-004_LEVER_ROOT_BEARING_HUB.stl`: approximately 124 x 64 x 28 mm when placed on a bearing face.
- `P1-021_CLAMP_VERTICAL_BRACKET.stl`: approximately 64 x 114 x 34 mm when placed on its large X face.
- `P1-006_GRIP.stl`: approximately 34 x 34 x 110 mm when printed upright.

A typical 220 x 220 x 250 mm printer should have sufficient nominal volume for each individual STL, but usable-area restrictions and slicer margins must be checked. Do not arrange all parts on one plate merely because they fit; the first actual print job is the eight calibration files only.

## Orientation and support review

`PRINT_FILE_MANIFEST.csv` records the existing P1 orientation guidance for every STL. Most parts were designed to minimize support. Please use slicer preview to verify bridges, overhangs, unsupported internal features, and layer direction before printing.

Pay particular attention to:

- `P1-004_LEVER_ROOT_BEARING_HUB.stl`: lever-slot bridge; use local support only if the printer cannot bridge it cleanly.
- `P1-010_MAGNET_HOLDER.stl`: magnet-cup area may need small local support.
- `P1-011A_HALL_FIXED_BRACKET.stl` and `P1-011B_HALL_SENSOR_SLED.stl`: inspect rail/bridge regions.
- `P1-006_GRIP.stl`: print upright as guided; a brim may be appropriate for stability.

Please report any orientation that looks mechanically weak, requires excessive support, or creates excessive print time. Support and brim material were not included in the engineering mass estimate.

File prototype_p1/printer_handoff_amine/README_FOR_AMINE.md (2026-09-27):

# P1 sim-racing handbrake — print check for Amine

This is the first mechanical prototype of a sim-racing handbrake.

## Please do not print everything yet

There are **27 STL files** in four folders:

- `01_CALIBRATION_FIRST/`: 8 calibration pieces — this is the only batch to print first.
- `02_MECHANICAL_CORE_AFTER_CALIBRATION/`: 8 structural parts — inspect now, but wait before printing.
- `03_SENSOR_AND_ELECTRONICS/`: 5 parts — inspect now, but wait before printing.
- `04_TABLE_CLAMP/`: 6 parts — inspect now, but wait before printing.

Please load all 27 STLs into your normal slicer to check fit, orientation, support, and total filament. The current mass numbers are engineering estimates only; your slicer result with your real printer and filament profile is the number we need.

## Current design baseline

- Material: PETG
- Nozzle: 0.4 mm
- Layer height: 0.20 mm
- Walls/perimeters: 5–6
- Top layers: 6
- Bottom layers: 6
- Planning infill: 50%

These are starting settings, not mandatory. Please tell us if your printer/profile needs something different.

## Please report back

```text
PRINTER MODEL:
SLICER + VERSION:
NOZZLE:
MATERIAL:
FILAMENT BRAND:
FILAMENT TYPE/GRADE:
AVAILABLE FILAMENT MASS:
BUILD VOLUME (X x Y x Z):

SLICER MASS — 8 CALIBRATION PARTS:
SLICER MASS — 8 MECHANICAL-CORE PARTS:
SLICER MASS — 19 FINAL PARTS:
SLICER MASS — ALL 27 FILES:

PARTS THAT DO NOT FIT:
PARTS NEEDING SUPPORT:
PARTS NEEDING A BRIM:
ORIENTATION CHANGES YOU RECOMMEND:
SETTING CHANGES YOU RECOMMEND:
OTHER SLICER/PREVIEW CONCERNS:
```

Please inspect the bridge/support risk on `P1-004`, `P1-010`, `P1-011A`, and `P1-011B`. The upright grip `P1-006` may need a brim.

After the eight coupons are printed and measured, some fit-dependent dimensions may change and regenerated structural STLs may be sent. That is why the other 19 parts should not be printed yet.

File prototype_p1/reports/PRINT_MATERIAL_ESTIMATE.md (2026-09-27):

# P1.0 Print Material Estimate

## Executive result

The released P1.0 deliverables contain **27 unique STL files at quantity one**: **8 calibration coupons** and **19 final structural/accessory components**. The 19 final components divide into **8 mechanical-core parts**, **5 sensor/electronics parts**, and **6 desk-clamp parts**. No CAD or STL file was modified for this report.

All 27 meshes load as watertight, consistently oriented, single-component solids. Pre-existing P1.0 manifest hash match: **27/27**.

## Method and limitations

- **Exact solid CAD/STL volume:** calculated directly from each released binary STL triangle mesh with trimesh after normal mesh processing. This is the closed tessellated-solid volume, not deposited filament volume.
- **Practical FDM estimate:** no PrusaSlicer, OrcaSlicer, CuraEngine, or Bambu Studio command-line executable was found in PATH or common installation locations, and no printer/profile was supplied. The values below are therefore an **engineering estimate, not slicer output**.
- Baseline: PETG density 1.27 g/cm3, 0.40 mm nozzle, 0.20 mm layers, 6 perimeters, 6 top layers, 6 bottom layers, and an explicit 0.45 mm assumed extrusion width.
- Shell model: directional STL surface area x 2.70 mm perimeter envelope plus projected top/bottom area x 1.20 mm skin envelope. It does not subtract edge overlap and is capped at exact solid volume, so it is intentionally conservative for purchasing. The remaining internal volume receives 40%, 50%, or 60% infill.
- Estimated mass excludes support, brim, skirt, purge/prime lines, extrusion multiplier differences, gap fill, slicer line overlap, failed prints, and moisture-conditioning losses. Support statements are orientation guidance only and were not calculated by a slicer.
- **Print time: UNKNOWN** because neither a slicer result nor a printer/machine profile is available.

Bounding dimensions are native STL X x Y x Z extents in millimetres; the recommended build orientation may rotate them on the printer.

## Piece-count verification

| Category | Unique STLs | Physical pieces |
|---|---:|---:|
| A. Calibration coupons | 8 | 8 |
| B. Mechanical core | 8 | 8 |
| C. Sensor/electronics printed parts | 5 | 5 |
| D. Desk-clamp printed parts | 6 | 6 |
| **Final components (B+C+D)** | **19** | **19** |
| **Complete set (A+B+C+D)** | **27** | **27** |

## A. Calibration coupons

| Part ID | STL filename | Qty | Bounding X x Y x Z (mm) | Exact volume (cm3) | 100% solid mass (g) | Est. 40% (g) | Est. 50% (g) | Est. 60% (g) | Recommended orientation | Likely support requirement |
|---|---|---:|---:|---:|---:|---:|---:|---:|---|---|
| CAL-608-07 | `COUPON_608_POCKETS_DEPTH_7.stl` | 1 | 150.0 x 34.0 x 11.0 | 39.95 | 50.7 | 44.0 | 45.1 | 46.2 | Flat base on bed; 7 mm pockets upward | No support expected; not slicer-verified |
| CAL-608-14 | `COUPON_608_POCKETS_DEPTH_14.stl` | 1 | 150.0 x 34.0 x 18.0 | 59.51 | 75.6 | 65.2 | 66.9 | 68.7 | Flat base on bed; 14 mm pockets upward | No support expected; not slicer-verified |
| CAL-M8 | `COUPON_M8_CLEARANCE.stl` | 1 | 72.0 x 24.0 x 8.0 | 12.09 | 15.4 | 13.8 | 14.0 | 14.3 | Flat base on bed; test bores vertical | No support expected; not slicer-verified |
| CAL-M6 | `COUPON_M6_CLEARANCE.stl` | 1 | 72.0 x 24.0 x 8.0 | 12.83 | 16.3 | 13.9 | 14.3 | 14.7 | Flat base on bed; test bores vertical | No support expected; not slicer-verified |
| CAL-M6-NUT | `COUPON_M6_NUT_TRAPS.stl` | 1 | 80.0 x 26.0 x 8.0 | 14.80 | 18.8 | 16.3 | 16.7 | 17.1 | Largest flat face on bed; nut traps upward | No support expected; not slicer-verified |
| CAL-MAG | `COUPON_MAGNET_POCKETS.stl` | 1 | 70.0 x 22.0 x 7.0 | 10.15 | 12.9 | 11.4 | 11.6 | 11.9 | Largest flat face on bed; pockets upward | No support expected; not slicer-verified |
| CAL-HALL | `COUPON_HALL_GAP_JIG.stl` | 1 | 104.0 x 35.0 x 18.0 | 19.40 | 24.6 | 24.6 | 24.6 | 24.6 | Largest flat face on bed | No support expected; not slicer-verified |
| CAL-BEAR-WALL | `COUPON_LOADED_BEARING_WALL.stl` | 1 | 79.0 x 20.0 x 48.0 | 42.05 | 53.4 | 36.9 | 39.6 | 42.4 | Broad side face on bed; bearing axis horizontal | No support expected; not slicer-verified |

## B. Mechanical core

| Part ID | STL filename | Qty | Bounding X x Y x Z (mm) | Exact volume (cm3) | 100% solid mass (g) | Est. 40% (g) | Est. 50% (g) | Est. 60% (g) | Recommended orientation | Likely support requirement |
|---|---|---:|---:|---:|---:|---:|---:|---:|---|---|
| P1-001 | `P1-001_BASE.stl` | 1 | 180.0 x 84.0 x 10.0 | 114.03 | 144.8 | 107.0 | 113.3 | 119.6 | Primary flat face on bed; steel recesses upward | No support expected; not slicer-verified |
| P1-002 | `P1-002_LEFT_PIVOT_SUPPORT.stl` | 1 | 56.0 x 18.0 x 93.0 | 65.56 | 83.3 | 56.3 | 60.8 | 65.3 | Outer Y face on bed | No support expected; ream holes after printing |
| P1-003 | `P1-003_RIGHT_PIVOT_SUPPORT.stl` | 1 | 56.0 x 18.0 x 93.0 | 68.85 | 87.4 | 55.6 | 60.9 | 66.2 | Outer Y face on bed | No support expected; not slicer-verified |
| P1-004 | `P1-004_LEVER_ROOT_BEARING_HUB.stl` | 1 | 124.0 x 28.0 x 64.0 | 103.15 | 131.0 | 89.6 | 96.5 | 103.4 | One bearing face on bed | Conditional local support in accessible lever slot if bridging is poor |
| P1-006 | `P1-006_GRIP.stl` | 1 | 110.0 x 34.0 x 34.0 | 83.56 | 106.1 | 82.8 | 86.7 | 90.5 | Upright on end with brim | No support expected; brim material is excluded |
| P1-007 | `P1-007_SPRING_ANCHOR_MODULE.stl` | 1 | 40.0 x 24.0 x 22.0 | 10.48 | 13.3 | 13.3 | 13.3 | 13.3 | Foot on bed | No support expected; not slicer-verified |
| P1-008 | `P1-008_RELEASE_STOP.stl` | 1 | 18.7 x 8.0 x 22.9 | 1.50 | 1.9 | 1.9 | 1.9 | 1.9 | Outer Y face on bed | No support expected; not slicer-verified |
| P1-009 | `P1-009_FULL_PULL_STOP.stl` | 1 | 23.6 x 8.0 x 24.3 | 1.50 | 1.9 | 1.9 | 1.9 | 1.9 | Outer Y face on bed | No support expected; not slicer-verified |

## C. Sensor/electronics printed parts

| Part ID | STL filename | Qty | Bounding X x Y x Z (mm) | Exact volume (cm3) | 100% solid mass (g) | Est. 40% (g) | Est. 50% (g) | Est. 60% (g) | Recommended orientation | Likely support requirement |
|---|---|---:|---:|---:|---:|---:|---:|---:|---|---|
| P1-010 | `P1-010_MAGNET_HOLDER.stl` | 1 | 22.4 x 12.0 x 43.0 | 2.88 | 3.7 | 3.7 | 3.7 | 3.7 | Inner arm face on bed | Conditional small local support at magnet cup |
| P1-011A | `P1-011A_HALL_FIXED_BRACKET.stl` | 1 | 31.0 x 15.0 x 35.0 | 3.54 | 4.5 | 4.5 | 4.5 | 4.5 | Largest flat face on bed | Conditional; inspect rail bridges in slicer |
| P1-011B | `P1-011B_HALL_SENSOR_SLED.stl` | 1 | 14.0 x 8.6 x 22.0 | 1.18 | 1.5 | 1.5 | 1.5 | 1.5 | Largest flat face on bed | Conditional; inspect rail bridges in slicer |
| P1-012 | `P1-012_ELECTRONICS_ENCLOSURE.stl` | 1 | 50.0 x 38.0 x 28.0 | 14.21 | 18.0 | 18.0 | 18.0 | 18.0 | Enclosure bottom on bed | No support expected; not slicer-verified |
| P1-013 | `P1-013_ELECTRONICS_COVER.stl` | 1 | 50.0 x 38.0 x 5.0 | 8.36 | 10.6 | 9.7 | 9.8 | 10.0 | Outer top face on bed | No support expected; not slicer-verified |

## D. Desk-clamp printed parts

| Part ID | STL filename | Qty | Bounding X x Y x Z (mm) | Exact volume (cm3) | 100% solid mass (g) | Est. 40% (g) | Est. 50% (g) | Est. 60% (g) | Recommended orientation | Likely support requirement |
|---|---|---:|---:|---:|---:|---:|---:|---:|---|---|
| P1-020 | `P1-020_CLAMP_BASE_INTERFACE.stl` | 1 | 64.0 x 72.0 x 8.0 | 35.23 | 44.7 | 32.3 | 34.4 | 36.4 | Large face on bed | No support expected; not slicer-verified |
| P1-021 | `P1-021_CLAMP_VERTICAL_BRACKET.stl` | 1 | 34.0 x 64.0 x 114.0 | 78.80 | 100.1 | 66.4 | 72.0 | 77.6 | Large X face on bed; ribs upward | No support expected; not slicer-verified |
| P1-022 | `P1-022_CLAMP_SCREW_GUIDE.stl` | 1 | 76.0 x 32.0 x 38.0 | 44.68 | 56.7 | 43.0 | 45.3 | 47.6 | Lower arm face on bed; hex pocket vertical | No support expected; not slicer-verified |
| P1-023 | `P1-023_CLAMP_KNOB.stl` | 1 | 52.0 x 47.2 x 18.0 | 27.18 | 34.5 | 25.6 | 27.1 | 28.6 | Flat face on bed | No support expected; not slicer-verified |
| P1-024 | `P1-024_SWIVEL_PAD_HOLDER.stl` | 1 | 46.0 x 46.0 x 8.0 | 11.59 | 14.7 | 12.0 | 12.4 | 12.9 | Flat face on bed | No support expected; not slicer-verified |
| P1-025 | `P1-025_UPPER_RUBBER_PAD_HOLDER.stl` | 1 | 90.0 x 62.0 x 3.0 | 16.50 | 21.0 | 20.9 | 20.9 | 20.9 | Large face on bed | No support expected; not slicer-verified |

## Category and build-stage totals

| Scope | Pieces | Exact solid volume (cm3) | 100% solid mass (g) | Est. 40% (g) | Est. 50% (g) | Est. 60% (g) |
|---|---:|---:|---:|---:|---:|---:|
| Calibration coupons | 8 | 210.78 | 267.7 | 226.0 | 233.0 | 239.9 |
| Mechanical core | 8 | 448.63 | 569.8 | 408.4 | 435.3 | 462.2 |
| Sensor/electronics printed parts | 5 | 30.17 | 38.3 | 37.4 | 37.5 | 37.7 |
| Desk-clamp printed parts | 6 | 213.98 | 271.8 | 200.1 | 212.0 | 224.0 |
| All final P1 printed components (B+C+D) | 19 | 692.78 | 879.8 | 645.8 | 684.8 | 723.8 |
| Complete print set including coupons (A+B+C+D) | 27 | 903.56 | 1147.5 | 871.8 | 917.8 | 963.7 |

## Filament reserve

Reserve calculations use the same estimated deposited mass. A `+15%` allowance is reasonable for normal handling, short test extrusions, and small slicer differences; `+30%` is the development/reprint allowance requested for P1.

### All 19 final components

| Infill | Theoretical printed mass (g) | +15% reserve (g) | +30% development reserve (g) | Safe 1 kg spools |
|---:|---:|---:|---:|---:|
| 40% | 645.8 | 742.7 | 839.6 | 1 |
| 50% | 684.8 | 787.6 | 890.3 | 1 |
| 60% | 723.8 | 832.4 | 941.0 | 1 |

### Complete set: final components plus 8 coupons

| Infill | Theoretical printed mass (g) | +15% reserve (g) | +30% development reserve (g) | Safe 1 kg spools |
|---:|---:|---:|---:|---:|
| 40% | 871.8 | 1002.6 | 1133.4 | 2 |
| 50% | 917.8 | 1055.5 | 1193.1 | 2 |
| 60% | 963.7 | 1108.3 | 1252.9 | 2 |

For sending the job to a friend, **50% infill is the central planning case**. At that case, the complete 27-piece set plus 30% development reserve requires 1193.1 g, so have **2 x 1 kg spool(s)** of the same PETG lot available. This is a stock recommendation, not a claim that all of it will be consumed.

## Practical print sequence

1. **Initially:** print the 8 calibration coupons, approximately **233 g** at the 50% planning case.
2. **After calibration:** print the 8 mechanical-core parts, approximately **435 g** at 50%.
3. Print the 5 sensor/electronics parts and 6 clamp parts after fit and motion checks. The complete final 19-part prototype is approximately **685 g** at 50%.
4. Before each batch, rotate parts to the stated orientation and inspect unsupported bridges, hole orientation, brim need, and generated support in the actual slicer. Use the slicer's own mass result as the final purchasing/production number.

## Simple summary to send to the printer owner

> Initially: 8 calibration pieces / approximately 233 g PETG at 50% infill.  
> After calibration: 8 mechanical-core pieces / approximately 435 g PETG at 50% infill.  
> Complete prototype: 19 final printed pieces / approximately 685 g PETG at 50% infill.  
> Recommended filament to have available: 2 kg PETG (covers all 27 prints and a 30% development/reprint reserve).

## Machine-readable data

`print_material_estimate.csv` contains one row per STL followed by category/final/complete summary rows. It includes SHA-256 evidence, mesh integrity, exact volume, 100%-solid equivalent mass, directional shell estimate, 40/50/60% estimates, orientation, and support guidance.

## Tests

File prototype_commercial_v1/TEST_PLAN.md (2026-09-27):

# Test plan

## Alpha gates

1. Dimensional: M8 shaft, 608 pockets, formed frame gap, frame coaxiality, lever thickness, accent fit, pod fit.
2. Motion: cycle released/mid/full by hand without spring; verify both stops carry contact and Hall parts never touch.
3. Spring: test candidate springs for return, coil bind, side rub, and anchor bending.
4. Static pull: fixture in rig mode and test 25, 50, 75, 100 N at grip; inspect after each stage. 150 N is a proof-case only after lower stages pass.
5. Clamp: 10/25/40/55 mm desks with rubber pads; measure slip, bracket deflection and desk marking at each pull stage.
6. Cyclic: minimum development sequence 10k cycles before any durability claim; inspect carrier, bearings, stop holes, side-frame feet and coating.
7. Hall: record voltage at 0/25/50/75/100% for gaps 3/5/8/10/12/15 mm and both magnet polarities. Confirm monotonic response with steel panels and final cable routing installed.
8. Electronics: USB strain relief, cable sweep, ESD handling, service removal without pivot disassembly.
9. Environmental: warm parked-room soak and sustained clamp load to observe printed-part creep.

Acceptance values must be set after first physical alpha. CAD alone does not establish production safety.

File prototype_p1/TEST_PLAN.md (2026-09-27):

# P1.0 physical validation plan

Do not jump directly to a maximum-load or endurance test. Photograph and record every stage, including slicer settings and measured hardware.

## Test 0 — calibration coupons

Print all eight coupon STLs in the same PETG, orientation, nozzle, layer height, cooling, and dimensional compensation intended for P1. Record:

- 608 pocket selection at both 7 and 14 mm depths: 21.8/22.0/22.1/22.2/22.3/22.4 mm.
- M8 clearance: 8.0/8.2/8.4/8.6 mm.
- M6 clearance: 6.0/6.2/6.4/6.6 mm.
- M6 nut trap: 10.0/10.2/10.4/10.6 mm AF.
- Magnet pocket: nominal/+0.1/+0.2/+0.3 mm.
- Hall gap jig: verify 3/5/8/10/12/15 mm with calipers.
- Loaded bearing-wall coupon: confirm bearing insertion/removal, then load its M6 lug progressively.

Return the selected sizes, actual printed dimensions, insertion force/feel, and any cracking or whitening.

## Test 1 — bearing/hub fit

Print P1-004 only after updating coupon-dependent values. Install/remove both bearings twice. They must seat squarely without splitting, rock, or free-fall. Confirm the inner spacer length lets both bearings seat fully.

## Test 2 — pivot free rotation

Print both supports and base. Assemble hub, bearings, spacer, washers, and M8 bolt without lever or spring. Tighten the nyloc gradually. The hub must rotate freely with no tower bowing, axial rattle, or bearing bind.

## Test 3 — core mechanism without spring

Add steel lever, grip, M6 hub bolts, stop pin, and stop blocks. Sweep 75° to 50° at least 50 times. Confirm the only endpoint contacts are the rubber-tipped mechanical stops.

## Test 4 — light spring

Install the lightest viable extension spring. Measure hook distance at release/full and spring force if possible. Confirm reliable return without coil bind, hook opening, anchor bending, or spring contact with printed parts.

## Test 5 — travel stops

Mark both M6 adjusters. Pull firmly into each stop 25 times. Check adjuster rotation, block movement, left-tower whitening, stop-pin bending, and final angle drift. Use locknuts after adjustment.

## Test 6 — progressive static hand load

Use a luggage scale at grip centre. Apply 25, 50, 75, then 100 N, holding each for five seconds. After each step inspect: cracks, whitening, permanent tower spread, bearing-seat movement, lever slip, bolt loosening, base lift, backing-strip movement, spring-anchor damage, and stop damage. The derived torques are 6.13, 12.25, 18.38, and 24.5 N.m for 25/50/75/100 N at 245 mm. Do not attempt 150 N until 100 N passes and the user deliberately accepts a proof test.

## Test 7 — repetition

Cycle 100 pulls, inspect; then 500 total, inspect; then 1000 total, inspect. Record angle, looseness, noise, return consistency, bearing movement, and any PETG creep. This is prototype learning, not a life certification.

## Test 8 — rig mounting

Remove the clamp. Use two M6 bolts and >=18 mm OD washers in the 44 x 7 mm slots. Repeat 50/75/100 N tests. Check slot elongation, base bending, and movement on the rig.

## Test 9 — table clamp range

Assemble with the real steel coupling nut and screw. Test sacrificial boards at 10, 25, 40, and 55 mm. Confirm pad articulation, full thread engagement, knob clearance, accessible tightening, and no desk marking.

## Test 10 — clamp slip/lift

At each desk thickness, apply 25/50/75/100 N progressively. Mark base position to detect slip and use a straightedge/feeler to observe edge lift. Stop for clamp-bracket whitening, coupling-nut movement, screw-guide separation, base lift, rubber extrusion, or desk damage. Do not infer friction capacity from CAD.

## Test 11 — magnet/Hall integration

With mechanical stops proven, install the magnet and SS49E board. Start at 5 mm face gap. Record released, 25%, 50%, 75%, and 100% voltages for both magnet polarities/orientations and gaps 3/5/8/10/12/15 mm. Select a monotonic range that stays clear of supply rails and is repeatable after 100 cycles.

## Test 12 — USB HID later

Connect Hall VCC/GND/signal to a Pro Micro ADC. Implement filtering, calibration, dead zones, and 0–1023 USB HID Slider mapping. Optionally assert a virtual firmware button at about 60% travel. Firmware is intentionally outside this mechanical pass.

## Data to return for P1.1

Coupon selections and measured offsets; actual bearing dimensions; M8 shank length; steel-bar width/thickness; spring dimensions/rate/forces; released/full hand force; stop-angle measurements; clamp nut AF/length; swivel-foot geometry; board/connector envelopes; Hall voltages at all five travel points and each tested gap; photographs of every stressed area after 100/500/1000 pulls.

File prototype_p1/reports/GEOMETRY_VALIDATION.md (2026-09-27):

# P1.0 geometry validation
Generated from B-Rep solids; intersection tolerance is 0.01 mm³.
|Check|Status|Evidence|
|---|---|---|
|All exported solids valid|PASS|30/30 valid|
|All exported parts non-zero volume|PASS|Every part/coupon reports positive volume|
|Motion-state interference|PASS|No unintended moving/fixed overlap in 75/62.5/50 degree states|
|608 axial alignment|PASS|Both 22x7 bearings share M8 axis X=50, Z=76; bearings seat y=28.2..35.2 and 48.8..55.8|
|M8 journal location|PASS|M8x90 placeholder spans y=-4..86; smooth-shank length must be measured before print|
|Spring length monotonic|PASS|{"released": 69.76, "mid": 77.97, "full": 85.82}|
|Hall distance monotonic toward full pull|PASS|{"released": 23.99, "mid": 12.63, "full": 5.02}|
|Mechanical stop endpoint contact|PASS|Tangent M6 pin/screw model overlap volumes: {'released': 0.0, 'full': 0.0}|
|Clamp states 10/25/40/55 mm|PASS|{"10": {"pad_top_z": -21.0, "desk_underside_z": -21.0, "full_nut_engagement": true, "knob_clear": true, "pad_desk_overlap_mm3": 0.0, "pass": true}, "25": {"pad_top_z": -36.0, "desk_underside_z": -36.0, "full_nut_engagement": true, "knob_clear": true, "pad_desk_overlap_mm3": 0.0, "pass": true}, "40": {"pad_top_z": -51.0, "desk_underside_z": -51.0, "full_nut_engagement": true, "knob_clear": true, "pad_desk_overlap_mm3": 0.0, "pass": true}, "55": {"pad_top_z": -66.0, "desk_underside_z": -66.0, "full_nut_engagement": true, "knob_clear": true, "pad_desk_overlap_mm3": 0.0, "pass": true}}|
|Rig slots independent|PASS|Two 44x7 slots centred X=136 at Y=32/52; clamp bolts at Y=18/66|
|Bearing insertion/removal|PASS|Both 7.2 mm pockets open from hub side faces; supports separate after M8 removal|
|Pivot fastener access|PASS|Bolt head and nyloc remain outside Y=8..76 tower envelope|
|Electronics access|PASS|Four-screw top cover removes without pivot disassembly; rear USB opening and front Hall cable route|
|Printed fit readiness|REVIEW|Bearing, M8/M6, nut, and magnet fits remain coupon-dependent|
|PETG structural capacity|REVIEW|No pseudo-FEA or printed-material safety factor; progressive physical testing required|

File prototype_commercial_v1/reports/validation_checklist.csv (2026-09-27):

check | status | classification | evidence
All exported solids valid | PASS | CAD VERIFIED | 18/18 valid
Bearing axial alignment | PASS | CAD VERIFIED | Both 608 rings and M8 pivot share X=58, Z=76; bearing faces Y=29..36 and 52..59
Pivot stack width | PASS | CAD VERIFIED | 34 mm frame gap = 30 mm hub + 2 x 2 mm axial spacers
Spring length increases through pull | PASS | CAD VERIFIED | {"released": 77.02, "mid": 86.49, "full": 95.37}
Magnet distance monotonic | PASS | CAD VERIFIED | [24.553, 18.896, 13.394, 8.483, 6.0]
Ferromagnetic exclusion window | PASS | CAD VERIFIED; MAGNETIC-FIELD TEST REQUIRED | 38 mm wide steel capsule follows magnet arc; nominal magnet half-diagonal 5.79 mm leaves >13 mm radial CAD margin
Motion collision scan | PASS | CAD VERIFIED | No unintended moving/fixed overlap
Clamp 10/25/40/55 mm states | PASS | CAD VERIFIED; CLAMP LOAD TEST REQUIRED | {"10": {"pad_top": -13.0, "desk_underside": -13.0, "thread_engaged": true, "pass": true}, "25": {"pad_top": -28.0, "desk_underside": -28.0, "thread_engaged": true, "pass": true}, "40": {"pad_top": -43.0, "desk_underside": -43.0, "thread_engaged": true, "pass": true}, "55": {"pad_top": -58.0, "desk_underside": -58.0, "thread_engaged": true, "pass": true}}
Structural capacity | REVIEW | PHYSICAL TEST REQUIRED | No qualified material allowables, weld model, fatigue model, or FEA; progressive physical test required
Bend compensation | REVIEW | SUPPLIER QUOTE REQUIRED | Nominal flats use 3 mm inside radius; supplier must apply tooling-specific K-factor/bend deduction

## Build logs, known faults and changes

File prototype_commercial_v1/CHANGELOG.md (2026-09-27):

# Changelog

## P1-C Commercial Alpha

- Preserved P1.0 and recorded SHA-256 baseline.
- Replaced printed chassis with folded steel tray and paired formed side frames.
- Added non-structural brushed-aluminium accents and original tapered lever.
- Integrated protected magnetic window, Hall sled, rear electronics pod, removable steel clamp and rig slots.
- Added manufacturing DXFs, motion/clamp states, mass/load/magnetic calculations, RFQ pack and cost model.
- Froze CAD revision `P1-C-A1` after the visual-reality review.
- Represented the extension spring as a true helical solid, added three lever apertures, aluminium grip trim rings, visible M4 accent hardware, lid screws, frame hardware, and pivot trim.
- Reduced the red part to a short spring guide collar and cleared the Hall sled from the complete magnet arc.
- Kept the right aluminium accent continuous while retaining the non-ferromagnetic steel-frame Hall window; both accents now export as one-piece laser-cut solids.
- Reworked the hidden cable guide as a support-free U-channel with a separate M3 mounting floor; all ten released STLs are watertight after standard vertex welding.
- Generated 18 exact-CAD customer and engineering views plus a render manifest; no generative geometry was used.

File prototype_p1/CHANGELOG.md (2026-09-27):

# P1 changelog

## P1.0-H — 2026-09-26 — exports and verification

- Exported individual STEP/STL parts, assembly/motion/clamp-state STEP files, DXF steel templates, SVG drawings, calculations, machine-readable checks, and 19 renders.
- Round-trip verified 90 files with zero failures; all STLs watertight and all DXFs millimetre-unit.

## P1.0-G — assembly validation

- Verified 75°, 62.5°, and 50° states with no unintended moving/fixed intersections.
- Verified 10/25/40/55 mm desk states, full coupling-nut engagement, knob clearance, and pad contact.
- Confirmed spring length increases 69.76 -> 77.97 -> 85.82 mm.

## P1.0-F — electronics enclosure

- Moved the 50 x 38 x 28 mm removable enclosure into the rear-right bay to eliminate spring-module overlap.
- Added USB opening, Hall cable route, cover, and board envelope.

## P1.0-E — Hall architecture

- Rejected the initial midpoint sensor layout because it could create non-monotonic magnetic distance.
- Moved magnet to 55 mm radius and sensor to the full-pull endpoint.
- Eliminated a detected full-pull magnet-carrier/right-tower interference without notching the structural tower.

## P1.0-D — desk clamp

- Created six clamp parts around a real M10 coupling nut and M10x100 screw candidate.
- Changed overlapping lap joints to non-overlapping butt joints with M6 through-bolts.

## P1.0-C — lever, spring, and stops

- Added drilled 25 x 5 x 280 mm steel lever, printed grip, three-position fixed spring anchor, moving steel anchor, arc-guided M6 stop pin, and two adjustable stop blocks.

## P1.0-B — pivot system

- Added paired towers, 28 mm hub, two open 608 pockets, M8 bore, washers, 13.6 mm inner-race spacer, and removable M8x90 pivot candidate.

## P1.0-A — master skeleton

- Established tagged central parameters, 180 x 84 x 10 mm base, independent rig slots, clamp interface, and two recessed steel backing strips.

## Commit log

2026-09-27 Initial ELKATEB handbrake CAD and prototype package
    [COUPON_608_POCKETS_DEPTH_14.step, COUPON_608_POCKETS_DEPTH_14.stl, COUPON_608_POCKETS_DEPTH_7.step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]
2026-09-27 Document Tunisia magnet and PETG sourcing
